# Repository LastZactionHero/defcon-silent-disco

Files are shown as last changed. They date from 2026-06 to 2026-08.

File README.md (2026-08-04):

# DEF CON Silent Disco Badge

A wearable silent disco. Every badge plays DJ mixes from its own memory
card to your headphones, runs a light show that matches the music, and can
**sync to a friend's badge over infrared** — same song, same moment, lights
flashing together.

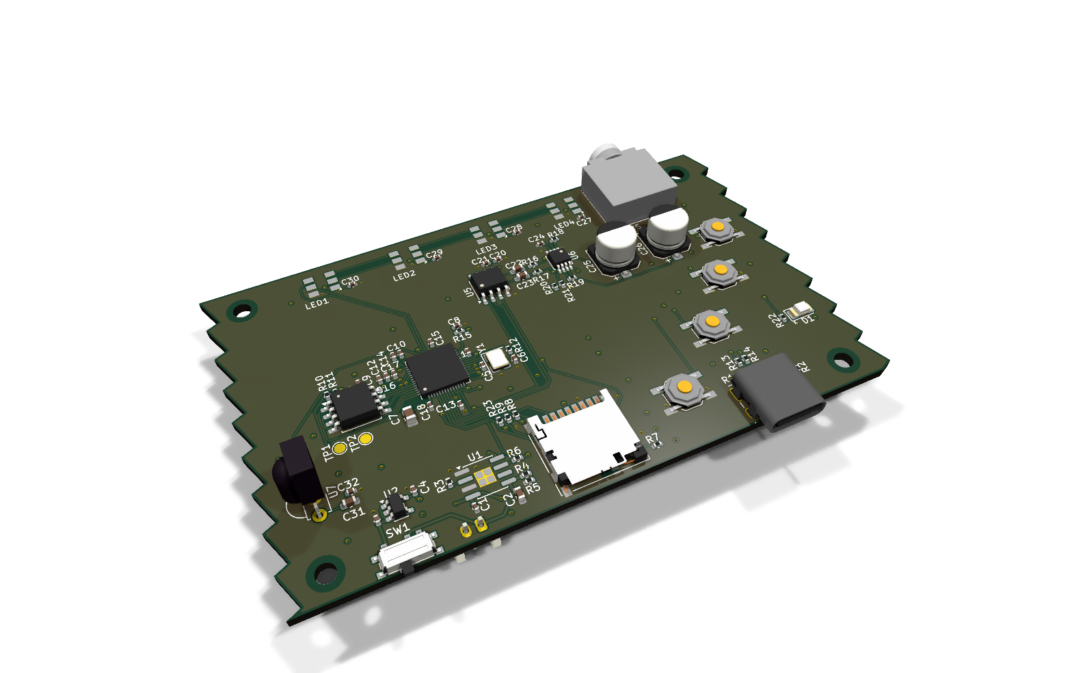
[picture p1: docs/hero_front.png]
Front


## How to use it

1. Flip the **power switch**. Plug **headphones** into the top jack.
2. It starts playing where it last left off.

| Button | Does |
|---|---|
| **CHANNEL** | Next channel. Each channel is one DJ mix that loops forever. |
| **VOL + / −** | Volume, 8 steps. Hold to ramp. Bottom step is mute. |
| **SYNC** | Join a friend — see below. |
| **CHANNEL, held 10 s** | Reset the badge. |

**Syncing:** press SYNC — your music pauses and the badge listens for up to
~25 seconds. Touch your badge's jagged edge into your friend's (they
interlock — that's what the teeth are for) and it will pick up their
broadcast, jump to **their channel at their exact spot**, and both badges
shimmer to confirm. Every badge announces itself over IR every ~10 seconds,
so there's nothing to press on the other badge.

**The light show** is picked by the music: each track gets its own color
theme and animation, and every ~10 seconds the badge plays a short glitter
burst. Synced badges glitter at the same instant.

## If something's wrong

**Red blinking LEDs** are an error code — count which LEDs are lit
(leftmost = 1):

| Code | Meaning | Try |
|---|---|---|
| 1 | No SD card | Reseat the card, power cycle |
| 2 | Card is empty | Put MP3s on it (see below) |
| 3 | Card unreadable | Re-format / re-copy the card |
| 4 | Playback keeps failing | Power cycle; check the battery |

**Sounds distorted, buzzy, or "like a modem"? Swap the battery.** A dying
battery warps the audio and confuses the SD card before anything else —
it looks like a bug, and it never is.

## The SD card

Just MP3 files in the root of the card — nothing else needed:

```
/ElAndEu_Duis.mp3      ← channel 1
/InYourEyes.mp3        ← channel 2
/Sepultura.mp3         ← channel 3   (alphabetical order = channel order)
```

- Encode at **96 kbps CBR, 44.1 kHz stereo** — `firmware/tools/prepare_card.sh`
  does this for you (and matches loudness across mixes).
- The **filename chooses the light show** — rename a file, get new colors.
- A 128 MB card holds about **2 h 54 m** (~29 min × 6 channels).

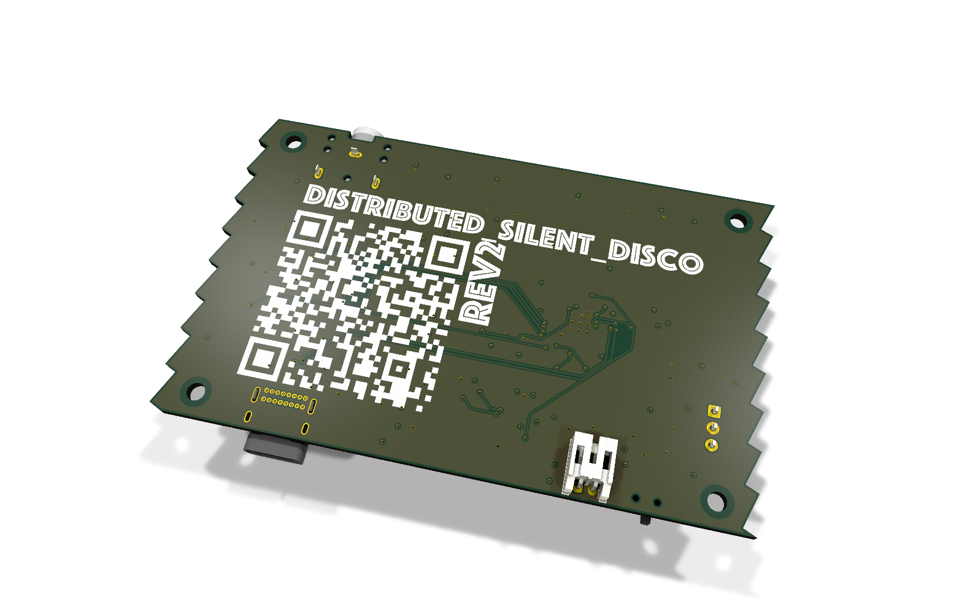
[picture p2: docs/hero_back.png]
Back


## Coming soon

- **Plain MP3-player firmware** — reflash the badge as a normal
  pocket music player (next/prev/pause instead of channels + sync). The
  code exists in this repo; a one-step installer is TODO.
- A **phone app that joins the disco by camera** — the glitter bursts
  encode the channel and timecode, so a phone can watch any badge and
  start playing along. Groundwork is shipped; app is TODO.

## Flashing / updating the firmware

Everything a badge runs is in this repo — [`firmware/`](firmware/) —
including the prebuilt firmware image
[`firmware-mp3-universal.uf2`](firmware/firmware-mp3-universal.uf2)
(one image works on every badge in the run).

**The easy way** (macOS/Linux, needs Python 3 and
[`mpremote`](https://docs.micropython.org/en/latest/reference/mpremote.html)):

```sh
git clone https://github.com/LastZactionHero/defcon-silent-disco.git
cd defcon-silent-disco/firmware
tools/flash_badge.sh        # follow the prompts: plug in, wait for DONE
```

The script does the whole thing — flashes the UF2, installs the badge
software, verifies it, reboots into the disco.

**By hand:** hold **BOOTSEL** while plugging in USB → a drive called
`RPI-RP2` appears → copy the `.uf2` onto it → the badge reboots → then copy
the `.py` files from `firmware/` onto it with `mpremote`. (macOS quirk: use
the script or `dd` — a plain Finder/`cp` copy of a UF2 can silently fail.
The drive *disappearing* is how you know the flash worked.)

Full details, including rebuilding the firmware from source:
[`firmware/README.md`](firmware/README.md).

## Under the hood

RP2040 · MicroPython + native MP3 decoder · 4× addressable RGB LEDs ·
IR sync · sawtooth interlocking edges · USB-C. The full technical story —
firmware architecture, the test suite, build-your-own instructions, and
the bring-up war stories — lives in [`firmware/README.md`](firmware/README.md).
KiCad sources are in [`defcon_badge/`](defcon_badge/), fab files in
[`defcon_badge/fab_rev2.zip`](defcon_badge/fab_rev2.zip).

## Credits

Designed and built by [**Pikkolo Assembly**](https://pikkoloassembly.com/).
Demo mixes are Creative Commons (attribution in `CREDITS.txt` on each
card). MP3 decoding by the Helix decoder via
[picomp3lib](https://github.com/ikjordan/picomp3lib).

MIT licensed — see [LICENSE](LICENSE). Go make a dance floor.

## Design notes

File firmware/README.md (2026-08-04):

# DEFCON Silent-Disco Badge — Firmware

MicroPython + native-C firmware for the RP2040 badge: a **silent disco** —
each badge streams MP3 "channels" from its microSD to headphones, shows a
per-track LED theme + animation, and can **sync channel and playback position
to a neighbouring badge over IR**, so groups dance to the same beat.

> **Read [`BADGE.md`](BADGE.md) for the hardware story** — pin quirks, the
> patched SD driver, and the bring-up findings this code depends on.

## What it does

- Plays **MP3** (96 kbps CBR, the native Helix decoder) from the card root.
  Channel = file, ordered alphabetically. A track **loops**; it never
  auto-advances — changing channel is always a deliberate press.
- **CHANNEL** (GP15): tap = next channel. **Hold 10 s = hard reset** (the
  field escape hatch — no laptop needed).
- **VOL+ / VOL−** (GP14/GP13): 8 steps, 6 dB each, top step −6 dBFS, true
  mute at 0. Auto-repeat when held.
- **SYNC** (GP12): join a neighbour. Playback pauses, the badge listens
  ~25 s for another badge's IR broadcast, then adopts **their channel and
  position** (latency-compensated to ~±70 ms). Times out back to where you
  were. Every badge broadcasts its own (timecode, channel) every 7–13 s.
- **LEDs**: the track *name* hashes to one of 16 themes × 12 animations × 4
  brightness levels (768 looks). Animation phase is locked to the playback
  clock, so **synced badges flash in step and stay in step**.
- **Crash resilience**: channel/position/volume persist to internal flash;
  a brownout resumes mid-set, rewound a few seconds. Faults blink **red
  binary** on the LEDs (LED1 = LSB): 1 = no SD card, 2 = no playable tracks,
  3 = SD mount raised, 4 = playback failing. Every error path stays alive
  and keeps hold-to-reset working.

## Provision a badge (one command)

```sh
tools/flash_badge.sh          # one badge: BOOTSEL → flash → deploy → verify
tools/flash_badge.sh --loop   # the whole pile, badge after badge
```

Flashes `firmware-mp3-universal.uf2` — one image that boots **both** flash
vendors in the manufacturing run (Winbond and Macronix; the custom boot2
discriminates at boot) — then deploys the runtime and verifies imports on
the badge. macOS gotcha handled inside: a plain `cp` of a UF2 **silently
fails**; the script uses `dd` + `sync` and treats *the RPI-RP2 volume
disappearing* as the success signal.

## Prepare a card

```sh
tools/prepare_card.sh "/Volumes/CARD" set1.wav set2.flac set3.mp3
```

Encodes to the shipping format and prints a **preview of each track's LED
look** (the preview imports the real firmware code, so it cannot drift).
Two choices in the recipe are load-bearing — do not "improve" them:

- **CBR**: IR sync seeks by byte offset, which is only linear in time for
  constant bitrate. VBR = everyone syncs to the wrong bar.
- **44.1 kHz**: the DAC has no reconstruction filter; a lower sample rate
  folds ultrasonic images *down toward* the audible band.

Also: EBU R128 loudness normalisation (−16 LUFS) so channel-surfing between
DJs doesn't whiplash, metadata/art stripped, and a 128 MB budget check
(~2 h 54 m total at 96 k). **Track filename = channel order and LED look.**

Got a mix in an app that can play but not export? `tools/record_mix.sh`
captures the Mac's own audio output (loopback via BlackHole) to a lossless
WAV master and encodes the badge MP3 from that.

## Tests

```sh
python3 tools/host_tests.py
```

Runs the **real firmware modules** on the host: the IR ISR + decoder against
synthetic TSOP edges (AGC stretch, mark distortion, measured 60 Hz ambient
noise), CBR seek/wrap math, persistence-slot recovery incl. torn writes,
every LED invariant (no mid-range PWM, ≤1 white/theme, slot determinism,
flash-rate safety), and the volume ladder. Run it before deploying changes.

## Files

| File | Purpose |
|---|---|
| `config.py` | **Pin map + tunables** (single source of truth, with history) |
| `main.py` | Entry point — boots `disco`; alternates commented inside |
| `disco.py` | The silent-disco program (channels, LEDs, sync, persistence) |
| `irsync.py` | IR timecode protocol: NEC-style TX + hard-IRQ RX |
| `wavplayer.py` | Async player engine (MP3+WAV, seek, stall watchdog) |
| `mp3player.py` | Plain player (also: `mount_sd`/`find_tracks` used by disco) |
| `linktest.py` | IR link bring-up tools: `beacon()` / `scope()` / `raw()` |
| `dsp.py` | Viper DSP hot path (volume + LSBJ reframe + peak) |
| `sk9822.py` | Bit-banged SK9822 LED driver (viper/SIO fast path) |
| `buttons.py` | Debounced buttons: auto-repeat + tap/hold semantics |
| `sdcard.py` | **Patched** SD-SPI driver (CMD8-glitch workaround) |
| `audiolab.py` | Audio diagnostics (tone/sweep/ZEROS/CLKOFF/FREQ modes) |
| `jukebox.py`, `lights.py`, `selftest.py` | Earlier player + LED modes + HW test |
| `tools/flash_badge.sh` | One-command badge provisioning (`--loop` for batches) |
| `tools/prepare_card.sh` | Mix → badge-format MP3 + look preview + budget check |
| `tools/record_mix.sh` | Record the Mac's audio output to badge format |
| `tools/host_tests.py` | Host regression suite (real modules, no hardware) |
| `tools/card_preview.py` | LED look preview for a set of filenames |
| `tools/build_firmware.sh` | Rebuild the firmware UF2 (MP3 module + boot2) |
| `boot2/` | Custom second-stage bootloaders (universal + Macronix) |
| `cmodules/mp3/` | Native MP3 decoder C module (Helix / picomp3lib) |

## Recovery / field notes

- **Sounds like a modem / horrible hum, or the card stops reading?  Fresh
  battery first.**  A sagging AAA amplitude-modulates the DAC (its output is
  ratiometric to the rail) and breaks SD init -- both look exactly like
  firmware bugs.  USB power masks it, so a badge that "tests fine on the
  laptop" can still be a dead battery.  Pack spares.
- **Hold CHANNEL at power-on** → skip autostart, drop to the REPL.
- **Hold CHANNEL 10 s while running** → hard reset (works on error screens too).
- Red binary blink = error code (see above). Code 1: reseat the SD card.
- `mpremote` cannot take the REPL while audio is decoding — send **one**
  Ctrl-C over raw serial first, or power-cycle, then deploy. (Spamming
  Ctrl-C mid-playback has wedged boards.)
- Rebuilding the UF2 needs the **xPack** ARM toolchain on PATH first —
  Homebrew's `arm-none-eabi-gcc` has no newlib and fails at boot2 link:
  `export PATH="$HOME/dev/xpack-arm-none-eabi-gcc-14.2.1-1.1/bin:$PATH"`

## Known limitations / respin notes

- **Writes to SD are unproven** — state persists to *internal* flash instead;
  treat the card as read-only in the field.
- **No MISO pull-up** fitted: the schematic's R8/R9/R23 pull-ups terminate on
  a mis-named power net (`+3.3V` vs `+3V3`) with no source. One symbol rename
  fixes it next spin; until then SD SPI stays at the verified 4 MHz.
- **No DAC reconstruction filter** → the supply-buzz floor, and the reason
  encoding stays at 44.1 kHz. Next spin: series R + shunt C on each DAC
  output, and a local bypass at the TDA1308 (it has none).
- **IR range is short by construction**: the emitter is ~13 mA straight off a
  GPIO (12 mA pad drive recovers the design current). A transistor driver at
  100 mA+ next spin would give real range. Badges sync reliably at
  face-to-face distances; the jagged board edges interlock to align
  emitter↔receiver.
- **276 MHz overclock** (RP2040 is rated 133 MHz) is load-bearing for MP3
  decode *and* chosen for audio-noise pitch; verified stable on the bench
  units. `250_000_000` is the tested fallback if a unit is flaky.
- The VM freezes during internal-flash writes (XIP suspend) and the ~68 ms
  IR send — the firmware spaces them apart and the emit watchdog logs any
  >150 ms gap with blame, so a stutter report is diagnosable from the console.

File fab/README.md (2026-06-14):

# Fabrication package — DEF CON silent disco badge

## Spec at a glance
- **Outline:** 86 × 54 mm, 3 mm rounded corners (credit-card form factor)
- **Layers:** 4-layer (F.Cu, In1.Cu = GND, In2.Cu = +3V3, B.Cu)
- **Components:** 80 SMD + THT, all on F.Cu (top side)
- **Hole sizes:** see `gerbers/defcon_badge.drl` (Excellon)
- **Mounting:** 4× M2.5 holes (2.7 mm dia) at corners
- **Connectors:** USB-C (J10), JST-PH 2 mm battery (J11), 3.5 mm audio jack (J20), microSD (J31 — currently off-board, pending iter 11 layer flip), SAO 2×3 (J30), Dev/SWD 1×5 (J33), UART 1×3 (J32)
- **Hero parts:** RP2040 (U3), 4× SK9822 RGB LEDs (LED20-23), TP4056 charger + ME6211 LDO, TM8211 DAC + FDA1308 headphone amp, TSOP4838 IR receiver + 940 nm IR LED

## Files
- `gerbers/` — Gerber RS-274X for all layers + Excellon drill file
- `defcon_badge-pos.csv` — pick-and-place position file (KiCad format, mm)
- `defcon_badge-bom.csv` — grouped BOM with MPN + LCSC where assigned

## Caveats
This package was generated mid-iteration by the autonomous design loop
(see `HARNESS.md`). Known gaps before fab:
- No copper routing yet — all nets are unconnected ratsnest. The board
  is currently a parts-placed PCB. Routing pass (auto or hand) required.
- ERC reports ~71 schematic violations (mostly `label_dangling`,
  `power_pin_not_driven`, off-grid endpoints). Most are cosmetic /
  pre-PWR_FLAG issues, none change topology, but DRC will refuse fab
  until cleared.
- J10 USB-C pads carry no net assignments — they sit in the PCB as a
  raw footprint. Iter 14+ will wire them.
- J31 microSD remains off-board (no front-side space; iter 11 plans
  layer-flip to B.Cu).

## Regenerating
```sh
tools/render_pcb.sh                    # SVG/PNG renders to renders/
kicad-cli pcb export gerbers ...       # see Makefile or this README
```

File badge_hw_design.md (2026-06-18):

# Silent Disco Badge — Hardware Design v0.1

Target: ~$2.50 BOM ex-battery/SD at qty 500. 2-layer, standard spec (8/8 mil floor — stays in APCT standard pricing). Single-sided placement if layout allows; buttons and switch are the only things fighting for the front.

---

## Power tree

```
USB-C 5V ──→ TP4056 ──→ BAT+ (503450 LiPo, protected cell)
                              │
                        SS-12D00 slide switch
                              │
                          ME6211C33 ──→ 3V3 rail (everything)
```

- **TP4056** (ESOP-8, LCSC C16581): RPROG = 2.4 kΩ → 500 mA charge (0.5C on 1000 mAh). CE tied high. CHRG̅ (pin 7) → GP18 via 100k pullup to 3V3 so firmware can show charge state on the LEDs — no dedicated status LEDs.
- **Protected cell** — skip DW01/FS8205, the cell's PCM covers it.
- No load-sharing path. System always runs off the battery node; charging-while-playing slightly confuses TP4056 termination. Acceptable for a badge; note in docs "charges fastest when off."
- **ME6211C33M5G** (SOT-23-5, C82942): 1 µF in/out. 500 mA rated, system peak ~150 mA, fine.
- **VBAT sense:** 100k/100k divider → GP26/ADC0. Always connected; 16 µA standing drain is negligible vs self-discharge.
- **USB-C:** 16-pin mid-mount (e.g. GCT USB4520 or HQB equivalent TYPE-C-31-M-12). 5.1 kΩ on each CC to GND (UFP). VBUS → TP4056 only — do not feed VBUS to the 3V3 rail.

## RP2040 core

- **RP2040** (C2040) + **W25Q16JVUXIQ** 2 MB QSPI flash (C2843335). 2 MB is plenty: firmware + channel table; all audio lives on SD.
- **Crystal:** 12 MHz 3225, stock tolerance (software trim handles drift), 15 pF load caps, 1 kΩ series resistor per the RP2040 hardware design guide.
- VREG_VIN ← 3V3, VREG_VOUT → DVDD pins with 1 µF. 100 nF at every IOVDD pin, 1 µF bulk ×2.
- USB D+/D− through 27 Ω series resistors to the connector. No external pullups (internal).
- RUN: 10 kΩ to 3V3. No reset button.
- **BOOTSEL button:** tactile from flash CS to GND via 1 kΩ, back side of board. Needed for first flash and unbrick; after that, track loading is USB MSC so users never touch it.

### GPIO map

| GPIO | Function | Notes |
|---|---|---|
| GP0/GP1 | UART0 TX/RX | debug header, 3-pin |
| GP2 | SD SCK | SPI0 |
| GP3 | SD MOSI | SPI0 |
| GP4 | SD MISO | SPI0 |
| GP5 | SD CS | |
| GP6 | I2S DIN → DAC | PIO0 |
| GP7 | I2S BCK | PIO0, keep 6/7/8 contiguous for PIO side-set |
| GP8 | I2S WS (LRCK) | PIO0 |
| GP9 | IR_TX | via S8050, 68 Ω, 38 kHz PIO carrier |
| GP10 | LED SCK | SPI1, SK9822 clock |
| GP11 | LED MOSI | SPI1, SK9822 data |
| GP12 | BTN_CH | internal pullup, switch to GND |
| GP13 | BTN_VOL_UP | " |
| GP14 | BTN_VOL_DN | " |
| GP15 | IR_RX | TSOP output, active low |
| GP16 | SAO SDA | 4.7k pullups |
| GP17 | SAO SCL | " |
| GP18 | CHRG̅ sense | from TP4056 |
| GP19 | BTN_SYNC | internal pullup, switch to GND |
| GP26 | ADC0 VBAT | 100k/100k divider |

## Audio chain

```
RP2040 PIO I2S → TM8211 DAC → 10µF coupling → TDA1308 → 220µF coupling → PJ-320A jack
```

- **TM8211** (SOP-8) — the Shenzhen PT8211 clone, rated 2.0–5.5 V so it's happy at 3.3 V. **Do not sub a genuine PT8211 without checking — PT8211 datasheet wants ~5 V.** TM8211 takes LSBJ-format 16-bit I2S (justified, not standard I2S — firmware note: PIO program shifts WS timing by one BCK vs standard I2S).
- 100 nF + 10 µF decoupling at DAC Vcc.
- **TDA1308** (SOP-8) headphone amp, runs at 3.3 V:
  - Inputs: 10 µF coupling caps from DAC outs, 47 kΩ input resistors.
  - Gain: 100 kΩ feedback / 47 kΩ input ≈ 2.1×. Loudness headroom is the flagged risk — leave feedback Rs as discrete 0402s so gain is a resistor swap, not a respin.
  - Virtual ground: 10k/10k divider + 10 µF to the VREF pin.
  - Outputs: **220 µF / 6.3 V** electrolytic or large MLCC per channel to the jack. 220 µF into 32 Ω → −3 dB at 23 Hz; into cheap 16 Ω buds → 45 Hz. Don't cheap to 100 µF; this is a disco.
- **PJ-320A** 3.5 mm TRRS-style SMD jack — wire as TRS stereo, leave sleeve-detect unconnected.
- Layout: keep DAC/amp and their ground pour away from the SK9822 data lines and the IR LED driver (30 mA pulsed bursts); star the audio ground back at the LDO.

## Optical tap-to-sync (replaces RF)

Badges sync by touching face-to-face. No radio — at DEFCON specifically, any unauthenticated RF beacon **will** be spoofed for sport within the hour, and signing packets drags crypto/key management onto a $5 badge. Physical contact is proximity-authenticated for free, and the social mechanic ("we drifted — tap me") is the feature.

- **Link:** 940 nm IR LED + **TSOP4838**-class 38 kHz demodulating receiver (~$0.22 pair + driver). Not a bare photoresistor/phototransistor: LDRs are far too slow (tens of ms), and a bare PT makes you own the analog ambient-rejection problem in a room full of strobes. The TSOP is IR-remote tech — carrier-filtered, AGC'd, bulletproof, trivial firmware (NEC-style bursts).
- IR LED driven by S8050/2N7002 from **GP9**, 68 Ω → ~30 mA pulsed. TSOP out → **GP15** (active low).
- **Placement:** LED and receiver mirror-symmetric about the badge's vertical centerline, front face, so two badges pressed face-to-face cross-align LED↔receiver automatically in both directions. Badges themselves shade the link from ambient at contact.
- **Protocol:** every badge chirps `{version:u16, epoch_ms:u48, table_hash, CRC}` (~12 B, NEC-style framing, TSOP AGC needs burst gaps) every ~2 s. Hearing a higher version → adopt clock + version, pulse the SK9822s in unison with the peer — that shared flash is the sync confirmation and the moment of delight. No button, no mode: touch = sync.
- **Same-version contact → average the two clocks** (slew-limited to ±150 ms per contact so a hacked badge can't yank the network). This is what makes peer taps *maintain* sync between staff passes — pairwise averaging is a consensus algorithm; clusters that tap converge to their mean. Without this, only organizer contact corrects drift.
- **Software drift trim:** on repeat contact with the same peer (or any correction event), estimate own ppm error from accumulated offset and trim the tick rate. Two taps gets a badge from ±30 ppm to single digits — makes the ±10 ppm crystal optional rather than required.
- **Root of trust:** a couple of organizer badges are the only ones that increment `version` (long-press combo). Everyone else propagates. Staff circulating keeps the room coherent.
- **Drift budget (be honest about this):** stock 20–30 ppm crystals → up to ~200 ms relative drift/hr between two badges worst case, but software ppm trim calibrates out static offset after 2–3 taps, leaving only temperature drift (small indoors). Stock crystal is fine — don't pay for tighter tolerance; trim fixes what tolerance specs, and nothing cheap fixes tempco. Flash sync is cluster-coherent — groups that tap each other stay locked, which is the aesthetic anyway. Friends pulse together.

## LEDs

- **4× SK9822 (5050)**, chained, SPI1 clock+data. (Switched from the on-hand EC20 2020 to the larger 5050 for a brighter, more decorative disco look — see PCB footprint badge:LED_SK9822_5050, datasheet-verified pinout 1=DIN 2=CIN 3=GND 4=VDD 5=COUT 6=DOUT.) 5 V part driven at 3.3 V logic and 3.3 V supply — SK9822 runs visibly fine at 3.3 V supply with slightly shifted color balance; data threshold is met since VDD = logic rail. ~10 nF per LED.
- Brightness budget: global brightness register capped at ~25% in firmware. 4 LEDs full white at 3.3 V would eat the battery and blind people at eye level on a lanyard.

## Buttons / switch

- 4× **TS-1187A** 6 mm tactile (CH / VOL+ / VOL- / SYNC; silkscreen labels), to GND, internal pullups. Front face, 2×2 grid (CH·SYNC top, VOL+·VOL- bottom) — a single row of 4 doesn't fit between USB-C and the corner mounting hole.
- 1× **MSK-12C02 / SS-12D00** slide power switch.
- 1× BOOTSEL tactile, back side.

## SAO header

- Standard SAO v1.69: 2×3 female header, 3V3 / GND / SDA / SCL / GPIO×2 → use GP20/GP21 for the two SAO GPIOs (add to GPIO map). Costs a connector, buys DEFCON cred.

## Connectors summary

USB-C 16P · PJ-320A · microSD push socket (e.g. TF-PUSH, ~$0.10) · JST-PH 2-pin for battery · SAO 2×3 · 3-pin debug UART (unpopulated).

---

## BOM (qty 500, est.)

### Active / connectors / electromech

| Ref | Qty | Part | Package | Est. |
|---|---|---|---|---|
| U1 | 1 | RP2040 | QFN-56 | $0.80 |
| U2 | 1 | W25Q16JVUXIQ 2 MB QSPI flash | USON-8 | $0.20 |
| U3 | 1 | TM8211 stereo DAC (PT8211 clone, 2.0–5.5 V) | SOP-8 | $0.15 |
| U4 | 1 | TDA1308 headphone amp | SOP-8 | $0.25 |
| U5 | 1 | TP4056 Li-ion charger | ESOP-8 | $0.08 |
| U6 | 1 | ME6211C33M5G LDO | SOT-23-5 | $0.03 |
| U7 | 1 | IRM-H638T / TSOP4838-class 38 kHz IR RX | side-view | $0.15 |
| Q1 | 1 | S8050 NPN (IR LED driver) | SOT-23 | $0.01 |
| D1 | 1 | 940 nm IR LED | 0805 side-fire | $0.02 |
| LED20–23 | 4 | SK9822 | 5050 | switched from EC20 2020 for brightness |
| Y1 | 1 | 12 MHz crystal, stock tol. | 3225 | $0.08 |
| J1 | 1 | USB-C 16P mid-mount | — | $0.10 |
| J2 | 1 | PJ-320A 3.5 mm jack | SMD | $0.08 |
| J3 | 1 | microSD push socket | — | $0.10 |
| J4 | 1 | JST-PH 2P (battery) | SMD RA | $0.04 |
| J5 | 1 | SAO 2×3 female header | THT | $0.06 |
| J6 | 1 | debug UART 1×3 | THT | DNP |
| SW1–3 | 3 | TS-1187A tactile (CH, V+, V−) | SMD | $0.09 |
| SW4 | 1 | BOOTSEL tactile | SMD | $0.01 |
| SW5 | 1 | MSK-12C02 slide power switch | SMD | $0.03 |

### Passives (0402 unless noted)

| Value | Qty | Where |
|---|---|---|
| 27 Ω | 2 | USB D+/D− series |
| 68 Ω | 1 | IR LED current set |
| 1 kΩ | 3 | crystal series, BOOTSEL, Q1 base |
| 2.4 kΩ | 1 | TP4056 PROG (500 mA) |
| 4.7 kΩ | 2 | SAO I2C pullups |
| 5.1 kΩ | 2 | USB-C CC |
| 10 kΩ | 3 | RUN pullup, amp vground divider ×2 |
| 47 kΩ | 2 | amp input |
| 100 kΩ | 5 | amp feedback ×2, VBAT divider ×2, CHRG̅ pullup |
| 15 pF | 2 | crystal load |
| 10 nF | 4 | SK9822 local |
| 100 nF | 10 | IOVDD ×6, DAC, TSOP, TP4056, misc |
| 1 µF | 5 | VREG, DVDD, LDO in/out, bulk |
| 10 µF | 6 | DAC bulk, DAC→amp coupling ×2, vground, charger in/out |
| 220 µF 6.3 V | 2 | headphone output coupling (electrolytic) |

### Rollup

| Group | Est. |
|---|---|
| ICs | $1.66 |
| Connectors | $0.38 |
| Electromech (buttons/switch) | $0.13 |
| Crystal | $0.08 |
| Passives | ~$0.25 |
| **Board parts subtotal** | **~$2.50** |
| 503450 1000 mAh protected LiPo | $1.80 |
| 512 MB–1 GB bulk microSD | $0.70 |
| **All-in (ex-PCB)** | **~$5.00** |

~58 placements, 15 unique passive values, all 0402-or-larger / SOP / SOT — deliberately easy on the Lumen line. Only THT items are the SAO header and (optional) battery connector and debug UART.

Verified LCSC C-numbers: RP2040 C2040, W25Q16 C2843335, TP4056 C16581, ME6211C33 C82942. Everything else — verify at order time, don't trust from memory.

---

## v1 validation order (before layout freeze)

1. **Audio pipeline on a Pico + TM8211 breakout:** minimp3 decode of 192k CBR + SPI SD streaming + PIO I2S, both cores. This is the only real firmware risk.
2. **TDA1308 loudness** into 16 Ω earbuds at 3.3 V, gain 2×. If quiet, bump gain to 3–4× and check clipping.
3. **IR tap link:** two Picos + TSOP/IR LED pairs face-to-face — confirm clean decode at contact and ~2 cm, confirm rejection with a strobe pointed at it. Then measure real crystal drift between two boards over 2 hrs to size the re-tap interval honestly.
4. SK9822 at 3.3 V supply — confirm acceptable color at 25% brightness.

## Layout notes

- Badge outline is free real estate — front face: 4 buttons (2×2 grid) bottom edge, jack top or bottom edge (cable hangs down → bottom), LEDs spread across front, art everywhere else.
- All silicon on back except LEDs if you want a clean front. Single-side placement target: put LEDs on back firing through FR4 windows? No — reverse-mount adds cost; two-side placement is fine, it's your own line.
- IR LED + TSOP front face, mirror-symmetric about vertical centerline (face-to-face mating cross-aligns them). Audio lower left, USB/charge lower right, SD back center.

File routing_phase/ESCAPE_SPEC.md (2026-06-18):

# ESCAPE_SPEC — QFN escape planner (R3, the central new tool)

`routing_phase/tools/escape_planner.py`. The phase that never existed in pass 1. Escapes every
QFN signal pin to OPEN space outside the pin field BEFORE bulk routing — so via_in_pad==0 by
construction and the bulk router starts from a relieved ring, not a jammed pad field.

## Proven foundation (de-risking result, 2026-06-18)
KRT's `qfn_fanout` (shipped, never used in pass 1) escaped all **43** U3 signal pads with **0 vias**
(escapes on the mounted F.Cu layer, two-segment 45° stubs, side-classified bottom 12/left 8/right 11/
top 12, "No endpoint collisions"). Applied via `krt_bridge` → **via_in_pad==0** confirmed.

**The residual it surfaced — and the reason escape_planner is more than a qfn_fanout wrapper:** at
0.40mm pitch the single-layer 45° fan stubs sit only ~0.283mm apart (pitch/√2) → with 0.15mm tracks
the gap is ~0.133mm < the 0.15mm clearance rule → **54 clearance DRC errors**. One layer cannot hold
43 escapes at this pitch. qfn_fanout's own note: "route.py --grid-step 0.05 --clearance 0.05 ... the
default will fail." So escape_planner must SPREAD ACROSS LAYERS.

## Design: multi-layer alternating escape (the fix)
Halve the per-layer escape density so adjacent same-layer stubs clear the 0.15mm rule.
- Per side, walk pads in index order and ALTERNATE escape layer: even pads escape on **F.Cu**
  (qfn_fanout direct stub, no via), odd pads escape via a **B.Cu dog-bone** (short F.Cu stub off the
  pad → off-pad via in the empty annulus → B.Cu stub outward). This doubles per-layer pitch to
  ~0.566mm → ~0.416mm gap > 0.15mm → DRC-clean.
- The off-pad via stays via_in_pad-free (via is in the open annulus, never on the pad). Placement is
  EASY because escape-first runs on EMPTY copper (the annulus is clear — pass 1's congestion was
  caused by routing INTO a filled field; here there's nothing to collide with).
- Power/GND QFN pads (+3V3/+1V1/GND) are NOT escaped here — they drop straight to their plane in R6
  fanout (excluded via `--nets "*" "!GND" "!+3V3" "!+1V1"`). The EP and its 9 GND vias are untouched.
- MONOTONE ordering per side (no two same-layer escapes cross; preserve pad order at the ring) — this
  is what makes it read hand-designed.

## Algorithm
1. Run KRT `qfn_fanout.py --component U3 --layer F.Cu --width 0.15 --clearance 0.15 --nets <F.Cu set>`
   for the EVEN pads → KRT-format board; `krt_bridge.extract_routing` → F.Cu escape tracks.
2. For the ODD pads, build B.Cu dog-bones directly on `geom_route`: F.Cu stub pad→via_pos (short,
   along the outward radial), `add_via` at via_pos (validated clear by the `_pt_clear`/`_seg_dist`
   geometry check — reused from the deleted fix_signal_vias as a reference helper), B.Cu stub
   via_pos→ring-exit. Sweep radius in the empty annulus until clear (nearly always first try).
3. Apply ALL escapes via `krt_bridge.apply_routing`/`geom_route` (pcbnew writer), one save.
4. Emit `escape_plan.json`: per pin {refdes_pin, net, native_side, escape_layer, mode: vialess|dogbone,
   via:[x,y]|null, escape_point:[x,y,layer]}. This is the HAND-OFF CONTRACT to R4/R5 — the bulk router
   uses `escape_point` as the net's effective source terminal and never touches the pad field again.
5. Reserve a KEEPOUT ring (a `(keepout (vias not_allowed))` rule area around U3 out to ~r_outer) so R6
   plane fanout can't re-fence the escapes.

## Inputs / guardrails
- Read via `geom_route.safe_board`; design rules from the netclass (don't hardcode); single-writer.
- Does NOT route to destinations (only to the ring). Does NOT touch the EP/planes' fill. Never places
  a via that HitTests a pad (the invariant). One LoadBoard+SaveBoard (pcb_runner).
- Also escape the microSD J31 and any other dense connector the same way if it blocks (start with U3).

## Exit gate (R3): every QFN signal pin escaped to open space; via_in_pad==0; escapes DRC-clean
(multi-layer); no signal on an inner plane; determinism passes; render shows a clean radial pattern.

## Tuning fallbacks (the R3 escalation ladder)
qfn_fanout-multilayer → manual escape-corridor seeding (hand-place a few hard stubs) → push to R2
GPIO remap (move the pin so it doesn't need a cross-side escape) → hand-off. Also: if 0.4mm pitch is
truly too tight even multi-layer, route the QFN-local nets with `route.py --grid-step 0.05
--clearance 0.05 --track-width 0.15` (qfn_fanout's own suggestion) scoped to just U3's nets.

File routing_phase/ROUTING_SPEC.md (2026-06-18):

# ROUTING_SPEC — Pass-2 architecture (escape-first, KRT-full-toolbox)

How the pass-2 system works. The big change vs pass 1: PLAN before ROUTE, and invoke KRT's
existing escape/bus/aesthetic capabilities instead of rebuilding them.

## Architecture
```
  geom_route (pcbnew authoritative copper) ──► measure_route (DRC-backed metrics) ──► gates
       │              ▲
       ▼              │
  route_db (incremental, stable pad-set signature)
       │
  PLAN (Workflow, run once) ───────────────────────────────► EXECUTE (loop)
    R2 gpio_reassigner  (crossing-min, schematic, approval)     R5 bulk singleton route + beautify
    R3 escape_planner   (qfn_fanout + B.Cu dogbones)            R6 plane fanout LAST + pour + verify
    R4 bus_topology_planner (chip_boundary/bus_detection)
       └─ emit escape_plan.json / bus_plan.json / gpio_remap.json (frozen artifacts)
                                          │
                                          ▼ (KRT = solver only; pcbnew = sole writer)
                          krt_bridge: KRT solves → extract (KRT kicad_parser) → re-apply via pcbnew
```

## KRT full-toolbox integration map (the pass-1 "missing tools" that already exist)
Run KRT via the venv; reach output ONLY through `krt_bridge` (KRT writes net NAMES, KiCad 10 needs
CODES). All KRT runs single-thread/deterministic.
- **Escape (R3):** `qfn_fanout.py --component U3 --layer F.Cu --width 0.15 --clearance 0.15 --nets
  "*" "!GND" "!+3V3" "!+1V1"` → 0-via on-layer escapes (PROVEN). escape_planner adds the B.Cu dogbone
  for the alternate pads (ESCAPE_SPEC).
- **Bus/topology (R4):** `bus_detection.py` (group nets into buses), `chip_boundary.py` (perimeter
  unroll → crossing-minimal order: two nets cross iff source/target orderings invert), and
  `route.py --bus --guide-corridor --guide-corridor-layer/-spacing` → constant-pitch bundles.
- **Aesthetics (R5):** the Rust `grid_router` knobs — `--turn-cost` (straighter), `--via-cost`/
  `--via-proximity-cost` (fewer/structured vias), `--track-proximity-*` (consistent spacing),
  cross-layer track attraction (stack traces on adjacent layers). Pass 1 ran defaults.
- **GPIO remap (R2):** `chip_boundary.py` to score crossings; Hungarian assignment (as in KRT
  `target_swap.py`); write back via KRT `schematic_updater.py` + `--swappable-nets`/`--schematic-dir`.
- **Bulk (R5):** `route.py` with the aesthetic knobs + `--rip-existing-nets PATTERN` (SMALL sets only;
  global rip-up is pathologically slow on this board). At 0.4mm-pitch QFN-local nets use
  `--grid-step 0.05 --clearance 0.05`.
- Do NOT use `route_planes.py`/`route.py` to place vias on pads (the pass-1 via-in-pad source) — and
  do NOT use KRT's writer.

## Pipeline (route_pipeline.py = a phase DAG, not the old flat chain)
R0 setup → R1 stackup → R2 gpio (opt) → **R3 escape** → **R4 bus** → R5 bulk singletons → R6 plane
fanout LAST + pour. Each stage: pcb_runner-isolated, records into route_db, independently re-runnable.
The old order (plane-fanout-then-bulk, no escape, bus lumped in bulk) is the structural flaw being
fixed — plane fanout MOVED TO LAST is the single most important change.

## Metric engine (measure_route.py — KEPT; fill the existing None placeholders)
Already emits: completion_pct (vs frozen baseline.json), unconnected + divergence guard, shorts,
drc_errors + drc_by_type, track/via counts + per-layer length, **via_in_pad** (HitTest), usb skew/
paired, acute_angles, off_axis_segments, zones_filled_ok. NEW tools fill the placeholders:
bus_pitch_var (R4), determinism_ok (route-twice). Per-phase PRIMARY metric declared in STATE.md
(R3: via_in_pad + escaped-pin count; R4: bus_pitch_var; R5: completion_pct).

## Incremental model (route_db.py — KEPT)
Nets keyed by stable pad-set signature (sorted REFDES-PADNUM, not the churning net name). A GPIO
remap (R2) changes the signature only for moved nets → only those re-escape/re-route. Determinism
gate = route-twice → identical fingerprint.

## Determinism + aesthetics are first-class
Route-twice gate wherever copper exists. Because escape (R3) and buses (R4) are PLANNED before bulk,
the structured-via + constant-pitch look is baked in — there is no "aesthetic pass at the end" to skip.

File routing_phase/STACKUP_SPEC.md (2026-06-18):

# STACKUP_SPEC — D1 4-layer rework (committed BEFORE implementation)

The board is 4-copper but everything physical is a **2-layer RP2040 dev-board porting artifact**:
thickness 1.0mm, NO real stackup/dielectric block, In1=full GND + In2=full +3V3 copied from the
dev board, a loose F.Cu GND zone with no B.Cu counterpart, all 3 zones unfilled. The user
directed reworking this. Do it as a tool: `routing_phase/tools/rework_stackup.py` (pcbnew,
single-writer). Numbers below are from the engine-architecture research (JLCPCB published
JLC04161H-3313 data + Hammerstad/IPC-2141 microstrip; verify USB width in JLC's calculator at order).

## Target stackup — JLC 4-layer 1.6mm (JLC04161H-3313)
| Layer | Assignment | Copper | Dielectric to next |
|---|---|---|---|
| F.Cu  | signal + GND fill (USB pair, most signals) | ~1oz fin. | 3313 prepreg **0.0994mm**, Dk 4.1 |
| In1.Cu | **solid GND plane, unbroken** (return reference for both signal layers + USB) | 0.5oz | FR-4 core **1.265mm**, Dk 4.6 |
| In2.Cu | **+3V3-dominant pour** + a little slow signal where F/B congests | 0.5oz | 3313 prepreg **0.0994mm**, Dk 4.1 |
| B.Cu  | signal + GND fill (near-empty today → secondary signal layer) | ~1oz fin. | — (board ≈1.6mm) |

Rationale: In1 solid GND is the reference that matters (return current + USB). In2 as a full +3V3
plane is wasteful (only 47 +3V3 pads, ~150mA, ME6211 rated 500mA, local decoupling at each IC) —
demote it to a +3V3-dominant *mixed* pour that doubles as routing relief, but keep +3V3 continuous
under U3 (RP2040), U2 (flash), U11 (LDO). F.Cu/B.Cu GND pours stitched to In1 give shielding/return.

## Zone plan (after deleting the 3 artifact zones)
- **In1.Cu**: GND, full solid plane, outline inset ~0.3mm (min copper-edge clearance), priority 0.
- **In2.Cu**: +3V3 dominant pour over the digital/power region, priority 0; + optional secondary
  GND pour priority 1 in +3V3-free areas (return stitching).
- **F.Cu**: GND pour in routing gaps, priority 0, stitched to In1.
- **B.Cu**: GND pour in routing gaps, priority 0, stitched to In1.

## Impedance / widths
- **USB D+/D-** (the ONLY controlled-impedance net): edge-coupled microstrip on F.Cu over In1 GND
  through the 0.0994mm 3313 prepreg → **width 0.17mm, gap 0.13mm** ≈ 89Ω diff (0.15mm gap ≈ 91.5Ω).
  Replace the stored 0.8mm (a 2-layer value). Keep tightly coupled, length-matched, over solid In1
  GND with NO plane split under the pair; the two 27Ω series Rs (R3/R4) stay in-line.
- **Default signal 0.15mm** over In1 GND ≈ 55Ω single-ended — fine for QSPI/I2S/SK9822/SD/etc.
  (no controlled impedance required). No change except USB.
- Power widths: see `routing_rules.md` (VBUS/BAT/BAT_SW 0.5mm, IR drive 0.3mm, +1V1 0.3mm, audio
  output 0.3mm; +3V3/GND ride planes via taps).

## Rework steps (rework_stackup.py — pcbnew, writer-lock-guarded)
1. Set board thickness 1.0→1.6mm (`SetBoardThickness(pcbnew.FromMM(1.6))` or setup thickness).
2. Write a real physical stackup block for JLC04161H-3313 with the dielectric heights/Dk above.
   (Hand-writing the stackup via the Python API can trip the wx PROPERTY_ENUM asserts — prefer the
   board-setup preset if interactive; otherwise write the `(stackup ...)` block carefully and verify
   the board still loads via `kicad-cli pcb drc`.)
3. In `(layers ...)`, set In2.Cu type to `mixed` (was power "+3V3"); keep In1.Cu as power "GND".
4. Delete the 3 artifact zones (`for z in list(b.Zones()): b.Remove(z)` — lossless, all unfilled).
5. Recreate zones per the zone plan (polygons = board outline inset ~0.3mm).
6. Fix the USB_DIFF_90 netclass in `defcon_badge.kicad_pro`: change the patterns from the
   non-existent `/USB_D+` `/USB_D-` to the REAL nets `/MCU_Core/USB_DP`, `/MCU_Core/USB_DM` (and
   add the connector-side `Net-(U3-USB_DP)`, `Net-(U3-USB_DM)`); set `diff_pair_width` 0.8→0.17,
   `diff_pair_gap` 0.13 (0.15 ok).
7. `pcbnew.ZONE_FILLER(b).Fill(b.Zones())`, save, then `kicad-cli pcb drc` with the sibling
   `.kicad_pro` PRESENT (per the measure-needs-kicad_pro lesson) to confirm clearance/edge clean
   on the unrouted board before routing adds tracks.

## D1 exit gate (from HARNESS): stackup correct, zones fill clean, USB netclass fixed, unrouted
board DRC clean of NEW stackup/zone errors, baseline measure row, `unconnected_divergence==0`.

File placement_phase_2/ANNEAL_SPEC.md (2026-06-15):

# Global optimizer spec — simulated annealing (committed BEFORE implementation)

Tool: `placement_phase_2/tools/anneal.py`. Status: spec frozen at C(7).
Why: the constructive placer + greedy decouple+spread plateaus — it can hit 6/8 gates but
can't jointly satisfy decoupling_max<=2.0 AND overlaps==0 AND push ratsnest <1339, because
those objectives are coupled (cramming caps to pins creates overlaps; resolving overlaps
pushes caps away). A global optimizer that scores all objectives in one cost function and
explores moves stochastically is the textbook fix (TimberWolf-style SA; see placement_research.md).

## State
Each movable part has (x, y, rot, side). Fixed parts (J20,J10,SW1,U30,D20,J31,J11,SW23,H*)
are frozen — never proposed for moves. Start state = current constructive placement (warm
start) optionally pre-decoupled by decouple.py.

## Cost function (minimize)
  cost = w_rat * ratsnest_mm
       + w_ovl * sum(courtyard_overlap_area)        # ->0
       + w_off * num_offboard                        # centroid outside Edge.Cuts
       + w_edge* sum(edge_intrusion for non-edge parts)   # courtyard past outline
       + w_dec * sum(max(0, deco_dist_i - 2.0))      # decoupling proximity penalty
weights staged so hard constraints dominate (e.g. w_ovl,w_off,w_edge >> w_rat; w_dec mid).
ratsnest via the MST metric (GND excluded), incrementally where possible.

## Moves (proposal distribution)
- translate a part by a gaussian step (annealed magnitude);
- swap two same-zone parts;
- rotate a part by 90°;
- (rare) jump a part to a random spot in its floorplan zone.
Accept by Metropolis: ΔE<0 always; else exp(-ΔE/T). Geometric cooling T*=alpha each epoch.
Constrain translations to keep a part within its floorplan zone (soft) / board (hard).

## Schedule / scale
Warm start from constructive placement (already ~1580mm), so few thousand iterations suffice.
numpy for vectorised distance/overlap. Target wall-clock < a couple minutes per run. If SA
underperforms, the challenger is force-directed/analytical (also in research) — keep champion.

## Validation
After SA: run measure.py. Accept the result ONLY if every previously-passing gate still holds
and the objective improved; else revert (git). Render + LOOK. Compare ratsnest vs constructive
champion; keep the better. Re-run with different seeds/weights; keep best with all gates held.

## Gates this must achieve (with constructive's already met)
overlaps==0, offboard==0, decoupling_max_mm<=2.0, dfm copper/edge clearance==0, ratsnest
minimized (target <1339) and plateaued. Silk-only dfm handled separately by a silk pass.

## Reuse / reproducibility
Deterministic given a --seed. Reads/writes the .kicad_pcb via the same anchor/flip helpers as
place.py. decouple.py may seed cap positions first. Document in the badge-placement skill.

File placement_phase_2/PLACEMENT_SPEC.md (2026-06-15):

# Placement-engine spec (committed BEFORE implementation — plan-before-build)

Tools: `placement_phase_2/tools/place.py` (constructive) + later a global optimizer.
Consumes: champion `placement_phase_2/floorplan.json`. Mutates: the target .kicad_pcb.
Status: spec frozen at C(5).

## Purpose
Move every movable part from the off-board staging grid onto the board into its assigned
zone, honoring zone topology and the locked fixed/edge constraints, then optimize component
positions to minimize ratsnest while satisfying every LOCKED Phase-C gate.

## Objective
Minimize `ratsnest_mm` (MST wirelength over signal nets, GND excluded) subject to HARD gates:
overlaps==0, offboard==0, unplaced==0, fp_unresolved==0, fixed_ok, decoupling_max_mm<=2.0,
dfm_spacing_violations==0, erc<=14. Target ratsnest <=2358 (>=20% vs baseline 2947) and
beat-and-lock the ~1339mm phase-1 reference.

## Pipeline (champion/challenger; keep the best by measured ratsnest with gates held)
1. **Constructive (place.py)** — deterministic first placement:
   - Pin fixed parts at floorplan.json `fixed` pos/rot (layer already correct; don't flip).
   - For each zone, lay its parts by `topology`:
     - `ring`   — anchor IC at zone center; decoupling caps to its power pins
       (pcb-placement `auto_decouple` / `arrange_around_ic`); support parts packed nearby.
     - `chain`  — parts in signal-flow order along the zone's `flow` direction.
     - `row`/`column` — evenly spaced line.
     - `cluster`— compact shelf-pack.
   - Courtyard-aware shelf-packing keeps within-zone overlaps at zero; stay inside the bbox.
2. **Legalize** — remove residual overlaps with pcb-placement `spread.py`, then
   `validate_placement.py` to pull any part back inside Edge.Cuts.
3. **Refine** — decoupling proximity (`auto_decouple`), then a GLOBAL optimizer
   (simulated annealing or force-directed per placement_research.md) minimizing ratsnest with
   a courtyard-overlap + off-board + fixed-displacement penalty. SA is the baseline; compare a
   second method; keep champion.

## Validation / measurement
`measure.py` every iteration → append metrics row. Render with pcb-views every few iters and
LOOK (wrong-facing connectors, off-edge, collisions). A change that raises ratsnest or breaks
a gate is reverted (git). Plateau (<2% over 5 iters) with all gates held => Phase C done.

## Constraints / notes
- Edge.Cuts FINAL. Mounting holes H1-4 locked. J11/J31 stay on B.Cu.
- Fixed pos/rot are starting points the optimizer may nudge slightly, but the EDGE/SIDE and
  layer are hard (J20 top-right plug-up; J10 bottom; SW1 bottom-left; U30 left y110 / D20
  right y110 mirror; J31 microSD B.Cu edge).
- Tools do the placing — no hand-editing the .kicad_pcb to fix a symptom.

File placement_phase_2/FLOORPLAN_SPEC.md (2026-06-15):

# Floor-planner spec (committed BEFORE implementation — plan-before-build)

Tool: `placement_phase_2/tools/floorplan.py`
Artifact it emits: `placement_phase_2/floorplan.json`
Status: spec frozen at B(2). Implementation follows in B(3+).

## Purpose
Turn the netlist + design intent into a **floor plan**: a set of rectangular functional
zones tiled inside Edge.Cuts, every movable component assigned to exactly one zone, and the
fixed/edge-locked parts pinned at their required positions. The floor plan is the global
plan the Phase-C placement engine fills in. It exists so placement is *global and
signal-flow-aware* from the start, instead of greedy local nudging (the prior run's failure).

## Objective it optimizes
Primary: **minimize total estimated inter-zone ratsnest** (sum of MST wirelength using each
component's assigned zone centroid as its position proxy), subject to hard constraints:
- every component in exactly one zone; zones disjoint-enough and fully inside Edge.Cuts;
- fixed/edge parts at their locked positions;
- each subsystem's parts contiguous (one zone);
- signal-flow ordering respected (input→processing→output adjacency).
Secondary (tie-breakers): zone area utilization within capacity, shorter cross-board nets
(LED chain, I2S, QSPI, USB), audio/IR kept away from LED/switching noise.

## Inputs
- `defcon_badge/defcon_badge.kicad_pcb` (footprints, pads, nets, courtyard sizes via fp_meta).
- `badge_hw_design.md` (subsystem intent, signal flow, placement notes).
- Locked fixed constraints (below). Edge.Cuts AABB: x[100,188] y[80,134] (88×54mm).

## Output artifact (`floorplan.json`)
```json
{
  "board": {"x0":100,"y0":80,"x1":188,"y1":134},
  "zones": {
    "<name>": {"bbox":[x0,y0,x1,y1], "topology":"ring|chain|row|column|cluster|edge",
               "anchor":"<refdes|null>", "flow":"<dir>", "note":"..."}
  },
  "fixed": {"<refdes>": {"pos":[x,y], "rot":<deg>, "layer":"F.Cu|B.Cu", "why":"..."}},
  "assign": {"<refdes>":"<zone>"},          // every movable comp -> exactly one zone
  "score": {"approach":"...", "est_ratsnest_mm":<f>, "violations":[...]}
}
```

## Zone model
A zone is a rectangle + a topology rule the placement engine uses to lay its members out:
- `ring` — IC at center, decoupling/support caps ringed around its power pins (MCU, DAC).
- `chain` — parts in signal-flow order along a direction (power chain, audio chain, LED row).
- `row` / `column` — evenly spaced line (buttons, connector banks).
- `cluster` — loose group, packed compactly (misc passives of one subsystem).
- `edge` — pinned to a board edge at a given side/offset (connectors, IR pair).

## Subsystems → zones for THIS board (constructive starting point, derived from netlist)
- **mcu** (ring, anchor U3): U3 RP2040, U2 flash, Y1 xtal, C2/C3 (15p load), R5 (xtal 1k),
  R1/R2 (BOOTSEL/QSPI_SS), decoupling C5,C6,C7,C8,C9,C10,C11,C12,C14,C16,C23 (100n/1u on
  +3V3/+1V1), bulk C1,C4,C41,C71 (10u), R3/R4 (27Ω USB series). Center of board.
- **power** (chain, flow USB→LDO): U10 TP4056, U11 LDO, C20(1u VBUS), C21(10u BAT),
  C22(1u BAT_SW), R12(2.4k PROG), R13(100k CHRG), R14/R15(100k VBAT divider),
  R10/R11(5.1k CC). Bottom band near J10/J11.
- **audio** (chain, flow DAC→amp→jack, toward J20 top-right): U20 TM8211, U21 TDA1308,
  C42/C43(10u couple), C44(10u VGND), C40(100n), R20/R21(47k in), R22/R23(100k fb),
  R24/R25(10k vground), C45/C46(220u out). Upper-right, feeding J20.
- **leds** (row across top): LED20,LED21,LED22,LED23 + C60,C61,C62,C63(10n) + C70(100n)+C71(10u).
- **sao** (edge cluster): J30 + R40/R41(4.7k I2C pullups). A free edge (lower-left).
- **buttons** (row, bottom edge front): SW20,SW21,SW22,SW23 tactiles.
- IR + connectors handled as fixed/edge parts (below).

## Fixed / edge-locked constraints (LOCKED — from HARNESS Phase C gate; these win over the
design doc where they conflict, e.g. jack placement)
- **J20** audio jack — top-right, plug exits UP off the top edge.
- **J10** USB-C — bottom edge, plug down.
- **SW1** slide power switch — bottom-left corner.
- **U30** IR-RX — left edge, y=110.  **D20** IR-LED — right edge, y=110. Mirror-symmetric.
- **J31** microSD — on B.Cu, slot accessible from a board edge (back-center bottom).
- **J11** LiPo JST-PH — on B.Cu, near power zone, wire exit to an edge.
- **H1–H4** M2.5 mounting holes — already at the four corners; keep.

## Two approaches (the mission requires ≥2, scored, champion recorded)
- **A — constructive intent-driven** (B3): place fixed parts first; lay zones by the design
  intent + signal flow above (LEDs top, IR pair sides@110, audio upper-right→J20, power
  bottom→J10/J11, MCU center, buttons bottom, SAO free edge); pack each zone to fit its
  members' courtyard area + margin; emit artifact.
- **B — connectivity-driven partition** (B4): build the component graph weighted by shared
  nets (exclude GND/+3V3 power rails), run a balanced min-cut / spectral partition into the
  same number of zones, then assign each partition to a board region by matching its fixed
  anchors (the partition containing J10 → bottom, containing J20 → top-right, etc.).
  This lets connectivity, not just intuition, decide grouping.

## Scoring metric (how the champion is chosen)
For each emitted plan compute: (1) `est_ratsnest_mm` = MST over component zone-centroids
(GND excluded), lower is better; (2) hard-constraint violations (must be 0 to be eligible);
(3) zone capacity overflow (Σ member courtyard area vs zone area), lower better;
(4) signal-flow adjacency score (are chained subsystems in adjacent zones). Champion =
0 violations, then lowest est_ratsnest, then best capacity/adjacency. Record `CHAMPION:` in
LEDGER and write the winning plan to `floorplan.json`.

## Validation (Phase B exit gate — must all hold on the emitted plan)
- every movable component appears in exactly one zone (no missing, no double);
- all zone bboxes lie fully inside Edge.Cuts; zones don't overlap beyond a small slack;
- fixed/edge parts present at required positions/edges/layer;
- functional grouping matches the design-intent subsystems above;
- signal-flow ordering respected (power chain monotonic toward J10; audio toward J20).
- tool documented as a skill; ≥2 approaches scored; champion recorded.

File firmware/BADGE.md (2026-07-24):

# DEFCON Silent-Disco Badge — Hardware Notes & Quirks

Everything here was verified during hardware bring-up (MicroPython v1.28 on the
RP2040) against the KiCad schematic in `../defcon_badge/`. These are the facts
the firmware depends on. **Read this before changing pin assignments.**

## Pin map (all GPIO numbers)

| Subsystem | Signal | GPIO | Notes |
|---|---|---|---|
| **LEDs** (SK9822 ×4) | CLOCK | **GP24** (rev 2) | rev 1 boards: GP25 — swapped vs schematic (see below) |
| | DATA | **GP25** (rev 2) | rev 1 boards: GP24 |
| **Audio** (TM8211 I2S) | BCK / SCK | GP7 | |
| | WS / LRCK | GP8 | must be `SCK+1` on RP2040 |
| | DIN / SD | GP6 | |
| **Buttons** | SYNC | GP12 | active-low, needs pull-up |
| | VOL− | GP13 | |
| | VOL+ | GP14 | |
| | CH (→play/pause) | GP15 | |
| **microSD** (SPI0) | SCK | GP2 | |
| | MOSI | GP3 | |
| | MISO | GP4 | ⚠️ no board pull-up |
| | CS | GP5 | |
| **IR** | TX (LED) | GP9 | active-low, 38 kHz carrier |
| | RX (TSOP4838) | GP27 | active-low, idles high |

## Verified quirks (the important part)

### 1. LED clock/data are SWAPPED (rev 1 only — FIXED on rev 2)
On **rev 1**, the SK9822 footprint/silkscreen had DIN/CIN reversed, so the
assembled board needs **CLOCK on GP25 and DATA on GP24** — the opposite of the
schematic net names (`LED_SCK`, `LED_DAT`). With the schematic mapping the LEDs
stay dark; with the swap they work. **Rev 2 fixed the footprint** (verified
2026-07-24: schematic mapping works, swapped mapping is dark) — `config.py`
now ships with the schematic mapping; flip `LED_CLK`/`LED_DAT` for a rev 1 board. All four LEDs must also share the **same physical
orientation** or the daisy-chain breaks partway.
- GP24/GP25 are **not** on a hardware SPI block → the driver bit-bangs.
  ⚠️ Bit-banging this through `Pin.value()` cost **3848 µs per frame — 12.8% of
  the CPU** at a 30 ms refresh, enough to starve the MP3 refill and cause audible
  stutter. `sk9822.py` now shifts bits by writing the SIO `GPIO_OUT_SET`/`CLR`
  registers (`0xd0000014`/`0xd0000018`) from a viper function, which brings a
  full render down to 942 µs (3.1%). `SK9822.delay` pads the clock phases if a
  longer chain ever needs slowing down; 0 is right for four LEDs.
- Byte order after the brightness byte is **B, G, R** (standard SK9822).
- These run at 3.3 V. That's below the SK9822 datasheet min (3.7 V) but they
  work fine in practice.

### 2. Audio DAC = TM8211 (PT8211 clone), plain I2S
- No MCLK required, no mute/enable pin. Chain: DAC → TDA1308 headphone amp →
  3.5 mm jack (SJ1-3523N).
- 🚨 **The PT8211/TM8211 requires LSB-justified (LSBJ) framing, and this is not
  optional.** An earlier version of this document claimed "standard I2S produces
  clean audio in testing" — **that was wrong** and cost a long debugging session.
  See quirk 6 below.
- **No hardware volume** anywhere in the chain → volume is done in software by
  scaling PCM samples. The PT8211 has no gain register and the TDA1308's gain is
  fixed by its feedback resistors, so scaling samples in `dsp.pcm16_to_lsbj32()`
  is the only volume control that exists.
- Analog gain is **≈2.1×** (100 kΩ feedback / 47 kΩ input, per the schematic) and
  is perfectly healthy. If output seems wildly too loud, suspect the framing
  (quirk 6), not the amp.
- WS pin must equal SCK+1 on RP2040: GP8 = GP7+1. ✔
- ⚠️ **Rev 1 builds had the TDA1308 unpopulated** (wrong package was ordered).
  Listening directly off the DAC into headphones (32 Ω) overloads the PT8211's
  line-level output → heavy "clipped" distortion at any real amplitude. The
  digital chain was exhaustively verified clean (decode bit-perfect vs ffmpeg,
  DSP exact, I2S transport clean) — the distortion is purely the missing
  buffer. On an amp-less board: feed a **line-level input** (powered
  speakers/AUX), keep digital level ≤ ~5–10 %, and set `VOL_DEFAULT_STEP = 1`.
  **Rev 2 has the TDA1308 populated** — headphone output is usable and the
  default volume step in `config.py` is raised accordingly.

### 3. microSD reads work; it's a read-mostly device here
- The card's **CMD8 response glitches its R1 byte on bus turnaround** on this
  board. The stock `sdcard.py` rejects the card ("couldn't determine SD card
  version"); the patched `sdcard.py` in this dir detects a v2/SDHC card from
  the CMD8 voltage echo (`0x01AA`) instead. It also drains the bus on a read
  timeout (so a marginal read doesn't wedge the card) and retries block reads.
- There is **no MISO pull-up** on the board. Keep SPI at ≤1 MHz. Measured read
  throughput at 1 MHz: **~45–51 KB/s**, byte-perfect and repeatable on a
  settled board (10/10 verified reads of an 8 KB file; a 269 KB file read clean
  at 51 KB/s).
- **Writes are unproven** and occasionally wedged the card during testing (partly
  confounded by live-soldering). Treat the card as read-only in the field; load
  content offline with a card reader.
- **Respin TODO:** add a MISO→3V3 pull-up (10–47 kΩ), ideally on MOSI/CS too,
  plus series resistors on SCK — then higher SPI clocks and reliable writes
  become possible.

### 4. Buttons
Active-low, no external pull resistors → enable the RP2040 internal pull-ups.
`value()==0` means pressed. All four verified idle-high and responsive.

### 5. IR (send + receive both work)
- TX: IR LED driven **active-low** through a resistor from GP9. Modulate a
  **38 kHz** carrier (the TSOP4838 only demodulates ~38 kHz). GP9 low = LED on.
- RX: TSOP4838 output on GP27, **active-low**, idles high, pulls low when it
  sees the carrier (with ~160 µs turn-on latency).
- Self-loopback works on the bench with no reflector (enough on-board optical
  coupling). Intended use is device-to-device timing sync — not wired up in the
  player yet (the SYNC button is a local no-op that just changes the lights).

### 6. I2S framing: the DAC needs LSBJ, MicroPython only speaks standard I2S
This was the root cause of the rev-2 "everything is painfully loud and music is
pure static" bug. Diagnosed and fixed 2026-07-24.

The schematic says it outright: *"DAC needs LSBJ-format I2S (WS shifted by one
BCK vs standard I2S)."* LSB-justified framing means the sample's last bit lands
on the WS edge. Standard (Philips) I2S delays data by one BCK instead. With
**16-bit frames** that one-bit slip is catastrophic, because the DAC latches the
16 bits ending at the WS edge:

| DAC bit | gets | should be |
|---|---|---|
| 15 (**sign**) | the **previous** sample's LSB | sample bit 15 |
| 14..0 | sample bits 15..1 | sample bits 14..0 |

So the **sign bit is driven by a bit with no relationship to the signal**. Any
sample whose LSB is set slams the next output to roughly −32768. Consequences,
all of which we observed:
- Output sits near full scale no matter how small the samples are, so it is
  deafening even at 1 LSB (−90 dBFS), and **software volume cannot work at all**.
- *Music* becomes broadband static, because its LSBs toggle pseudo-randomly.
- *Pure tones* still sound crisp and pitched — the LSB of a low-amplitude sine
  toggles periodically, so the garbage is a periodic (square-ish) wave at the
  right frequency. This is why every tone test wrongly looked fine, and why the
  bug survived rev-1 bring-up.

**Fix (no PIO needed):** send **32-bit frames** with the 16-bit sample in bits
**16..1** — `dsp.pcm16_to_lsbj32()`, enabled by `I2S_BITS = 32` in `config.py`.
The one-BCK delay then aligns those bits exactly with the final 16 bits of the
frame. Costs one extra pass over the samples (fused with the volume multiply)
and doubles the wire rate and `I2S_IBUF`.

Debugging tip that isolated it in one test: play a square wave toggling `0/1`
against one toggling `0/2`. They differ by a single bit, but under this fault
the `0/1` one is dramatically **louder** — amplitude and loudness inverted.
Nothing but a sign-bit misalignment does that.

### 7. The LEDs are audible in the headphones
Reported and localised 2026-07-24: with playback **digitally muted** (volume
step 0) there is still a high-pitched whine, plus a periodic tick. It tracks the
LED animation — during the amber "paused" breathing you can literally hear the
brightness rise and fall. So it is not in the audio data; the LED chain is
coupling into the audio, most likely through the shared 3V3 rail as SK9822
current draw changes with PWM duty, with the periodic bit-bang burst adding the
tick.

**The mechanism is PWM duty cycle, not brightness or data traffic.** Narrowed
down by ear on 2026-07-24:
- Not data: the frame is re-clocked every 30 ms whether or not anything changed,
  so bit-bang traffic is constant and cannot explain noise that comes and goes.
- Not position: with only LED1 lit — the one furthest from the jack and amp —
  it was just as audible, ruling out radiated/capacitive coupling.
- **It is duty.** The SK9822 dims each channel by chopping it at ~4.7 kHz, right
  in the audible band. Switching energy peaks near 50% duty and vanishes at both
  0% and 255. Decisive test: two phases at *equal average current*
  (value 255 @ brightness 8 vs value 128 @ brightness 16) but 100% vs 50% duty —
  the noise cleanly alternated with duty. This also explains why a rainbow is
  loudest *mid-transition* (mixed, mid-range channels) and quiet at its
  brightest points (saturated hues).

Firmware fixes, both in place:
1. **A quiet palette.** `lights.py` now uses only saturated channel values
   (0 or 255) and expresses all intensity through the SK9822's **per-LED**
   global-brightness field, which is an analog constant-current setting rather
   than a duty cycle. ⚠️ Do not reintroduce `wheel()`/`scale()` or any
   mid-range colour value into the light modes — that is precisely the fault.
2. **An OFF mode** (cycle to it with SYNC). A real quiet state, not black
   pixels — after one dark frame it stops touching the chain entirely, since
   clocking out black would leave the switching noise in place.

`LED_ACTIVE_MASK` in `config.py` restricts which LEDs illuminate while still
clocking all of them, which is how the position test above was run.

**Respin fixes to consider:** separate/filtered supply for the LEDs, bulk plus
HF decoupling at the LED chain, keeping LED traces away from the DAC and its
coupling caps, and a star ground so LED return current does not share a path
with the audio ground.

## Audio formats

**WAV — works on stock MicroPython.** 16-bit PCM streamed SD → I2S. Convert songs
with `tools/prepare_card.sh` (ffmpeg). Keep files **mono, 16000 Hz** (32 KB/s,
safe) — 22050 Hz mono (44 KB/s) is borderline against the SD read ceiling. The
badge up-mixes mono to stereo via `I2S.MONO`.

**MP3 — needs the custom firmware.** MicroPython has no built-in MP3 decoder and
pure-Python decode is too slow, but the RP2040 decodes MP3 in fixed-point **C**.
⚠️ Measured on hardware (2026-07-24): decode of 44.1 kHz stereo costs **~94% of a
core at stock 125 MHz** (an earlier ~34% estimate was wrong) — with DSP + SD on
top the player underruns constantly. The firmware therefore **overclocks to
250 MHz** at boot (`CPU_FREQ` in `config.py`), verified stable and >1× realtime
with the full task load. The
`cmodules/mp3` native module (Helix / [picomp3lib](https://github.com/ikjordan/picomp3lib))
exposes a `mp3.Decoder` callable from Python; build with `tools/build_firmware.sh`.
MP3 also **reduces** SD load (128 kbps ≈ 16 KB/s vs 32 KB/s for the WAV above) and
shrinks files ~10×. The player uses MP3 automatically when the module is present
and `.mp3` files are on the card; it falls back to WAV-only on stock firmware.

Key M0+ detail: the RP2040 (ARMv6-M) has no 64-bit multiply (`SMULL`); picomp3lib's
`assembly.h` gates the `SMULL` path on `__ARM_ARCH >= 7`, so it uses a C multiply
fallback — don't swap in an unpatched decoder.

*(CircuitPython also has a native `audiomp3` decoder, but its built-in SD driver
would re-trip the CMD8 glitch our MicroPython driver works around, and it needs a
full app rewrite — so the C-module route is preferred.)*

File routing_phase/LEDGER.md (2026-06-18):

# LEDGER — routing loop decision log (append-only; NEVER rotate/truncate)

Format: `[ISO-date] D?(N) — action | rationale | result | Δmetric`.
Prefixes: `BLOCKER:` (stuck, exhausted approaches) · `REVIEW:` (a locked rule may be wrong — log +
keep complying) · `CHAMPION:` (new best approach) · `MANUAL(user...)` (user-directed out-of-band edit).

---

[2026-06-17] D0(0) — SETUP/AUTHORING (by the mission-author session, not a loop iteration).
  ACTION: stood up the routing phase. (1) Two deep research workflows: routing-phase bearings
  (harness reuse, headless DSN path, router survey, net plan, metric/gate spec) + routing-engine
  architecture (aesthetic routing, determinism/ECO, Freerouting fork-vs-build, KRT assessment,
  4-layer stackup rework). (2) ENGINE DECISION: REJECT Freerouting (110kloc legacy Java, structural
  ugliness, Java 25, non-deterministic, no incremental — forking buys the property we don't want);
  BUILD ON KiCadRoutingTools (MIT, KiCad-10-native, deterministic, diff-pairs/planes/rip-up; default
  aesthetics are griddy → OUR layer owns aesthetics). (3) Vetted KRT firsthand: cloned, viewed demo
  renders (confirmed default output is autorouted-looking on DENSE boards; our badge is sparse),
  confirmed MIT + KiCad 9/10 + the CLI seams (--guide-corridor, --bus, --turn/via/track-proximity
  cost, --nets/--rip-existing-nets for incrementality). (4) Installed the engine env: KRT pinned at
  ce5cb2d (v0.15.13) under ~/.local/share/defcon-badge-krt/, isolated venv with cp314
  numpy/scipy/shapely wheels, prebuilt rust grid_router kernel — smoke-tested OK. (5) Authored
  mission-control: MISSION/HARNESS/PROMPT/STATE/ROUTING_SPEC/STACKUP_SPEC/routing_rules + setup.sh.
  RATIONALE: user chose to build (not click Freerouting); the spec is aesthetic + deterministic +
  re-runnable + ours. Mirror the placement_phase_2 harness (authoritative geometry + DRC-backed
  instrument + locked gates + append-only memory + anti-thrash convergence rule).
  RESULT: env ready; board still unrouted (0 tracks/vias); 4-layer stackup is a porting artifact to
  be reworked in D1. No metrics row yet (D0's first loop iteration builds measure_route.py + baseline).
  USER DECISIONS recorded: 4-layer (rework the ported zones), fully-autonomous loop (run free,
  minimal interruption, all tooling on the table), engine = my call (chose build-on-KRT), re-runnable
  is a real goal. Δmetric: n/a (baseline pending).
  NOTE: a one-time host prerequisite remains optional — none blocking (KRT env already installed in
  the venv; no sudo/JRE needed). The loop owns the board file; placement is frozen.

[2026-06-17] D0(1) — BUILD INSTRUMENT | the loop can't fly without its metric engine + a
  copper-aware geometry layer | built routing_phase/tools/geom_route.py (authoritative track/via
  read + add_track/add_via/delete_routing/refill_zones, single-writer via writer_lock — the copper
  analog of geom.py) and measure_route.py (full routing schema per ROUTING_SPEC, reusing measure.py
  DRC plumbing). KRT smoke-tested on the real board (list_nets: 84 nets/83 comps, GND 89 / +3V3 47 /
  USB_DP 3 pads). | Δmetric: baseline row written — completion 0%, unconnected 218 (divergence 0),
  0 tracks/vias, usb_diff_paired FALSE, zones_filled_ok FALSE, drc 0, erc 0.
  FIX (frozen-file safety): a first measure mutated the approved .kicad_pro — pcbnew's settings
  manager flushes BOM field-defs (MPN/LCSC/Description, from earlier BOM work) into the real project
  on process exit after reading project state. Reverted; measure_route now runs ALL pcbnew loads +
  kicad-cli on a /tmp project copy (byte-identical reads, real frozen files never opened — verified
  git-clean after). The HARNESS already warns about this for the D2+ write path.

[2026-06-17] D0(2) — BUILD INCREMENTAL ENGINE | re-runnability must be structural (built before
  any router exists) | built routing_phase/tools/route_db.py (net_sig = sha1 of sorted pin-set
  "REFDES-PADNUM" — NOT the churning net name; live_nets/diff(NEW/CHANGED/DELETED/UNCHANGED)/
  stable_order/record_routes/replay/fingerprint) + geom_route.safe_board (/tmp-copy read context
  so any read-only tool is immune to the .kicad_pro BOM-flush). | Self-test: 64 routable nets (62
  signal + 2 planes), all NEW vs empty db, stable order front-loads the 4 USB diff nets (rank0) then
  XIN/QSPI (rank1), signatures reproducible across two reads, fingerprint empty on unrouted board,
  frozen files clean. Δmetric: board unchanged (completion 0%, unconnected 218). **D0 EXIT GATE MET**
  → advance to D1 (stackup rework per STACKUP_SPEC).

[2026-06-17] D1(1) — STACKUP/ZONE REWORK | the ported zones were crude 4-pt rectangles missing the
  right ~3.6mm of the board (D20/J20 had no ground reference) and didn't follow the sawtooth outline |
  built routing_phase/tools/rework_stackup.py: thickness 1.0→1.6mm; deleted the 3 artifact zones;
  recreated 4 zones from the real board outline inset 0.3mm (In1 solid GND plane, In2 +3V3-dominant
  pour, F.Cu + B.Cu GND pours) via SHAPE_POLY_SET + ZONE_FILLER; In2.Cu→mixed. Applied to the real
  board, verified by a fresh measure_route subprocess. | Δmetric: zones_filled_ok FALSE→TRUE,
  unconnected 218→147 (planes now carry GND/+3V3; remaining 147 = signal nets + pads still needing
  fanout vias, the D2 job), drc 0, erc 0. baseline.json frozen at 147 (completion_pct now measures
  real progress from here). Frozen-file discipline HELD: only .kicad_pcb changed (.kicad_pro/.kicad_sch
  git-clean). Render routing_phase/renders/d1_top.png reviewed: placement intact, pours present.
  GOTCHA: pcbnew swig wrapper registry corrupts after LoadBoard→mutate→Fill→Save→re-read in one
  process (raw pointers) → rework_stackup does one LoadBoard+SaveBoard, no post-save introspection;
  verification is a separate measure_route subprocess. DEFERRED to fab-prep: explicit dielectric
  (stackup ...) block (thickness set to 1.6mm; the block is fab metadata, not routing-blocking).

[2026-06-17] D1(2) — FIX USB DIFF-PAIR NETCLASS | the USB_DIFF_90 class targeted non-existent nets
  (/USB_D+ /USB_D-) so the pair silently fell back to Default, and its 0.8mm width was a 2-layer value
  | targeted minimal edits to defcon_badge.kicad_pro: patterns → the REAL nets /MCU_Core/USB_DP,
  /MCU_Core/USB_DM + the connector-side Net-(U3-USB_DP), Net-(U3-USB_DM) (whole pair through the 27R
  series Rs now controlled); diff_pair_width 0.8→0.17, diff_pair_gap 0.15→0.13 (≈90Ω over the In1 GND
  plane on the 1.6mm 4-layer stack). | Δmetric: usb_diff_paired FALSE→TRUE (gate flips). Diff is ONLY
  the netclass change (12+/4−); .kicad_sch + .kicad_pcb untouched; valid JSON; drc 0, erc 0,
  unconnected 147, zones_filled_ok TRUE. **D1 EXIT GATE MET** (zones reworked+filled, USB netclass
  fixed, unrouted DRC clean, baseline frozen) → advance to D2 (plane fanout + critical pre-route).

[2026-06-17] D2(1) — KRT INTEGRATION via a BRIDGE (escalation: KRT writer is unusable) | evaluated
  KRT route_planes for plane fanout; it computes a good fanout (GND 89/89, +3V3 47/47) BUT its board
  WRITER emits `(net "GND")` (net NAME) inside (segment)/(via) where KiCad 10 requires `(net <int>)`,
  so KRT's output board does NOT load in pcbnew OR kicad-cli ("Failed to load board"; pcbnew segfaults
  on zone-fill of it). => KRT can be a SOLVER but NOT our board writer. | ESCALATED (per HARNESS, don't
  repeat a failing move) to a BRIDGE: routing_phase/tools/krt_bridge.py — extract_routing() parses KRT's
  output tracks/vias (net names are right there) + apply_routing() re-emits them via pcbnew/geom_route
  (the authoritative single writer, HARNESS Resolution 1). This is the integration seam for ALL KRT use
  (D2 planes + D3 signals): KRT never touches the real board; pcbnew is the only writer.
  | VALIDATED on /tmp: KRT route_planes → bridge → pcbnew board LOADS in kicad-cli ✓; footprints
  byte-frozen (fp_pos_hash identical) ✓; unconnected 147→98; ZERO new routing-type DRC errors (clearance/
  dangling/width all clean). Δmetric: real board UNCHANGED this iter (147) — bridge built+validated only;
  fanout applied to the REAL board in D2(2). FINDINGS (pre-existing placement DRC, NOT routing-caused,
  present on the unrouted D1 board): 28 solder_mask_bridge (different-net fine-pitch pads — RP2040/USB-C/
  microSD; scoped out of ROUTING_TYPES like placement scoped intra-fp dfm) + 7 starved_thermal (may be
  from the D1 zone thermal relief — investigate in D2(2)). FLAG for the user: the approved placement has
  28 pre-existing solder-mask-bridge DFM warnings worth a placement revisit (out of routing scope).

[2026-06-17] D2(2) — PLANE FANOUT APPLIED (first copper on the real board) | connect GND/+3V3 pads to
  their planes so only signal nets remain to route | (a) FIX starved_thermal: D1 zones gave 7 GND pads a
  1-spoke thermal relief (min 2) on the F.Cu pour → set GND/+3V3 zones to SOLID connection
  (ZONE_CONNECTION_FULL, the textbook choice for planes) → starved_thermal 7→0. (b) FIX
  rework_stackup segfault-at-exit (pcbnew swig teardown) with os._exit(0) after a successful save.
  (c) FIX geom_route.load_vias — KiCad 10 PCB_VIA.GetWidth() needs a layer arg. (d) KRT route_planes
  (solver) → krt_bridge (extract → re-apply via pcbnew) onto the REAL board: 219 tracks + 114 vias
  (GND 75 + +3V3 39 + 14 GND-return). | Δmetric: completion 0→33.3%, unconnected 147→98 (divergence 0),
  drc_errors 0 (routing types), shorts 0, zones_filled_ok TRUE, usb_diff_paired TRUE. Footprints
  byte-frozen (fp hash unchanged); .kicad_pro/.kicad_sch git-clean. route_db recorded (64 nets; GND/+3V3
  carry the fanout). Renders d2_top.png/d2_copper.svg: placement intact. WATCH: off_axis_segments 17 +
  acute_angles 39 from KRT via-to-pad stubs → D4 cleanup (not a D2 gate). Determinism formal gate
  deferred to D5 (route_db replay is deterministic by construction; the inline replay-verify hit a
  multi-LoadBoard-per-process swig None bug in the TEST harness, fixed approach = subprocess per load).

[2026-06-17] D2(3) — CRITICAL FINDING: fanout blocks signal escape (re-order needed) + bridge fix |
  attempted USB pre-route via KRT | (1) TOOL: krt_bridge.apply_routing now supports replace=True
  (rip-then-lay) — KRT emits prior+new routing, so extracting its full output + applying with replace
  keeps the board == latest full solution with NO fanout duplication. (2) The USB pair is MULTI-POINT
  (U3 ↔ 27R R3/R4 ↔ J10) with a FORCED CROSSOVER (U3.46/DM above U3.47/DP at source, R4/DM below R3/DP
  at target → not planar on one layer). KRT route_diff couples the long J10→R leg, defers short MCU legs
  to single-ended (textbook). KRT route.py single-ended routes 3/4 USB nets but Net-(U3-USB_DP)
  (U3.47→R3.2) FAILS "no rippable blockers": the plane FANOUT VIAS around the U3 QFN form a via fence
  blocking signal escape. SYSTEMIC — power-fanout-before-signal-escape will block more nets near dense
  ICs in D3. | Δmetric: real board UNCHANGED (33.3%) — the 3/4 partial (probe: 36.7%/unconn93/DRC0) was
  NOT applied; it's incomplete and masks the real issue. ESCALATION (HARNESS: don't repeat a blocked
  move) → D2(4): adopt the route_db-as-source-of-truth model and RE-ORDER to SIGNALS-FIRST (route
  critical signals on empty copper, USB with a B.Cu/layer-swap escape for the crossover, THEN fanout in
  the remaining space). This is why we built route_db + the base/replay model — now it earns its keep.

[2026-06-17] USER DIRECTIVE — NO via-in-pad (handled out-of-band; loop idle). User: "no via-in-pad
  please". Added it as a HARD GATE via_in_pad==0: measure_route._via_in_pad counts vias whose body
  hit-tests inside a pad's copper on a layer the via touches. FINDING: the current D2(2) fanout has
  94 via-in-pad — KRT route_planes places stitching vias AT pad centers by default
  (--same-net-pad-clearance −1). FIX (verified on /tmp, clean base + bridge): pass route_planes
  --same-net-pad-clearance 0.2 → offset vias + stub traces, via_in_pad 95→0, GND 89/89 + +3V3 47/47
  still connected, drc 0, shorts 0. Trade-off: offset stubs spike track_count (~219→1724) → a D4
  cleanup/aesthetic target. Locked in HARNESS (metric + D3/D4 gate + a dedicated note), routing_rules
  (via strategy), STATE D2(4) plan, and memory [[no-via-in-pad]]. Board UNCHANGED — the 94 via-in-pad
  get eliminated when D2(4) re-runs the fanout with the offset flag. erc/drc unaffected this commit.

[2026-06-18] D2(4) — SIGNALS-FIRST RE-ORDER → 73% (the re-order works) | the fanout via-fence blocked
  signal escape (D2(3)); fix = route signals on empty copper first | validated USB routes 4/4 on the
  clean base (was 3/4 fenced). Full chain: clean base (delete_routing+refill) → KRT route.py all 62
  signals (criticality order) → KRT route_planes fanout --same-net-pad-clearance 0.2 (no via-in-pad) →
  krt_bridge extract → apply_routing(replace) to REAL → route_db recorded (v2). | Δmetric: completion
  33→73.5%, unconnected 98→39, via_in_pad 94→8, USB 4/4 (usb_diff_paired TRUE), drc 0, shorts 0,
  footprints byte-frozen, pro/sch clean. REMAINING (D3/D4): 13 signal nets FAILED (congestion →
  rip-up/reroute + guide corridors + B.Cu); +3V3 fanout 37/47 (signals took space); via_in_pad 8 from
  KRT route.py SIGNAL vias (route.py lacks --same-net-pad-clearance → must offset/nudge them, hard gate
  needs 0); off_axis 147 / acute 635 / track 2214 → board looks AUTOROUTED, aesthetic goal UNMET (D4:
  bus planner via --guide-corridor + beautification). Honest state: connected-but-spaghetti; the
  hand-designed look is the D4 payoff still ahead.

[2026-06-18] D3(1) — DIAGNOSIS: B.Cu blocked by the outer GND pours (no board change) | tried to
  push completion past 73% | the 39 unconnected = 21 plane edges (GND 11 + +3V3 10, fanout blocked by
  signals) + 18 signal edges (whole SD bus SD_SCK/MOSI/MISO/CS/CD, I2S trio, QSPI_SCLK, IR_TX, LED_SCK,
  BTN_VOL_UP/SYNC, SAO_SDA/GPIO1/GPIO2, VBAT_SENSE, 1 USB MCU-side). KEY FINDING: B.Cu is severely
  underused — F.Cu 796mm vs B.Cu 22mm (layer_balance 0.028); the cross-board buses fail for lack of
  room while the bottom layer sits empty. KRT reports "blocked by pads/stubs/ZONES" → the FILLED outer
  F.Cu/B.Cu GND pours are a solid obstacle to KRT's router → it can't route signals on B.Cu. FIX
  (D3(2)): route with the OUTER pours UNFILLED (keep inner planes), refill ALL zones at the very end so
  the pours recede around the traces. Also: KRT mps + rip-up (--rip-existing-nets all) is pathologically
  slow on this board (300k iters → minutes/timeout, several runs killed); use --ordering original (fast,
  ~instant). | Δmetric: real board UNCHANGED (73.5%, 39 unconnected, via_in_pad 8) — all experiments
  were on /tmp; real board verified clean + intact (83 fps, 2214 tracks, 169 vias). The B.Cu insight is
  the unlock for the failed cross-board buses.

[2026-06-18] D3(2) — route_pipeline tool + CORRECTED diagnosis (real board unchanged, 73%) | implement
  the D3(1) B.Cu fix | built routing_phase/tools/route_pipeline.py — the reproducible signals-first
  pipeline (base → KRT route → fanout → bridge apply), each pcbnew step subprocess-isolated; clean arg
  lists (no shell quoting — fixed the bogus "0/18"). FIXED build_base segfault: delete_routing + zone
  fill in ONE process crashes BEFORE SaveBoard (board unchanged, no output) → split into delete+save
  then unfill/fill+save (each save lands before the teardown crash). FINDINGS: (a) the D3(1) "outer GND
  pours block B.Cu" hypothesis is DISPROVEN — with them unfilled B.Cu stayed 22mm; KRT reproduced 49/62
  exactly (deterministic). (b) the real lever is --layer-costs: `--layers F.Cu B.Cu --layer-costs 3.0 1.0`
  (penalize F.Cu) forces B.Cu 22→588mm — KRT is F.Cu-dominant + won't use B.Cu unprompted; added 2.0/1.0
  to route_pipeline. (c) BUT layer-balancing does NOT fix the ~13 failing nets (still fail with B.Cu free)
  → they fail on INTRINSIC escape/crossing congestion near the U3 QFN, not layer capacity. | Δmetric:
  real board UNCHANGED (73.5%, 39 unconnected, via_in_pad 8) — pipeline reproduces it deterministically;
  not re-applied (layer-balanced apply + the 13 stragglers + via_in_pad→0 is D3(3), with DRC verify).

[2026-06-18] D3(3) — MAJOR FIX: signals were routed ON THE REFERENCE PLANES | applying the
  layer-balanced route surfaced it | the committed board (D2(4)+) had ~60 signal-track segments on the
  In1 GND / In2 +3V3 planes (IR_RX, USB, VBUS, +1V1, RUN, audio JACK_R, buttons, QSPI_SS, LED_DAT...) —
  KRT defaulted to routing on ALL 4 copper layers because earlier routes lacked --layers. This carves up
  the reference planes (serious SI flaw). route_pipeline now restricts to --layers F.Cu B.Cu (added D3(2));
  re-applied it to the real board. | Δmetric: signal-tracks-on-inner-planes ~60→0 (planes intact); both
  outer layers now used (F.Cu 736 / B.Cu 372, layer_balance 0.028→0.505); completion 73.5→75.5%; footprints
  byte-frozen; pro/sch clean; route_db v3. COST (the next cleanup, D3(4)): drc_errors 0→2 (via-to-via
  clearance — USB DP/DM vias 0.128mm apart; BTN_VOL_UP/BTN_CH vias 0.128mm) + via_in_pad 8→11 — BOTH are
  KRT route.py SIGNAL-via placement defects (unlike route_planes, route.py has no via-offset/spacing flag).
  Judgment: planes-clean + both-layer is the CORRECT design foundation (signals off the planes is
  fundamental), worth accepting 2 transient via-clearance + via_in_pad to fix with a dedicated via-fixer
  next — better than keeping a metrically-cleaner board that's structurally wrong (signals on planes).
  REVERTED an intermediate apply earlier this iter before realizing the planes issue made the balanced
  board the correct one. NOTE: route.py also routes on planes unless --layers F.Cu B.Cu — keep it in the pipeline.

[2026-06-18] D3(4) — via-fixer built; post-hoc via-moving DOESN'T WORK on this congested board (real
  board unchanged, 75.5%/via_in_pad 11) | drive via_in_pad→0 (user hard gate) | built
  routing_phase/tools/fix_signal_vias.py: move each via off its pad along the escape dir, relink the
  connected track endpoints, add a pad→via stub. Debugged a state-staleness bug (cached track/via lists
  go stale as vias move + stubs add → corrupts other nets) by re-querying the board per via — now
  DETERMINISTIC. But the result is via_in_pad 11→1 with 124 DRC + 8 SHORTS: the via-in-pad vias are in
  genuinely congested spots (beside other pads/tracks), so the moved vias + blind stubs collide with
  other nets. ESCALATION/CONCLUSION (don't repeat the broken move): via-in-pad CANNOT be cleanly
  post-fixed here; it must be solved at ROUTING time — route each offending net with a CONTROLLED
  ESCAPE (short trace on the pad's own layer to open space, then via there), via the bus planner /
  --guide-corridor, NOT a blind post-hoc nudge. KRT route.py has no via-in-pad-avoidance flag, so this
  is our layer to build. | Δmetric: real board UNCHANGED (75.5%, via_in_pad 11, drc 2) — fixer ran only
  on /tmp; NOT applied (it makes things worse: shorts). fix_signal_vias.py kept as reference (tiny-move
  + relink mechanics reusable; missing piece = DRC-routing the stub). via_in_pad→0 folds into D3(5)
  guided-escape re-route of the via-in-pad + straggler nets together.

[2026-06-18] D3(5) — CONFIRMED DEAD END: post-hoc via-moving cannot solve via_in_pad on this congested
  board (real board unchanged, 75.5%/via_in_pad 11). Confirmed KRT route.py has NO via-in-pad-avoidance
  flag (--no-stub-layer-swap, --via-proximity-cost: via_in_pad stays 11). Improved fix_signal_vias.py to
  a FULL clearance check (moved via on both outer layers + the pad→via stub path sampled vs all
  other-net pads/vias/tracks); still via_in_pad 11→3 with 96 DRC (clearance 61, hole_clearance 35,
  0 shorts). ROOT CAUSE (definitive, tried 4 ways): moving a via also drags its ROUTE track's endpoint
  to the new spot — that new segment can't be validated without RE-ROUTING it — and via holes violate
  hole-to-hole spacing in the QFN congestion. Post-hoc nudging = mini-routing; not viable. via_in_pad
  must be solved by RE-ROUTING the offending nets with controlled escapes (bus planner) — a major build
  whose payoff on this congestion is uncertain. PAUSING the loop to get a user decision on how much
  further to invest (bus-planner grind vs hand-finish vs relax the gate vs different strategy) rather
  than burn more iterations on the confirmed dead end. fix_signal_vias.py kept as reference.

[2026-06-18] R0(0) — PASS-2 START: env+tooling verified, board FULL-RIPPED to a clean base, baseline
  frozen | begin the pass-2 run on the plan-first/escape-first system | (1) ENV: KRT venv
  (numpy 2.4.6/scipy 1.17.1/shapely 2.1.2) + host pcbnew 10.0.2 OK; qfn_fanout ran U3 end-to-end on
  /tmp (86 tracks = 43 stubs×2, "No endpoint collisions", reproduced the 0.4mm-pitch residual warning);
  route.py --guide-corridor ran end-to-end on /tmp (8 waypoints, layer-costs F.Cu=1.0/B.Cu=3.0). KRT
  arg gotcha logged: route.py OUTPUT+net-patterns are POSITIONAL (not --output/--nets), default
  clearance 0.25mm; net names hierarchical (/Audio/I2S_BCK). (2) CLEAN BASE: working tree already held
  a ripped board (pass-1 copper deleted, zones unfilled, 2 stray keepout rule-areas); ran
  route_pipeline rip+refill (pcb_runner-isolated) -> 0 tracks/arcs/vias, 5 zones refilled. Footprint
  hash dcb44305490d UNCHANGED, frozen .kicad_sch/.kicad_pro git-clean. (3) R1 carried over from D1
  through the rip (1.6mm 4-layer, In1 GND/In2 +3V3, F/B GND pours, USB_DIFF_90 fixed) — re-verified,
  no new work. (4) R2 EVAL (read-only): U3 19/33 cross-side — 15 firmware-movable, 4 fixed-but-benign
  (QSPI_SS/RUN/USB_DM/DP). gpio_reassigner's pinmux-legal solver is still TODO. | Δmetric: baseline
  R0(0) — completion 2.72%, unconnected 143 (baseline 147, divergence 0), via_in_pad 0, drc 0, shorts 0,
  usb_diff_paired TRUE, zones_filled_ok TRUE. **R0 EXIT GATE MET; R1 carried-verified.** PAUSED at the
  R2 remap fork for a USER decision (schematic+firmware edit is approval-gated) before any escape copper.

[2026-06-18] R2(1) — GPIO REMAP APPLIED (schematic + PCB, user-authorized, verified) | dissolve the
  worst QFN escape crossings at the source | USER chose "full remap, autonomous, no approval pauses".
  Built the toolchain: gpio_remap_solver.py (Hungarian over pad->dest distance + opposite-side penalty
  + churn, RP2040 pinmux constraints: ADC-only VBAT, I2S 3-contiguous side-set, fixed USB/QSPI/SWD/RUN/
  UART excluded), sch_pin_resolver.py (s-expr parse + union-find connectivity; cross-checked 40/43
  signal pins == PCB pad nets, the 3 gaps = SD_CD global_label + USB auto-named), gpio_remap_apply.py
  (permutes U3-pin LOCAL LABELS — the only semantically-correct remap on a function-named symbol; pure
  permutation of the same 11 label strings = no net created/destroyed). DECISION: dropped SD_CD from
  the remap (it's a global_label; mixing types adds risk for the lowest-value move) -> a clean 6-net
  remap of 11 local labels. MOVES (all firmware-legal): LED_SCK GP10->GP24, LED_DAT GP11->GP25 (PIO,
  was SPI1 - SK9822 is PIO-friendly), IR_RX GP15->GP27, SAO_SDA GP16->GP28 + SAO_SCL GP17->GP29 (GP28/29
  = hardware I2C0, still a valid instance), ~CHRG GP18->GP10. I2S left on GP6/7/8 (side-set contiguity
  honored). APPLIED to real MCU_Core.kicad_sch (11 labels) + real PCB (11 pad nets, isolated load-save).
  VERIFIED: KiCad netlister (kicad-cli) confirms all 6 nets on intended pins; ERC 73->73 (ZERO new
  violations, the 73 are pre-existing no-connect/annotation warnings); footprint hash dcb44305490d
  UNCHANGED; measure_route clean (via_in_pad 0, drc 0, shorts 0, zones filled, divergence 0). | Δmetric:
  opposite-side ("route around the chip") crossings 6->1 (only the dropped SD_CD remains); crude
  side-mismatch metric 19->17 (undersells it - it can't see opposite->adjacent for the 3 right->left
  SAO/IR_RX nets that became short top-left exits). **R2 DONE.** Next: R3 escape on the remapped board.

[2026-06-18] PASS-2 BUILD — baked the retrospective + next-pass-plan into prompt/harness/tooling
  (board untouched; full ripup happens at the start of the pass-2 run). DOCS rewritten:
  MISSION/HARNESS/PROMPT/ROUTING_SPEC/STATE to the plan-first, escape-first, KRT-full-toolbox structure
  + new ESCAPE_SPEC; phase order R0-R6 with PLANE FANOUT LAST and ESCAPE as its own phase; anti-thrash
  machinery (dead_end_detector bans a stalled approach FAMILY); Workflow-plans/Loop-executes split;
  explicit hand-off gate; pcbnew-binding checklist. TOOLS: built+tested pcb_runner.py (isolated
  load-mutate-save), dead_end_detector.py, escape_planner.py (R3 linchpin — multi-layer, PROVEN
  via_in_pad==0 on U3, DRC 78→39 residual = R3 tuning), route_pipeline.py (phase DAG, fanout LAST);
  built gpio_reassigner.py (crossing analysis: 19/33 U3 nets cross-side — quantifies the upstream lever)
  + bus_topology_planner.py (grouping: QSPI6/SD5/I2S3/SAO2/LED2); scaffolded beautifier.py; kept
  krt_bridge.py as-is; DROPPED fix_signal_vias.py. KEY VALIDATIONS: qfn_fanout exists+works (the tool
  pass 1 "never built" was shipped unused); via_in_pad solvable at route-time by construction; the GPIO
  lever is real (19 crossings). Pass-2 metrics/approaches.json start fresh (R-phase tags).

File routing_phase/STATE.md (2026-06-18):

# STATE (pointer only — durable history in LEDGER.md + metrics.jsonl + approaches.json)

Pass: **2** (plan-first, escape-first). Pass-1 history preserved in RETROSPECTIVE.md / NEXT_PASS_PLAN.md
and git. R0 (2026-06-18): board FULL-RIPPED back to placed+planes (0 tracks/arcs/vias; 5 zones refilled;
2 `(vias not_allowed)` keepout areas are rule-areas, not copper). HEAD still holds the pass-1 75.5%
routed board as the archival reference — pass-2 clean base lives uncommitted in the working tree until
this R0 commit.

Phase: **R3 — QFN escape** (next). R0 DONE, R1 carried-verified, **R2 remap DONE+APPLIED** (user
authorized full autonomy, no approval pauses). The schematic is now intentionally changed from the
design-doc GPIO map (the one allowed schematic edit); firmware must follow the remapped pin map.

R0 RESULTS (2026-06-18, clean base):
  - Env verified: KRT venv (numpy 2.4.6/scipy 1.17.1/shapely 2.1.2), host pcbnew 10.0.2, qfn_fanout
    end-to-end on /tmp (86 tracks, 43 stubs×2, "No endpoint collisions", reproduced the 0.4mm-pitch
    residual warning), route.py --guide-corridor end-to-end on /tmp (8 waypoints, layer-costs applied).
  - Clean base: rip+refill via route_pipeline (pcb_runner-isolated); footprint hash dcb44305490d
    UNCHANGED, frozen .kicad_sch/.kicad_pro git-clean.
  - Baseline measure row (R0(0)): completion 2.72%, unconnected 143 (baseline 147, divergence 0),
    via_in_pad 0, drc 0, shorts 0, usb_diff_paired TRUE, zones_filled_ok TRUE, n_footprints 83.
  - R1 (stackup/netclass) carried over from D1 through the rip — 1.6mm 4-layer, In1 GND/In2 +3V3,
    F/B GND pours filled, USB_DIFF_90 fixed. Re-verified clean; no new R1 work needed.
  - KRT invocation note: route.py takes OUTPUT + net-patterns as POSITIONALS (not --output/--nets);
    qfn_fanout DOES take --output. route.py default clearance 0.25mm. Net names are hierarchical
    (e.g. /Audio/I2S_BCK) — R4 corridor calls must use the real net names, not bare bus labels.

R2 EVAL RESULT (2026-06-18, read-only, frozen pin map): U3 = 33 signal nets, **19 cross-side**.
  - 15 firmware-MOVABLE (PIO/any-GPIO or instance-flexible): I2S_BCK/DIN/LRCK (move as a 3-contiguous
    block — PIO side-set), BTN_SYNC, SAO_GPIO1/2, SAO_SCL/SDA, IR_RX, IR_TX, LED_DAT, LED_SCK, ~CHRG,
    SD_CD, VBAT_SENSE (within ADC bank GP26-29).
  - 4 FIXED-but-benign (dedicated silicon pins): QSPI_SS (adjacent to flash), RUN (pullup stub),
    USB_DM/DP (dedicated USB pins; pass 1 routed USB 4/4 fine).
  - Remap could take 19 -> ~4, residual all non-problematic. AWAITING USER DECISION on the remap fork
    (schematic+firmware edit, approval-gated). gpio_reassigner's pinmux-legal SOLVER is still TODO —
    a trustworthy concrete proposal needs it built (RP2040 QFN pad->GPIO map + function table +
    I2S-contiguity/ADC-bank constraints).

Tooling status (this build — what's BUILT+TESTED vs SCAFFOLDED):
  KEEP (verified good): geom_route.py, route_db.py, measure_route.py, writer_lock.py.
  BUILT + TESTED: pcb_runner.py (isolated load-mutate-save; footprint-hash + frozen guard verified),
    dead_end_detector.py (anti-thrash, escalate-as-code), escape_planner.py (R3 LINCHPIN — multi-layer,
    PROVEN via_in_pad==0 by construction on U3; residual DRC = R3 tuning target, see below),
    route_pipeline.py (restructured to the phase DAG: rip→escape→bus→bulk→fanout-LAST).
  BUILT, analysis-tested (routing parts run in R2/R4 of the loop): gpio_reassigner.py (crossing
    analysis WORKS — quantified 19/33 cross-side mismatches), bus_topology_planner.py (grouping WORKS:
    QSPI6/SD5/I2S3/SAO2/LED2 + 44 singletons; corridor-route is the R4 loop step).
  SCAFFOLDED (run on routed copper, not testable until copper exists): beautifier.py.
  KEEP-AS-IS (works; kicad_parser-extractor rebuild is an R0 refinement, not blocking): krt_bridge.py.
  DROPPED: fix_signal_vias.py (confirmed dead end — git-removed).

DE-RISKING RESULTS:
  - ESCAPE (the linchpin): KRT qfn_fanout escapes U3's 43 signal pads via-in-pad-free (0 vias, F.Cu)
    BUT 0.4mm pitch → single-layer stubs 0.283mm apart → 54 clearance errs. escape_planner's multi-layer
    (alternate F.Cu-direct / B.Cu-dogbone, collision-validated) achieves **via_in_pad==0** + cut DRC
    78→39 (residual = escape-stub clearances at 0.4mm pitch). R3 ladder finishes it: finer grid /
    more-B.Cu / GPIO remap. The KEY guarantee (no via-in-pad, by construction) is proven.
  - GPIO LEVER (R2): 19 of 33 U3 signal nets are cross-side mismatches (I2S/SAO/LED/USB/SD_CD) — the
    quantified congestion cost. Strong support for the (approval-gated) GPIO remap; could close most
    of the unrouted set at the source.

Per-phase PRIMARY metric + escalation ladder (anti-thrash):
  R3 escape  — PRIMARY: via_in_pad (==0) + escaped-pin count. Ladder: qfn_fanout-multilayer →
    manual-escape-corridor-seed → R2-gpio-remap → hand-off.
  R4 bus     — PRIMARY: bus_pitch_var (≈0). Ladder: guide-corridor-bundle → krt-bus-mode →
    manual-corridor → singleton-route-the-bus.
  R5 bulk    — PRIMARY: completion_pct. Ladder: krt-route-aesthetic-knobs → small-set-ripup →
    per-net-guide-corridor → hand-off.

Next intended action:
  1. ~~**R0:** substrate + baseline~~ DONE (see R0 RESULTS).
  2. ~~**R1:** stackup/netclass~~ carried-over-verified from D1.
  3. **R2 (approval-gated) — AWAITING USER DECISION:** crossing eval done (19 cross-side, 15 movable).
     Fork presented to user: (a) build pinmux-legal solver -> concrete remap proposal -> apply (schematic
     edit, needs final sign-off); (b) route the frozen map as-is, lean on the R3 multi-layer escape
     ladder. The remap APPLY is the only schematic change allowed and is the one hard pause in the run.
  4. **R3:** escape_planner on U3 (+ J31 if needed) → escape_plan.json, via_in_pad==0, DRC-clean.
     Run on whichever pin map R2 settles on.
  5. **R4→R6** per HARNESS.

LOCKED gates: see HARNESS. via_in_pad==0 (route-time/by-construction); plane fanout LAST + keepout
ring; determinism + aesthetic render gate per phase exit; placement+schematic frozen (R2 remap = only
schematic change, with sign-off); anti-thrash families machine-enforced; hand-off gate defined.

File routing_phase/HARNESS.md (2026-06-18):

# HARNESS — Badge Routing Pass 2 (operational core)

You are the iteration engine. cwd is the repo root. Mission-control lives in `routing_phase/`;
the board is `defcon_badge/defcon_badge.kicad_pcb`. Read `MISSION.md` for the why.

## Structure: a Workflow plans, a Loop executes
- **PLANNING (R2 GPIO eval, R3 escape, R4 bus/topology) is a deterministic WORKFLOW**, run once,
  order-dependent, producing a frozen plan artifact (`escape_plan.json`, `bus_plan.json`,
  `gpio_remap.json`). It MUST complete before execution. These never belonged in a wake-up loop —
  that is why pass 1 never did escape/bus planning (always "next iteration").
- **EXECUTION (R5 bulk singleton route + beautify, R6 fanout/pour/verify) is the self-scheduling
  LOOP** with the anti-thrash brakes below. R0/R1 setup may be either.

## LOCKED resolutions (do not route around)
1. **Authoritative geometry + single writer.** All board reads/writes via `geom_route.py` (pcbnew),
   guarded by `writer_lock`. Every mutating tool calls the shared `pcb_runner.py` isolated
   load-mutate-save (see pcbnew checklist). KRT solves; pcbnew writes (the `krt_bridge` seam — KRT
   writes net NAMES, KiCad 10 wants CODES). Never text-edit s-exprs for geometry.
2. **via_in_pad == 0 is solved at ROUTE TIME, by construction.** Escape every pad on its own layer;
   place any via in OPEN space, never on a pad. Post-hoc via-moving is a CONFIRMED DEAD END (pass 1,
   4 variants — moving a via drags its route → needs re-routing → clearance/shorts). `fix_signal_vias.py`
   is DELETED; do not resurrect the approach.
3. **Plane fanout is LAST (R6), with a keepout ring** around escaped QFN pins. Signals escape +
   route first. This encodes pass 1's signals-first lesson as structure.
4. **Completion truth = DRC + a divergence guard** (`measure_route`: pcbnew unconnected vs
   kicad-cli `unconnected_items`; if they disagree, trust DRC).
5. **Determinism is un-loosenable** (route-twice → identical, gated where copper exists).
6. **Aesthetic render-gate every phase exit** — metrics (bus_pitch_var≈0, off_axis==0, acute low,
   via_count budget) AND render F.Cu/B.Cu/3D and LOOK. A phase cannot exit reading machine-generated.
7. **Locked gates/definitions — tighten only.** A definition change or capability deletion to pass
   is a `REVIEW:` + human sign-off.

## Per-iteration procedure (execution loop)
0. **Preflight:** `pcb_runner` writer-lock check; if KiCad holds the board open, read-only iteration.
1. **Read:** MISSION, this file, `routing_rules.md`, `badge_hw_design.md`, the relevant SPEC.
2. **Load memory:** tail of `LEDGER.md` + ALL of `metrics.jsonl` + `approaches.json` (the
   tried-approaches ledger) + `STATE.md` (phase pointer, this phase's PRIMARY metric + escalation ladder).
3. **Dead-end preflight (ANTI-THRASH, HARD):** run `dead_end_detector.py`. It reads `metrics.jsonl`
   + `approaches.json`. If the action you intend uses an approach FAMILY that is `status:banned`, the
   iteration is REFUSED — take the next rung of the phase's pre-declared escalation ladder instead.
   (See "Anti-thrash" — this is code, not advice.)
4. **Measure:** `measure_route.py … --append metrics.jsonl`; check `unconnected_divergence==0`.
5. **Convergence check** over the last K=3 rows tagged with the SAME approach family, judged ONLY
   against the phase's declared PRIMARY metric: <2% gain for 3 rows of one family → that family is
   auto-BANNED in `approaches.json`; you MUST switch to the next ladder rung. A "finding-only" or
   "refactor" iteration is allowed but does NOT reset the dead-end counter and does NOT count as
   progress.
6. **One highest-leverage action**, declaring its approach `family` tag up front.
7. **Execute via tools** (pcb_runner-isolated writes; update `route_db`).
7b. **Phase-exit gate:** aesthetic metrics + determinism (where copper exists) + render-and-look.
8. **Commit + log:** `R?(N): summary`; one `LEDGER.md` line; update `approaches.json`; confirm the
   `metrics.jsonl` row.
9. **Schedule next** (`ScheduleWakeup` with `PROMPT.md`), OR if the HAND-OFF gate fired, STOP +
   produce the hand-off package.

## Anti-thrash (machine-enforced — this is the #1 process fix)
- **`approaches.json`** — one record per (phase, family): {first_iter, last_iter, best_primary,
  status: active|banned|champion, reason}. Keyed on a COARSE family tag the agent declares (e.g.
  `posthoc-via-move`, `krt-default-route`, `escape-multilayer`), so cosmetic re-skins of a dead
  approach are caught (the 4 via-fixer variants were ONE family).
- **Ban rule:** 3 same-family iterations with <2% primary-metric gain → banned; preflight refuses it.
- **Budget:** ≤3 iterations per family before it must show >2% gain or auto-ban.
- **Escalation ladder, pre-declared per phase in STATE.md** — when a family is banned, take the NEXT
  rung automatically (don't invent a new variant of the banned rung). E.g. R3 ladder: KRT qfn_fanout
  multi-layer → manual escape-corridor seeding → GPIO remap (R2) → hand-off.
- **Root-cause gate:** retrying a family already in the ledger requires writing a one-line
  falsifiable hypothesis ("differs by X, predicted to move M by N"); two misses → ban.

## pcbnew binding checklist (BAKE IN from R0 — pass 1 rediscovered these the hard way)
- ONE LoadBoard + ONE SaveBoard per process; a 2nd in-process load corrupts the swig registry. Every
  mutation goes through `pcb_runner.py` (run-snippet-isolated).
- `os._exit(0)` immediately after SaveBoard (heavy mutate-then-save segfaults during teardown AFTER
  the file is written). Do NOT gate success on the exit code — check the file/metrics.
- `safe_board` (read from a /tmp project copy) for ALL read-only analysis — pcbnew flushes BOM field
  defs into the frozen .kicad_pro on exit otherwise.
- Frozen-file git guard after every iteration: assert `.kicad_sch`/`.kicad_pro` git-clean + footprint
  hash unchanged; auto-revert stray rewrites. Run ERC/DRC only on /tmp project copies (with the .kicad_pro).
- Suppress swig assert noise (grep -vE 'PROPERTY_ENUM|memory leak') so real output isn't buried.
- Refill zones in the SAME isolated save process as the copper edit.
- KRT rip-up is pathologically slow on this board — prefer escape+bus planning; if rip-up is needed,
  scope it to a SMALL net set (`--rip-existing-nets PATTERN`), never all-nets.

## Phase exit gates
- **R0 Setup:** `measure_route` emits full schema + baseline row; `pcb_runner` used by geom/bridge;
  KRT `qfn_fanout.py` + a `--guide-corridor` invocation verified runnable on /tmp; divergence==0.
- **R1 Stackup/netclass:** real 4-layer (In1 GND/In2 +3V3, F/B GND pours), USB_DIFF_90 pattern+width
  fixed; zones fill; unrouted DRC clean of NEW stackup errors; baseline frozen.
- **R2 GPIO eval:** `gpio_reassigner` reports current-vs-best QFN-escape crossing count + a ranked
  remap proposal with the reduction quantified; USER adjudication recorded (apply+re-sync OR proceed)
  BEFORE any escape copper. If applied: schematic re-synced, footprints byte-frozen.
- **R3 QFN escape:** every QFN signal pin escaped to open space; **via_in_pad==0** on the escaped set
  (vias in open space, not on pads); escapes DRC-clean (multi-layer so 0.4mm-pitch stubs clear the
  0.15mm rule); no signal on an inner plane; determinism passes; render = clean radial pattern.
- **R4 Bus planning:** named buses (SD/I2S/QSPI/SAO) routed as constant-pitch bundles in corridors;
  `bus_pitch_var`≈0; acute/off-axis low on bused copper; determinism; render = hand-drawn bundles.
- **R5 Bulk + beautify:** completion==100 OR a documented BLOCKER + hand-off package; via_in_pad==0;
  shorts==0; routing drc_errors==0; off_axis==0; acute→0; via_count in budget; determinism_ok.
- **R6 Fanout/pour/verify:** plane fanout placed (keepout ring honored, NO via-in-pad, no fenced
  escape); zones filled + GND-stitched; ALL hard gates pass after fill; incremental 1-net re-route
  demonstrated; human render confirms hand-designed — OR the hand-off package is delivered.

## Hand-off gate (define the stop — pass 1 had none short of 100%)
Trigger: completion <2% gain over the last 6 iterations AND every R5-ladder family is `banned` AND
the unrouted nets are flagged intrinsic-QFN-congestion (not capacity/ordering). On trigger: STOP
scheduling; produce the HAND-OFF PACKAGE — (a) the board at its best clean state (escapes+buses done,
planes intact, DRC-clean on the routed subset, determinism verified); (b) ranked unrouted nets with
escape endpoints + destination zones; (c) per-net corridor hints; (d) the note that KiCad interactive
push-and-shove is the right tool for the last few. The loop does the decomposable 75–90%; the
congested handful is a human's.

## Tools (keep / rebuild / drop)
- KEEP: `geom_route.py`, `route_db.py`, `measure_route.py`, `writer_lock.py`.
- REBUILD: `route_pipeline.py` (phase DAG), `krt_bridge.py` (extractor via KRT `kicad_parser`),
  `rework_stackup.py` (parameterized, once at R1).
- DROP: `fix_signal_vias.py` (dead end — deleted).
- ADD: `pcb_runner.py`, `dead_end_detector.py`, `escape_planner.py` (the linchpin), `bus_topology_planner.py`,
  `gpio_reassigner.py`, `beautifier.py`.

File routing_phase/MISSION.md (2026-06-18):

# MISSION — Badge Routing, Pass 2 (plan-first, escape-first)

A clean-slate re-run of the DEF CON badge routing, rebuilt around the lessons in
`RETROSPECTIVE.md` + `NEXT_PASS_PLAN.md`. Pass 1 reached a structurally-correct **75%** then
ground on the RP2040 QFN-56 escape congestion. This pass fixes that **by construction**.

## What you are building
A routing run that produces a **100%-routed (or cleanly-handed-off), DRC-clean, via-in-pad-free,
hand-designed-looking** board from the FROZEN, user-approved placement — by **planning before
routing**, not correcting reactively. The tools are the deliverable; the board is the test case.

## The four goals (unchanged, all gated)
1. **Aesthetic** — looks hand-designed (constant-pitch buses, clean radial QFN escapes, minimal
   structured vias). Gated by metrics AND a render-and-look at every phase exit.
2. **Deterministic** — same inputs → byte-identical copper (route-twice gate).
3. **Re-runnable / incremental** — a part/pin swap re-routes only changed nets (`route_db`).
4. **Ours, but not reinvented** — built on KRT's *full* toolbox (not a custom router).
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

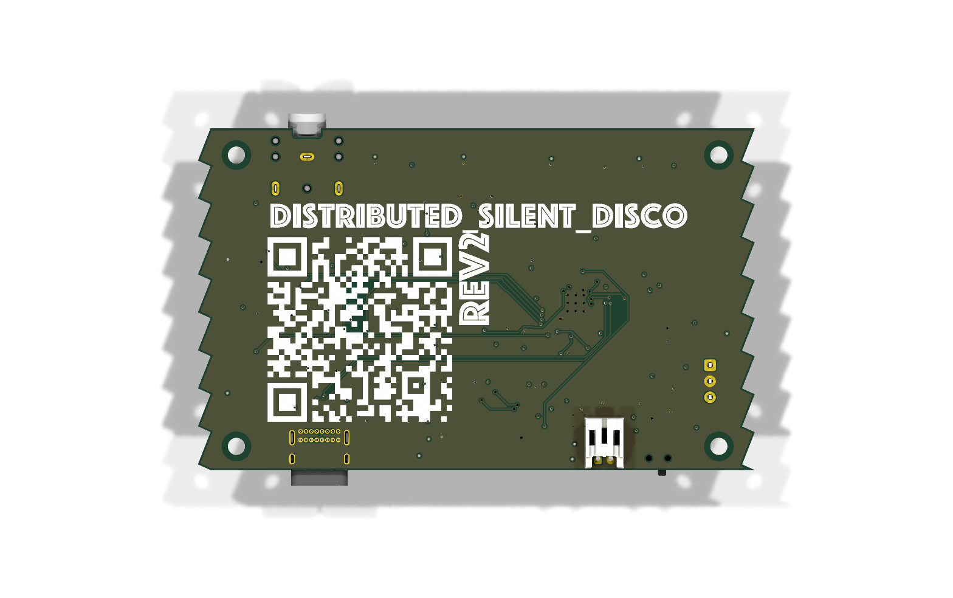
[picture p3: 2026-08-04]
docs/back_3d.png

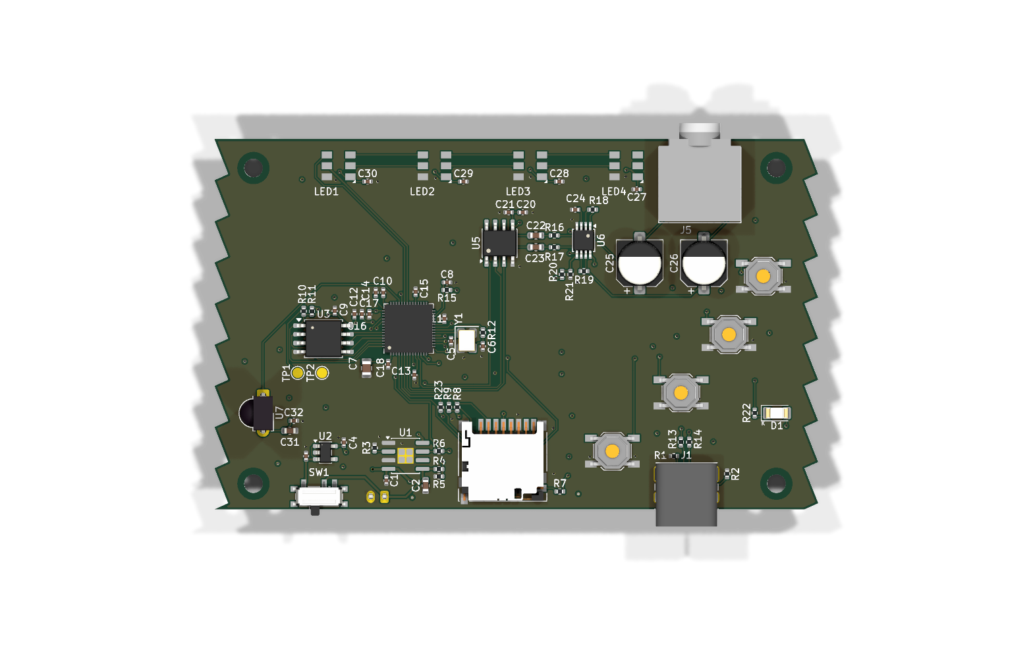
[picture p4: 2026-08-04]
docs/front_3d.png

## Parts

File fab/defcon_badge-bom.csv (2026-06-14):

Reference | Value | Footprint | MPN | LCSC
C1,C4,C17 | 10u | Capacitor_SMD:C_0805_2012Metric
C2,C3 | 15p | Capacitor_SMD:C_0402_1005Metric
C5-C7,C9,C11,C12,C14,C16,C40,C70 | 100n | Capacitor_SMD:C_0402_1005Metric | CL05B104KO5NNNC | C1525
C8,C10,C20,C22,C23 | 1u | Capacitor_SMD:C_0402_1005Metric | CL05A105KP5NNNC | C52923
C21,C42,C43,C71 | 10u | Capacitor_SMD:C_0603_1608Metric | CL10A106KP8NNNC | C19702
C41,C44 | 10u | Capacitor_SMD:C_0402_1005Metric
C45,C46 | 220u | Capacitor_SMD:CP_Elec_6.3x5.4
C60-C63 | 10n | Capacitor_SMD:C_0402_1005Metric | CL05B103KB5NNNC | C57112
D20 | IR LED 940 nm | LED_SMD:LED_0805_2012Metric | IR15-21C/TR8 | C72037
H1-H4 | MountingHole | MountingHole:MountingHole_2.7mm_M2.5
J10 | USB_C_Receptacle_USB2.0_16P | Connector_USB:USB_C_Receptacle_GCT_USB4085 | USB4085 | C404969
J11 | JST-PH 2P | Connector_JST:JST_PH_S2B-PH-K_1x02_P2.00mm_Horizontal | S2B-PH-K-S | C131350
J20 | PJ-320A | Connector_Audio:Jack_3.5mm_QingPu_WQP-PJ398SM_Vertical_CircularHoles | PJ-320A | C720466
J30 | SAO 2x3 | Connector_PinHeader_2.54mm:PinHeader_2x03_P2.54mm_Vertical | PRPC003DAAN-RC | C124378
J31 | microSD | Connector_Card:microSD_HC_Hirose_DM3D-SF | TF-PUSH-A | C146885
J32 | UART debug | Connector_PinHeader_2.54mm:PinHeader_1x03_P2.54mm_Vertical
J33 | Dev/SWD header | Connector_PinHeader_2.54mm:PinHeader_1x05_P2.54mm_Vertical
LED20-LED23 | SK9822-EC20 | LED_SMD:LED_SK6812_PLCC4_5.0x5.0mm_P3.2mm | SK9822-EC20 | C2890389
R1,R5 | 1k | Resistor_SMD:R_0402_1005Metric
R2 | DNF | Resistor_SMD:R_0402_1005Metric
R3,R4 | 27 | Resistor_SMD:R_0402_1005Metric
R10,R11 | 5.1k | Resistor_SMD:R_0402_1005Metric | RC0402FR-075K1L | C23186
R12 | 2.4k | Resistor_SMD:R_0402_1005Metric | RC0402FR-072K4L | C25789
R13-R15,R22,R23 | 100k | Resistor_SMD:R_0402_1005Metric | RC0402FR-07100KL | C25741
R20,R21 | 47k | Resistor_SMD:R_0402_1005Metric | RC0402FR-0747KL | C25819
R24,R25 | 10k | Resistor_SMD:R_0402_1005Metric | RC0402FR-0710KL | C25744
R30 | 150 | Resistor_SMD:R_0402_1005Metric
R40,R41 | 4.7k | Resistor_SMD:R_0402_1005Metric | RC0402FR-074K7L | C25900
SW1 | SS-12D00 | Button_Switch_SMD:SW_SPDT_PCM12 | MSK-12C02 | C431540
SW20-SW22 | TS-1187A | Button_Switch_SMD:SW_SPST_TL3342 | TS-1187A-B-A-B | C455257
U2 | W25Q16JVUXIQ | Package_SON:Winbond_USON-8-1EP_3x2mm_P0.5mm_EP0.2x1.6mm
U3 | RP2040 | RP2040_minimal:RP2040-QFN-56
U10 | TP4056 | Package_SO:SOIC-8_3.9x4.9mm_P1.27mm | TP4056 | C16581
U11 | ME6211C33M5G | Package_TO_SOT_SMD:SOT-23-5 | ME6211C33M5G | C82942
U20 | TM8211 | Package_SO:SOIC-8_3.9x4.9mm_P1.27mm | TM8211 | C82978
U21 | TDA1308 | Package_SO:SOIC-8_3.9x4.9mm_P1.27mm | TDA1308AT | C8434
U30 | TSOP4838 | OptoDevice:Vishay_MINICAST-3Pin | TSOP4838 | C90701
Y1 | ABM8-272-T3 | Crystal:Crystal_SMD_3225-4Pin_3.2x2.5mm

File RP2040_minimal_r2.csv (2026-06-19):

Reference | Qty | Value | DNP | Exclude from BOM | Exclude from Board | Footprint | Datasheet
C1,C4,C17 | 3 | 10u |  |  |  | Capacitor_SMD:C_0805_2012Metric
C2,C3 | 2 | 15p |  |  |  | Capacitor_SMD:C_0402_1005Metric
C5,C6,C7,C9,C11,C12,C13,C14,C15,C16 | 10 | 100n |  |  |  | Capacitor_SMD:C_0402_1005Metric
C8,C10 | 2 | 1u |  |  |  | Capacitor_SMD:C_0402_1005Metric
H1,H2,H3,H4 | 4 | MountingHole |  |  |  | MountingHole:MountingHole_2.7mm_M2.5
J1 | 1 | USB_B_Micro |  |  |  | RP2040_minimal:USB_Micro-B_Amphenol_10103594-0001LF_Horizontal_modified
J2 | 1 | Conn_01x02 |  |  |  | Connector_PinHeader_2.54mm:PinHeader_1x02_P2.54mm_Vertical
J3,J4 | 2 | Conn_02x18_Odd_Even |  |  |  | Connector_PinHeader_2.54mm:PinHeader_2x18_P2.54mm_Vertical
R1,R5 | 2 | 1k |  |  |  | Resistor_SMD:R_0402_1005Metric
R2 | 1 | DNF |  |  |  | Resistor_SMD:R_0402_1005Metric
R3,R4 | 2 | 27 |  |  |  | Resistor_SMD:R_0402_1005Metric
U1 | 1 | NCP1117-3.3_SOT223 |  |  |  | Package_TO_SOT_SMD:SOT-223-3_TabPin2 | http://www.onsemi.com/pub_link/Collateral/NCP1117-D.PDF
U2 | 1 | W25Q128JVS |  |  |  | Package_SO:SOIC-8_5.23x5.23mm_P1.27mm | http://www.winbond.com/resource-files/w25q128jv_dtr%20revc%2003272018%20plus.pdf
U3 | 1 | RP2040 |  |  |  | RP2040_minimal:RP2040-QFN-56
Y1 | 1 | ABM8-272-T3 |  |  |  | Crystal:Crystal_SMD_3225-4Pin_3.2x2.5mm

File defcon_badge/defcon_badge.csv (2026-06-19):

Reference | Qty | Value | DNP | Exclude from BOM | Exclude from Board | Footprint | Datasheet
C1,C17 | 2 | 1u |  |  |  | Capacitor_SMD:C_0805_2012Metric
C2,C3 | 2 | 15p |  |  |  | Capacitor_SMD:C_0402_1005Metric
C4 | 1 | 10u |  |  |  | Capacitor_SMD:C_0805_2012Metric
C5,C6,C7,C9,C11,C12,C14,C16,C40,C70 | 10 | 100n |  |  |  | Capacitor_SMD:C_0402_1005Metric
C8,C10,C20,C22,C23 | 5 | 1u |  |  |  | Capacitor_SMD:C_0402_1005Metric
C21,C42,C43,C71 | 4 | 10u |  |  |  | Capacitor_SMD:C_0603_1608Metric
C41,C44 | 2 | 10u |  |  |  | Capacitor_SMD:C_0402_1005Metric
C45,C46 | 2 | 220u |  |  |  | Capacitor_SMD:CP_Elec_6.3x5.4
C60,C61,C62,C63 | 4 | 10n |  |  |  | Capacitor_SMD:C_0402_1005Metric
D20 | 1 | IR LED 940 nm |  |  |  | badge:LED_IR_1206_3216Metric
H1,H2,H3,H4 | 4 | MountingHole |  |  |  | MountingHole:MountingHole_2.7mm_M2.5
J10 | 1 | USB_C_Receptacle_USB2.0_16P |  |  |  | Connector_USB:USB_C_Receptacle_GCT_USB4085
J11 | 1 | JST-PH 2P |  |  |  | Connector_JST:JST_PH_S2B-PH-K_1x02_P2.00mm_Horizontal
J20 | 1 | SJ1-3523N |  |  |  | Connector_Audio:Jack_3.5mm_CUI_SJ1-3523N_Horizontal
J30 | 1 | SAO 2x3 |  |  |  | Connector_PinHeader_2.54mm:PinHeader_2x03_P2.54mm_Vertical
J31 | 1 | microSD |  |  |  | Connector_Card:microSD_HC_Hirose_DM3D-SF
LED20,LED21,LED22,LED23 | 4 | SK9822 |  |  |  | badge:LED_SK9822_5050
R1,R5 | 2 | 1k |  |  |  | Resistor_SMD:R_0402_1005Metric
R2 | 1 | DNF |  |  |  | Resistor_SMD:R_0402_1005Metric
R3,R4 | 2 | 27 |  |  |  | Resistor_SMD:R_0402_1005Metric
R6,R24,R25,R42 | 4 | 10k |  |  |  | Resistor_SMD:R_0402_1005Metric
R10,R11 | 2 | 5.1k |  |  |  | Resistor_SMD:R_0402_1005Metric
R12 | 1 | 2.4k |  |  |  | Resistor_SMD:R_0402_1005Metric
R13,R14,R15,R22,R23 | 5 | 100k |  |  |  | Resistor_SMD:R_0402_1005Metric
R20,R21 | 2 | 47k |  |  |  | Resistor_SMD:R_0402_1005Metric
R30 | 1 | 150 |  |  |  | Resistor_SMD:R_0402_1005Metric
R40,R41 | 2 | 4.7k |  |  |  | Resistor_SMD:R_0402_1005Metric
SW1 | 1 | SS-12D00 |  |  |  | Button_Switch_SMD:SW_SPDT_PCM12
SW20,SW21,SW22,SW23 | 4 | TS-1187A |  |  |  | Button_Switch_SMD:SW_SPST_TL3342
TP1 | 1 | BOOTSEL |  |  |  | TestPoint_Pad_D1.5mm
TP2 | 1 | GND |  |  |  | TestPoint_Pad_D1.5mm
U2 | 1 | W25Q16JVUXIQ |  |  |  | Package_SON:Winbond_USON-8-1EP_3x2mm_P0.5mm_EP0.2x1.6mm | http://www.winbond.com/resource-files/w25q128jv_dtr%20revc%2003272018%20plus.pdf
U3 | 1 | RP2040 |  |  |  | RP2040_minimal:RP2040-QFN-56
U10 | 1 | TP4056 |  |  |  | Package_SO:HSOP-8-1EP_3.9x4.9mm_P1.27mm_EP2.3x2.3mm_ThermalVias
U11 | 1 | ME6211C33M5G |  |  |  | Package_TO_SOT_SMD:SOT-23-5
U20 | 1 | TM8211 |  |  |  | Package_SO:SOIC-8_3.9x4.9mm_P1.27mm
U21 | 1 | TDA1308 |  |  |  | Package_SO:SOIC-8_3.9x4.9mm_P1.27mm
U30 | 1 | TSOP4838 |  |  |  | OptoDevice:Vishay_MINICAST-3Pin
Y1 | 1 | ABM8-272-T3 |  |  |  | Crystal:Crystal_SMD_3225-4Pin_3.2x2.5mm

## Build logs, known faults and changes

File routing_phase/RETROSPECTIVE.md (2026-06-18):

# Routing Phase (Phase D) — Retrospective

A triage of the autonomous routing run: what we ended with, what went right, what went wrong,
and where the tooling fell short. No recommendations here — just hits, misses, and diagnosis.
Scope: the routing session (13 loop iterations, D0→D3). It built on an already-good schematic +
frozen, user-approved placement from prior sessions.

---

## Final state (the facts)

- **~75.5% routed.** 36 of ~147 connections remain (started 218 before the planes carried GND/+3V3).
- **Routed & correct:** USB D+/D− diff pair (4/4, in its netclass), the RP2040 core decoupling, the
  power chain, most of the audio chain, the LED chain, and the plane fanout (GND + +3V3 to their
  inner planes). Placement never moved a hair; the schematic stayed byte-identical the whole run.
- **Not routed (the QFN-escape casualties):** the **microSD bus** (SD_SCK/MOSI/MISO/CS + SD_CD —
  all 5), the **I2S audio bus** (DIN/BCK/LRCK), the **SAO header** (SDA + 2 GPIO), QSPI_SCLK/QSPI_SS,
  IR_TX, LED_SCK, VBAT_SENSE, AMP_OUTL, +1V1, BTN_SYNC. ~14 of the 36 are minor plane-stitch gaps.
- **Open DRC:** 2 via-to-via clearance + 11 "via-in-pad" (signal layer-change vias landing on
  passive pads). 0 shorts.
- **Stack:** reworked to a real 4-layer (In1 GND / In2 +3V3 planes intact, signals on F.Cu/B.Cu).
- **Via count ~169** — heavy, and mostly the plane fanout (a via per GND/+3V3 pad). Your instinct
  ("a lot of vias") is right: a human would lean on the F.Cu ground pour's pad connections and
  share/stitch fewer vias. The fanout was correct but generous.

The common thread on every unrouted net: they originate at the **RP2040 QFN-56** in the board
center and have to escape a congested pin field to reach the edges. That one geometric reality
is the whole story of the back half.

---

## What went well (the hits)

1. **The engine call held up.** Choosing KiCadRoutingTools over Freerouting, and building our own
   harness *on* it, was sound — KRT is deterministic, native-KiCad, and routed the bulk in seconds.
   The board you're looking at is largely its work, shaped by our layer. (You were right to trust it.)
2. **The placement & schematic were never harmed.** Every board write was verified footprint-frozen
   (a hash check) and the schematic/project diff stayed clean. The "frozen, authoritative-geometry,
   single-writer" discipline carried over from placement and did its job — zero corruption across 13
   iterations of heavy mutation.
3. **Measure-everything caught real defects before they shipped.** Three genuinely-bad things were
   found *by the metrics*, not by luck:
   - signals routed straight across the GND/+3V3 reference planes (a real signal-integrity flaw),
   - the USB diff-pair netclass pointing at net names that didn't exist (so the pair was silently
     un-classed),
   - via-in-pad being introduced by the fanout.
   A "looks done" autorouter run would have hidden all three.
4. **The KRT-as-solver bridge.** When KRT's *writer* turned out to be incompatible with KiCad 10
   (it writes net *names* where KiCad wants net *codes*), instead of abandoning it we made it a
   solver only — extract its geometry, re-emit through our own pcbnew writer. That single seam is
   what let us keep KRT's intelligence behind a board KiCad can actually open. Clean save.
5. **The "signals-first" reordering.** The biggest single jump (33%→73%) came from realizing the
   plane fanout was fencing the QFN's signal pins in, and re-ordering to route signals first. Good
   diagnosis, real payoff.
6. **Re-runnability was built in early.** The `route_db` (nets keyed by a stable pad-set signature,
   not the churning net name) means a future part swap re-routes only what changed. It's there and
   tested even though we never needed it yet.
7. **The instrument itself.** `measure_route.py` gives an honest, DRC-backed scorecard every
   iteration — completion %, via-in-pad, layer balance, diff-pair skew, etc. The whole run was
   legible because of it.

---

## What didn't go well (the misses)

1. **The 75% plateau — five iterations, ~no completion gain.** After the 33%→73% jump, iterations
   D3(1)–D3(5) moved completion 73→75.5% while burning a lot of effort. The back half was a grind,
   and several iterations produced *findings* (or dead-ends) rather than routed nets.
2. **A wrong hypothesis cost two iterations.** D3(1) diagnosed the B.Cu-underuse as "the outer
   ground pours block the bottom layer" — confidently, and **wrong**. D3(2) disproved it (the real
   lever was a layer-cost penalty) and corrected course. The metrics caught the error, but only
   after a full iteration spent acting on it.
3. **The signals-on-planes flaw lived for several iterations.** It was introduced back at D2(4)
   (the router defaulted to using all 4 copper layers) and wasn't noticed until D3(3). For a few
   commits the "73% clean" board was quietly carving up its own reference planes.
4. **The via-in-pad post-fixer was a ~2-iteration dead end.** I built a tool to nudge vias off pads,
   then chased it through four variants (tiny moves, track-aware, full-clearance, DRC-gated) — each
   either left vias on pads or created clearance/short violations. The honest conclusion ("you
   can't patch this after the fact; it's a routing-time problem") was reachable earlier than I
   reached it. I over-invested in a losing approach before calling it.
5. **The QFN escape was never solved.** The microSD/I2S/SAO/QSPI failures are all the same problem,
   and we never built the thing that would address it (a route-time escape/bus planner). It stayed
   on the "next iteration" list the entire run and never got built.
6. **The via budget is high and was never optimized.** 169 vias, fanout-dominated, with no pass to
   reduce them. We measured it but never acted on it.
7. **The aesthetic goal — the whole "not-Freerouting" premise — was never reached.** The board is
   *connected* where it's routed, but it still reads as autorouted (high acute-angle count, no clean
   bundles). The bus planner that was supposed to deliver "hand-designed" was deferred to the end
   and never started.

---

## Tooling gaps (what I needed and didn't have)

- **An escape-aware / bus router (ours).** The single biggest missing piece. KRT has no via-in-pad
  avoidance and no way to say "escape this pad on its own layer, then via in open space." That one
  capability is what the unrouted nets and the via-in-pad both needed, and it never existed.
- **A DRC-aware geometry editor.** The via-fixer kept failing because moving a via in a congested
  area is really mini-routing — you can't legally place copper without pathfinding around obstacles.
  I had a blind placer; I needed a tiny router. (KiCad's interactive push-and-shove *is* exactly
  this tool, and it's a human-driven one.)
- **A faster/controllable KRT.** Its rip-up/reroute mode is pathologically slow on this board
  (minutes, frequent timeouts), so we couldn't lean on the one feature that resolves congestion.
  Several iterations lost time to runs that had to be killed.
- **A clean pcbnew scripting substrate.** A surprising amount of friction came from the KiCad Python
  binding: it segfaults on heavy mutate-then-save in one process, corrupts its object registry on a
  second board-load, flushes BOM fields into the project file on exit, and floods logs with
  harmless asserts. Each was diagnosed and worked around, but collectively they were a tax on every
  board-writing tool.

---

## Timeline read: where the effort actually went

- **D0–D1 (5 commits): foundation — efficient and clean.** Instrument, incremental engine, stackup
  rework, USB netclass fix. Steady, no wasted motion. Completion still 0% (correctly — no routing yet).
- **D2 (4 commits + the via-in-pad gate): the productive middle.** The KRT bridge, the plane fanout
  (→33%), and the signals-first reorder (→73%). This is where most of the actual routing happened
  and where the run looked healthy.
- **D3 (5 commits): the grind.** 73→75.5%. Diagnosis, one wrong turn, the signals-on-planes fix
  (real and important, but a *correction*, not forward progress), and the via-fixer dead end. This
  is where the autonomous loop hit the wall and kept circling it.

The shape of it: **front-loaded value, back-loaded thrash.** The loop excelled at the parts that
decompose into clear measurable steps (build instrument, fix a netclass, apply a fanout) and
struggled exactly where PCB routing is hard for *everyone* — congested escape — which doesn't yield
to "measure → one move → repeat."

---

## The one-line diagnosis

We built a strong, honest, reusable routing *system* and got the board to a clean, structurally-correct
75% — then spent the back third grinding on the QFN-escape congestion, which is precisely the kind of
problem an autorouter (and an autonomous loop) is worst at and a human with an interactive router is
best at. The biggest *miss* and the biggest *gap* are the same thing: the route-time escape planner that
would have unblocked the last 25%, and the aesthetic pass, were always "next" and never got built.

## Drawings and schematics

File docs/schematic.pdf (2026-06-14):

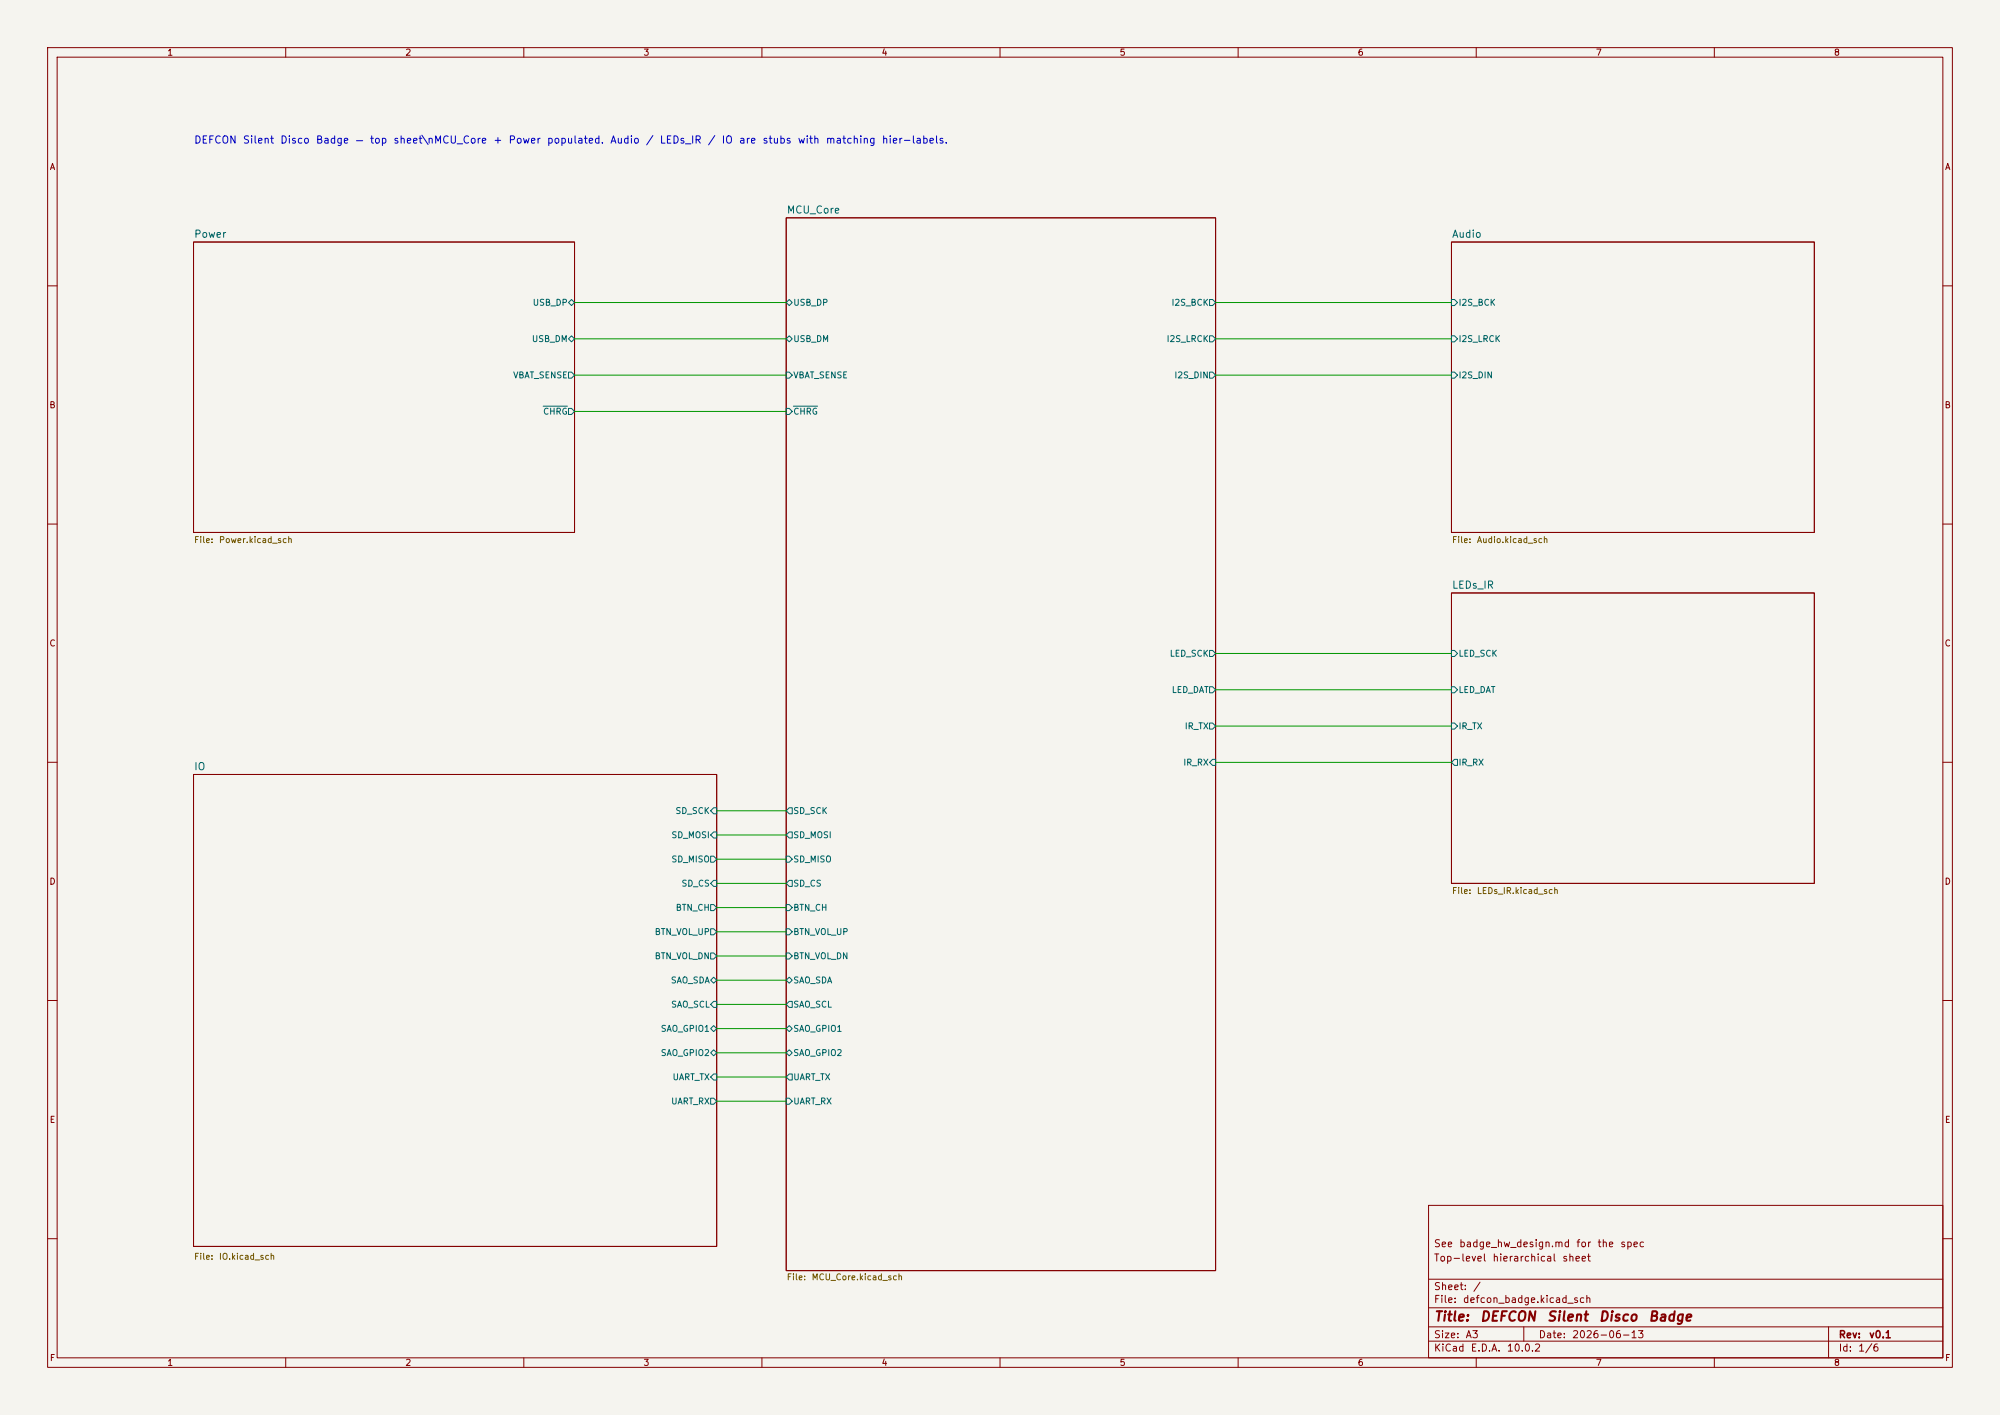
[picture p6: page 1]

VBAT_SENSE CHRG Power File: Power.kicad_sch DEFCON Silent Disco Badge — top sheet\nMCU_Core + Power populated. Audio / LEDs_IR / IO are stubs with matching hier-labels.

See badge_hw_design.md for the spec
Top-level hierarchical sheet

Sheet: /
File: defcon_badge.kicad_sch
Title: DEFCON Silent Disco Badge

Size: A3 | Rev: v0.1 | F Date: 2026-06-13
KiCad E.D.A. 10.0.2 | Id: 1/6

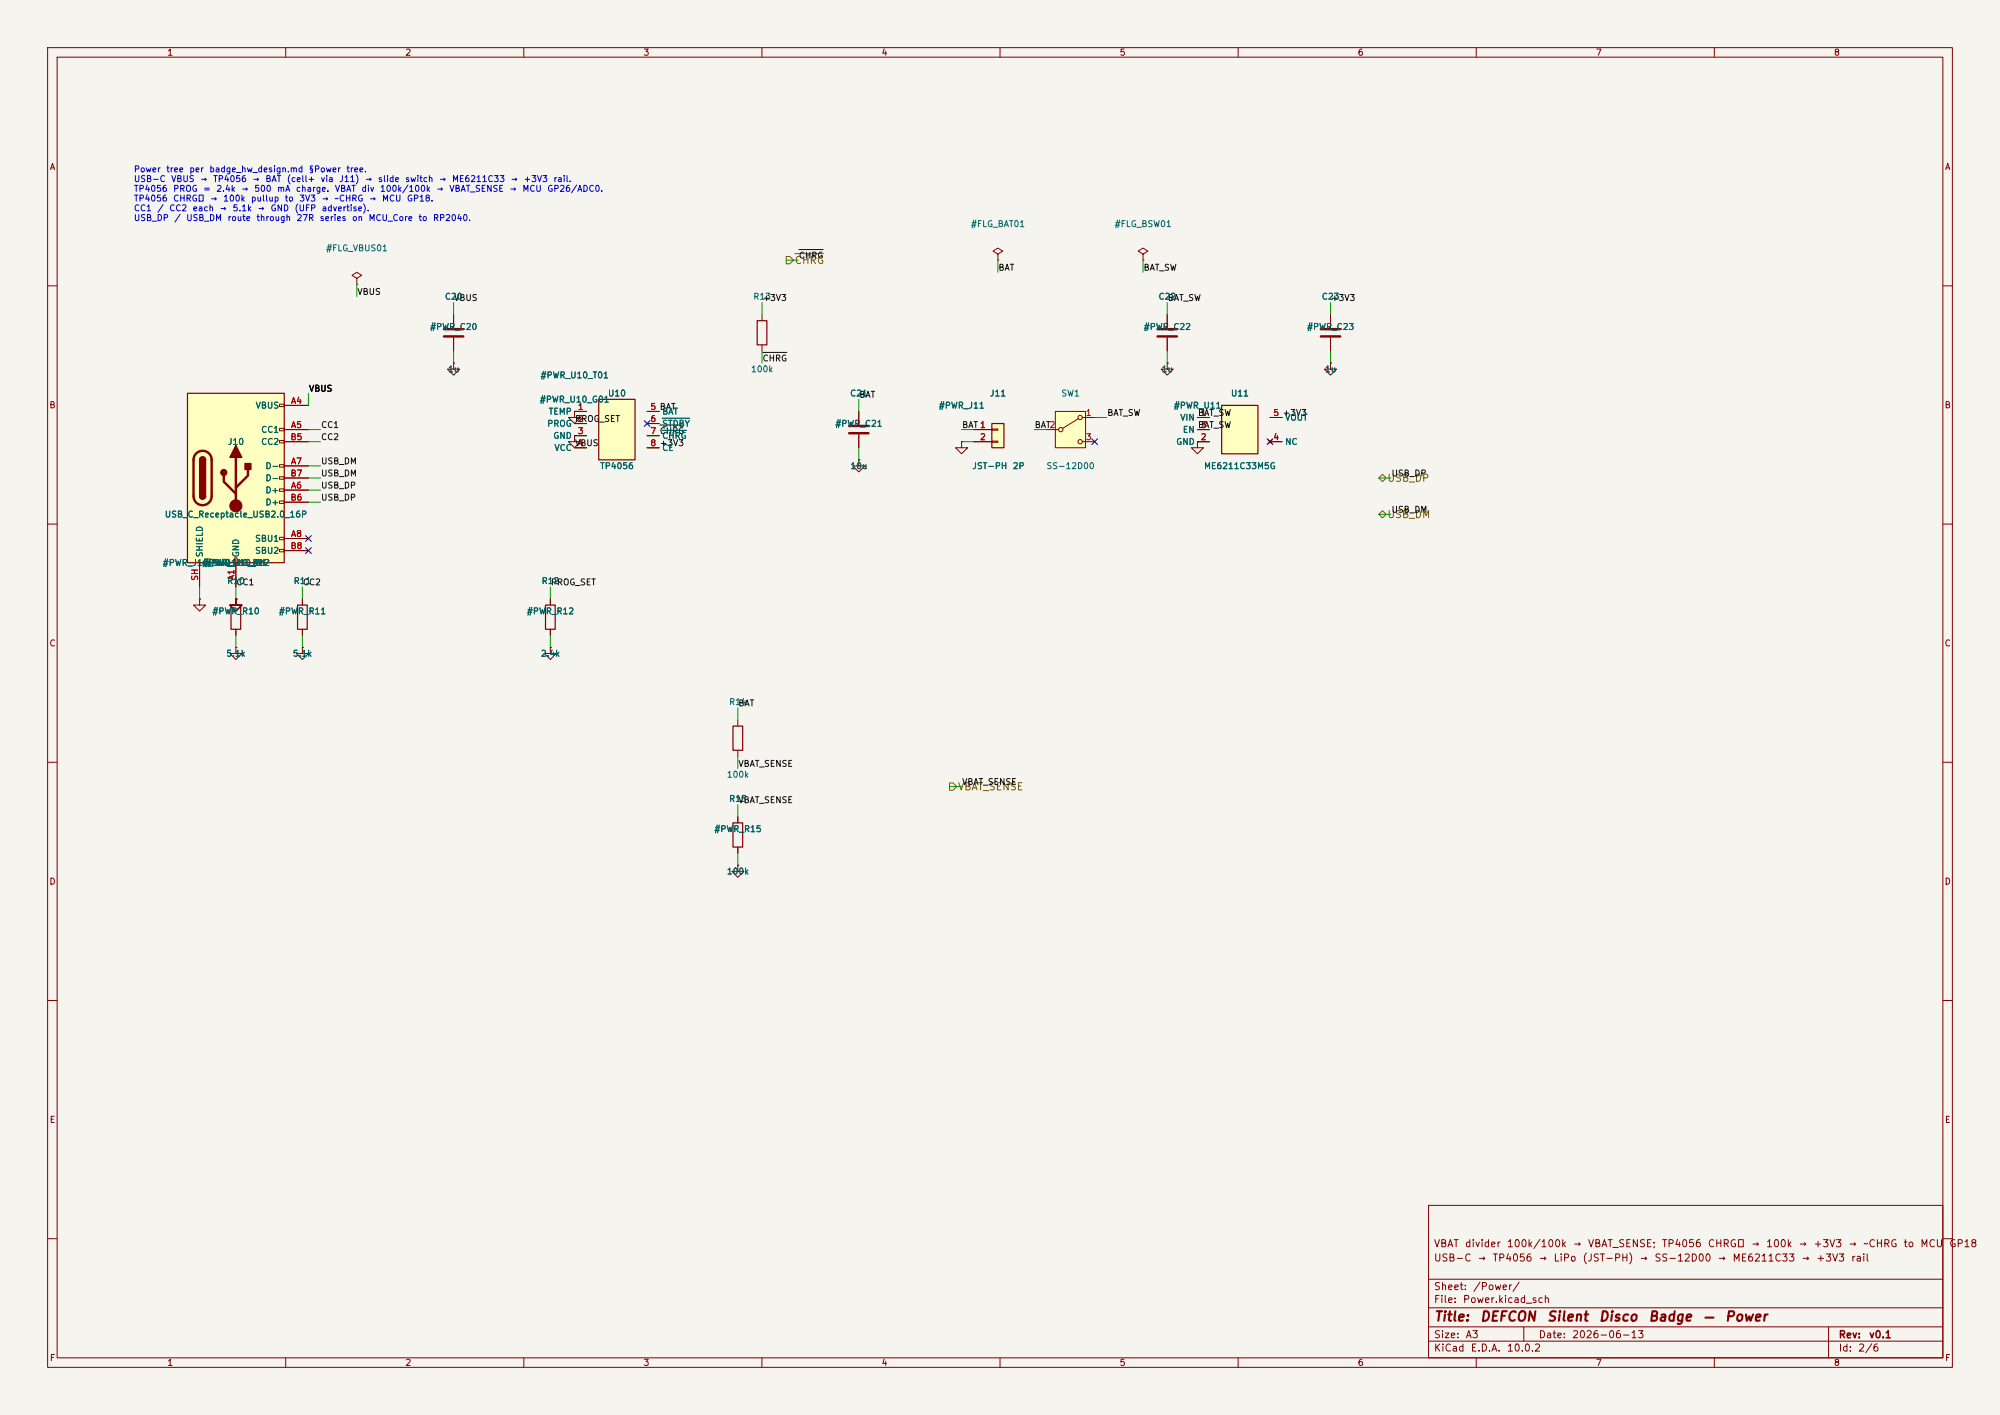
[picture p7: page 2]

USB-C → TP4056 → LiPo (JST-PH) → SS-12D00 → ME6211C33 → +3V3 rail

Sheet: /Power/
File: Power.kicad_sch
Title: DEFCON Silent Disco Badge — Power

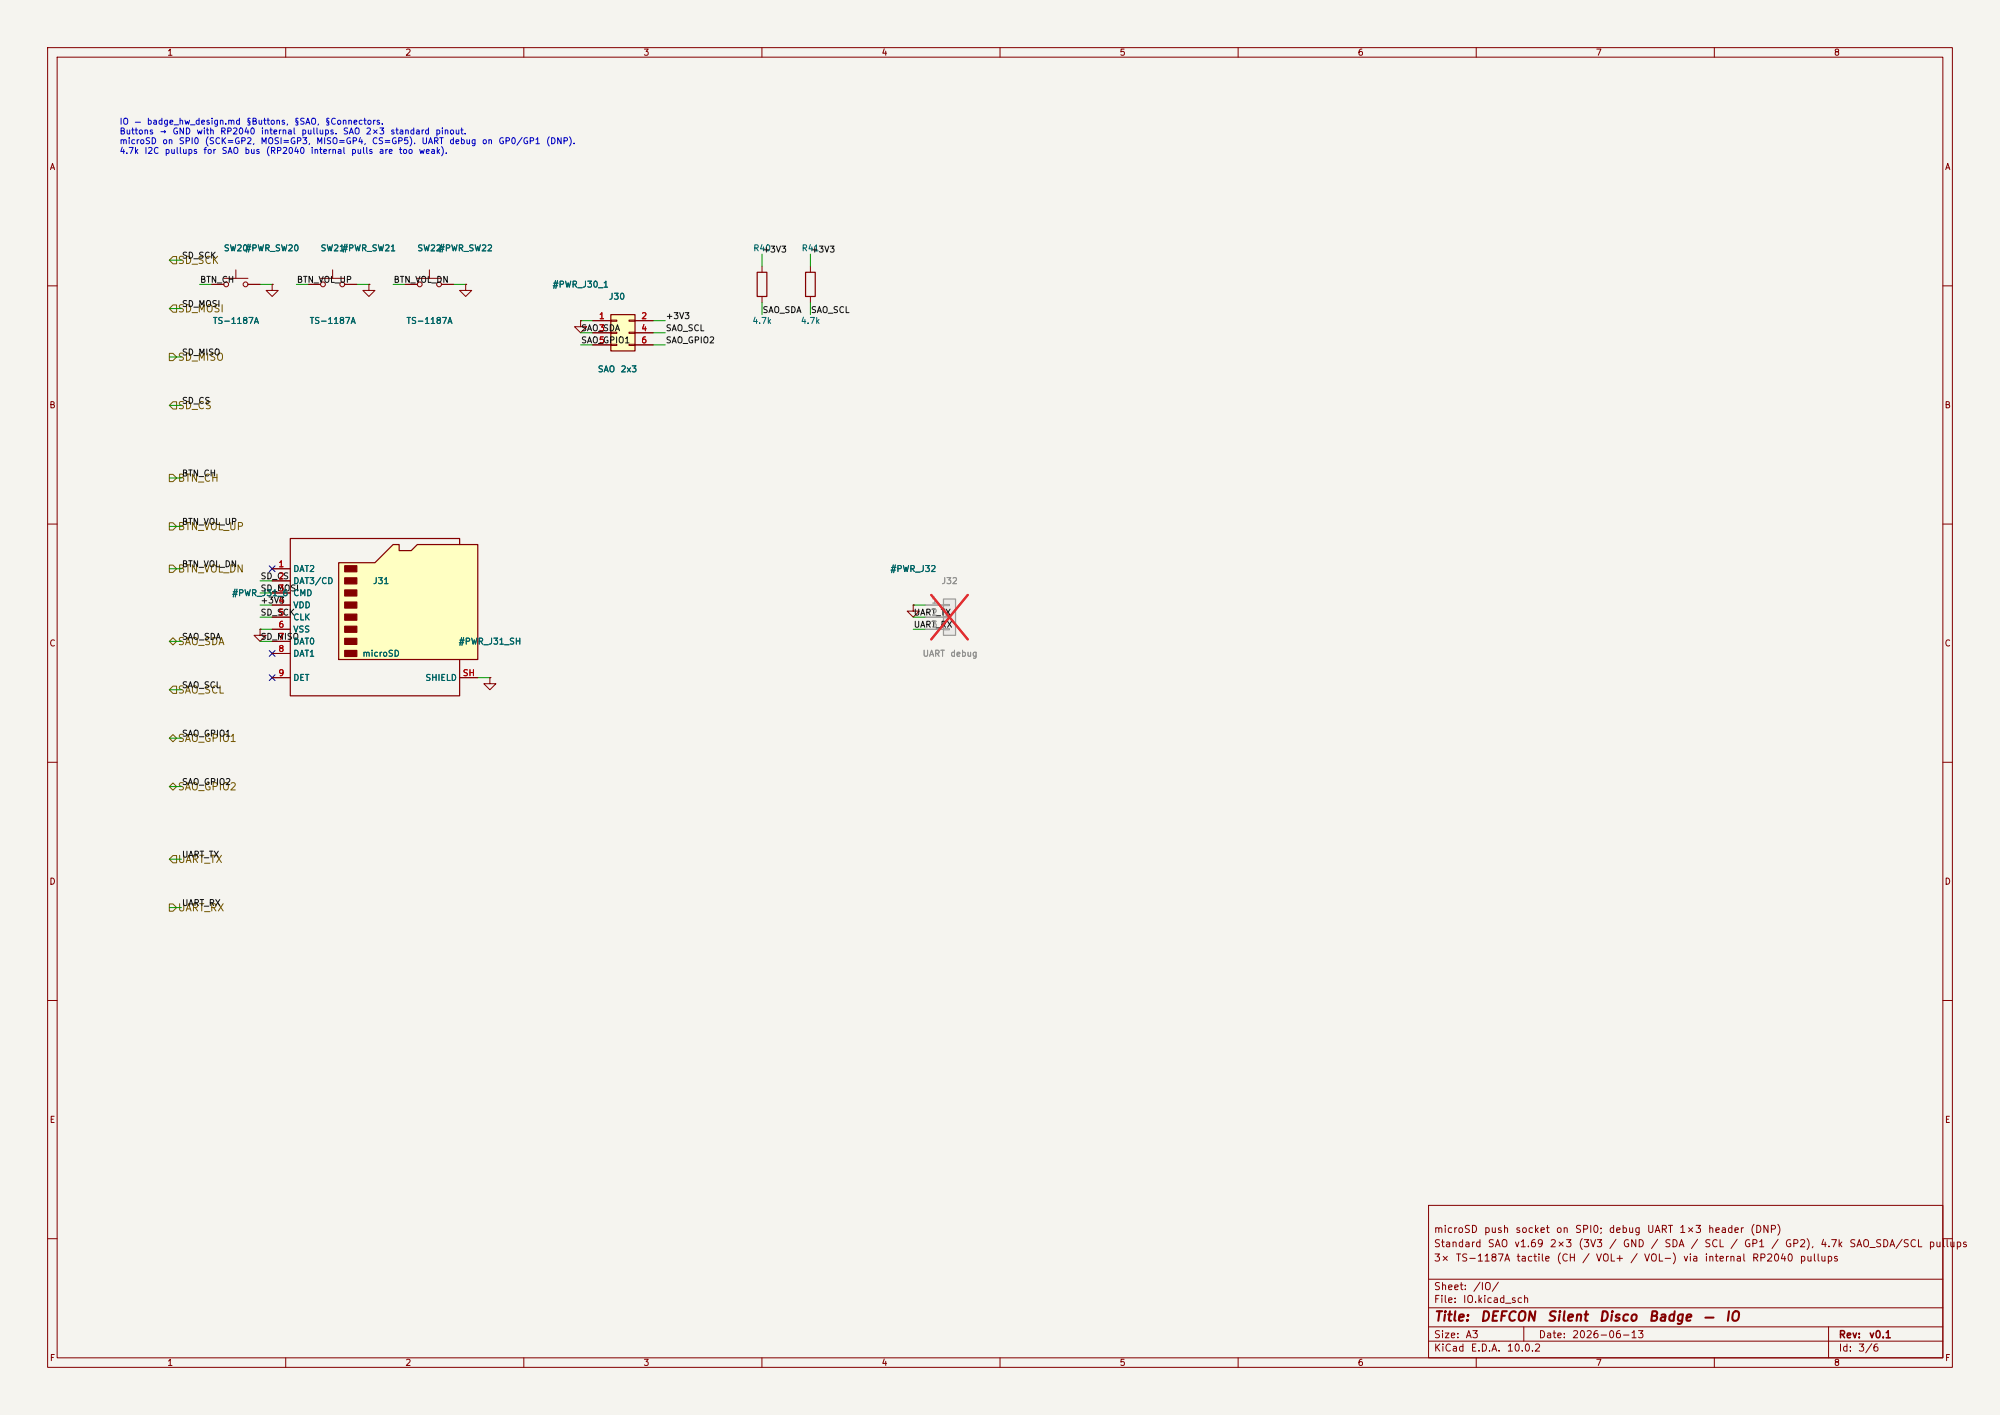
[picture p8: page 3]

IO — badge_hw_design.md §Buttons, §SAO, §Connectors. Buttons → GND with RP2040 internal pullups. SAO 2×3 standard pinout. microSD on SPI0 (SCK=GP2, MOSI=GP3, MISO=GP4, CS=GP5). UART debug on GP0/GP1 (DNP). 4.7k I2C pullups for SAO bus (RP2040 internal pulls are too weak).
SD_MOSI BTN_CH
TS-1187A #PWR_J31_6

microSD push socket on SPI0; debug UART 1×3 header (DNP)
Standard SAO v1.69 2×3 (3V3 / GND / SDA / SCL / GP1 / GP2), 4.7k SAO_SDA/SCL pullups
3× TS-1187A tactile (CH / VOL+ / VOL−) via internal RP2040 pullups

Sheet: /IO/
File: IO.kicad_sch
Title: DEFCON Silent Disco Badge — IO

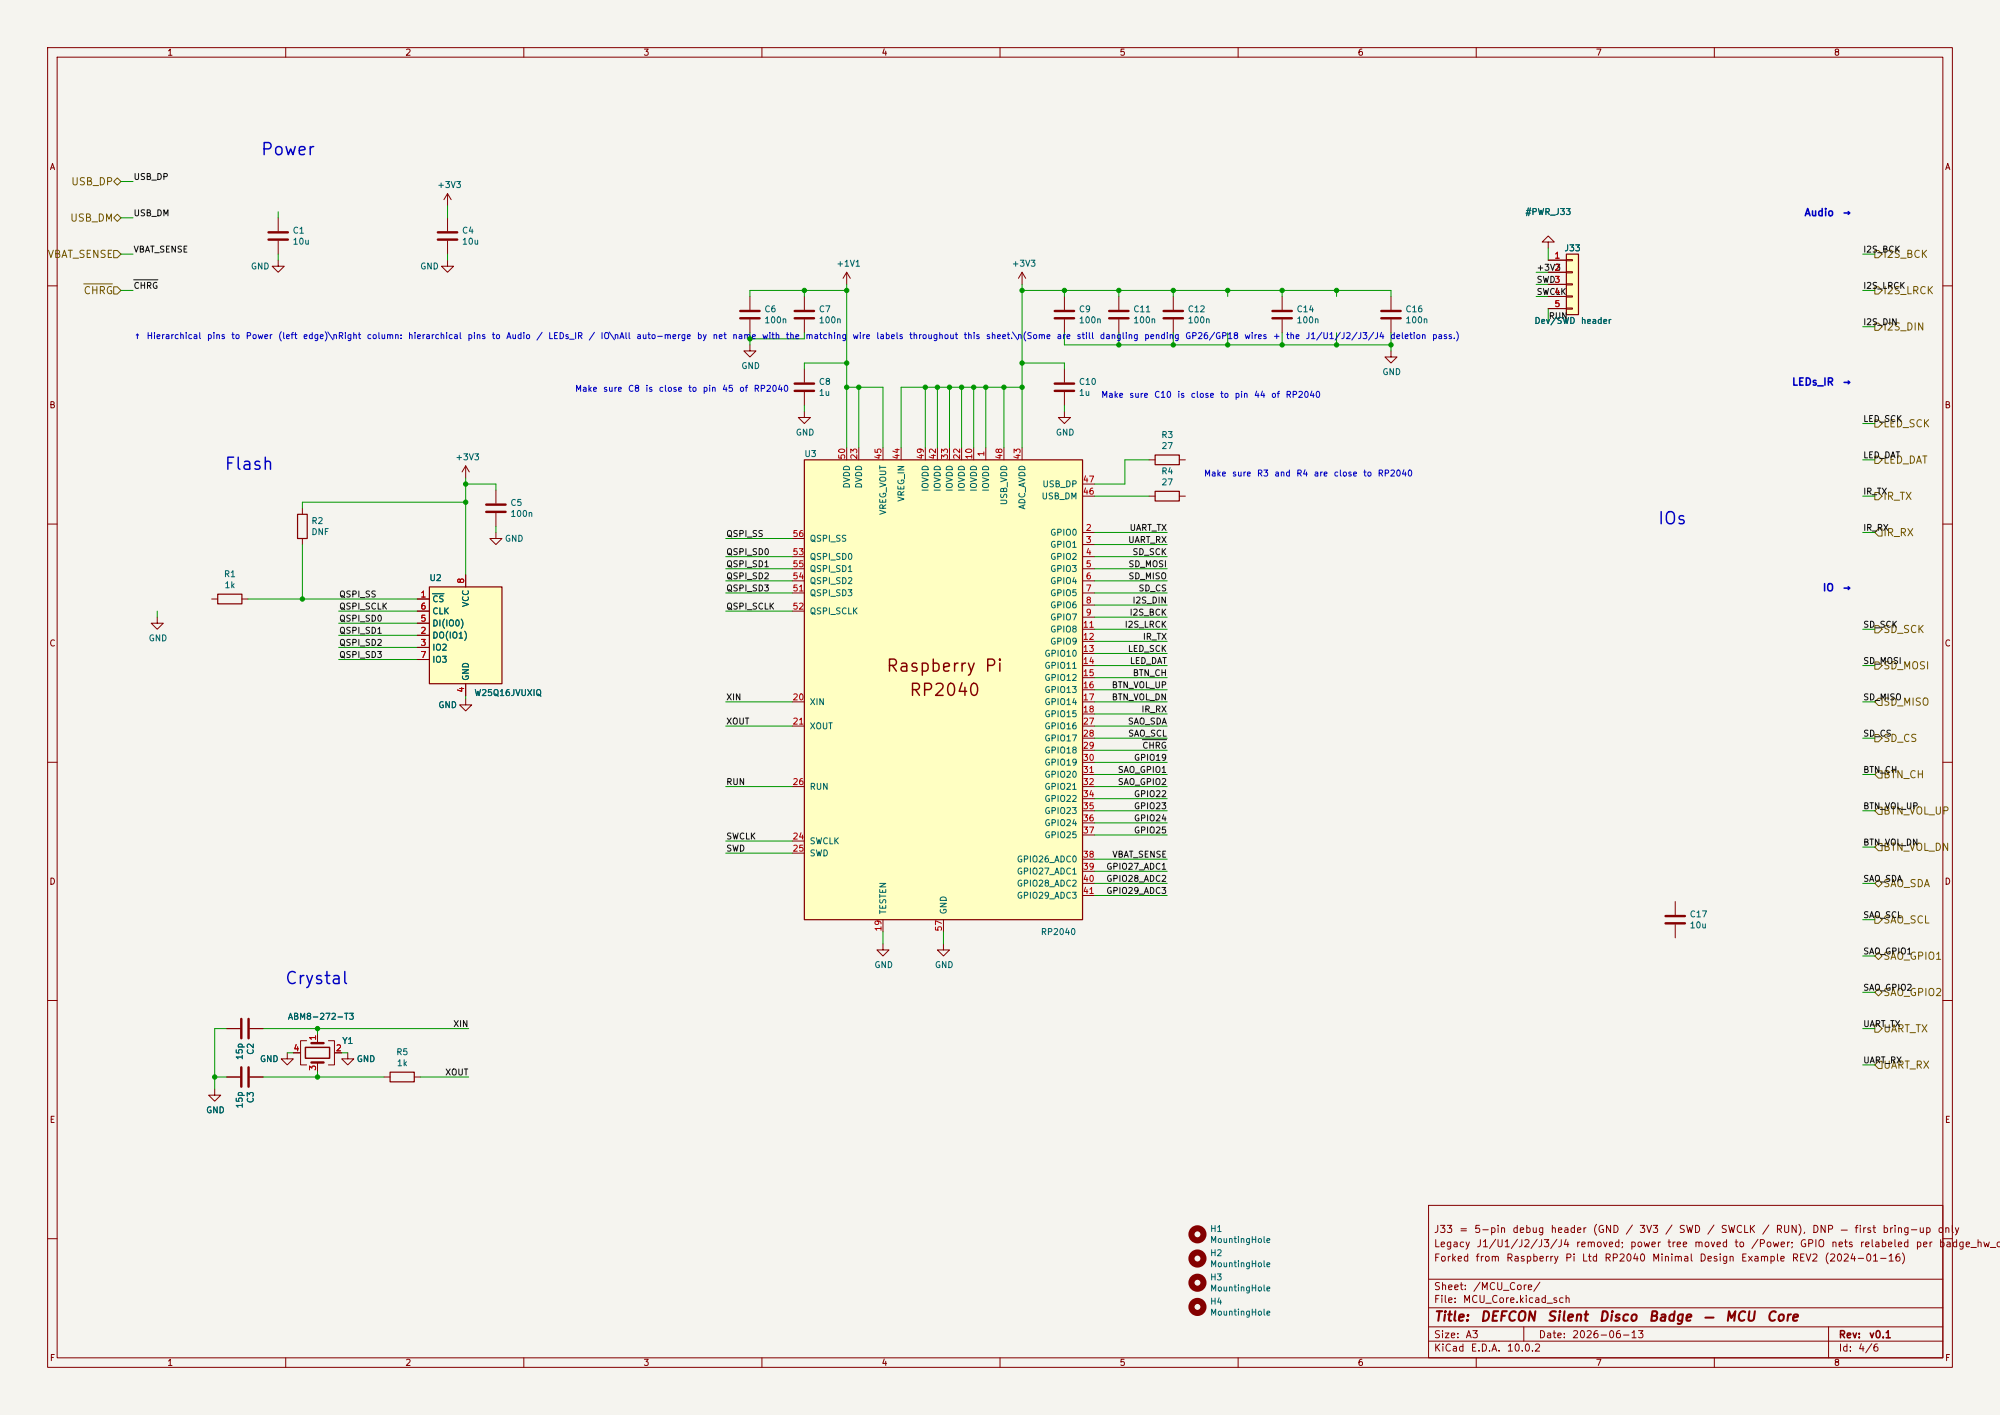
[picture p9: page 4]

Make sure R3 and R4 are close to RP2040 Make sure C8 is close to pin 45 of RP2040

J33 = 5-pin debug header (GND / 3V3 / SWD / SWCLK / RUN), DNP — first bring-up only
Legacy J1/U1/J2/J3/J4 removed; power tree moved to /Power; GPIO nets relabeled per badge_hw_design.md GPIO map
Forked from Raspberry Pi Ltd RP2040 Minimal Design Example REV2 (2024-01-16)

Sheet: /MCU_Core/
File: MCU_Core.kicad_sch
Title: DEFCON Silent Disco Badge — MCU Core

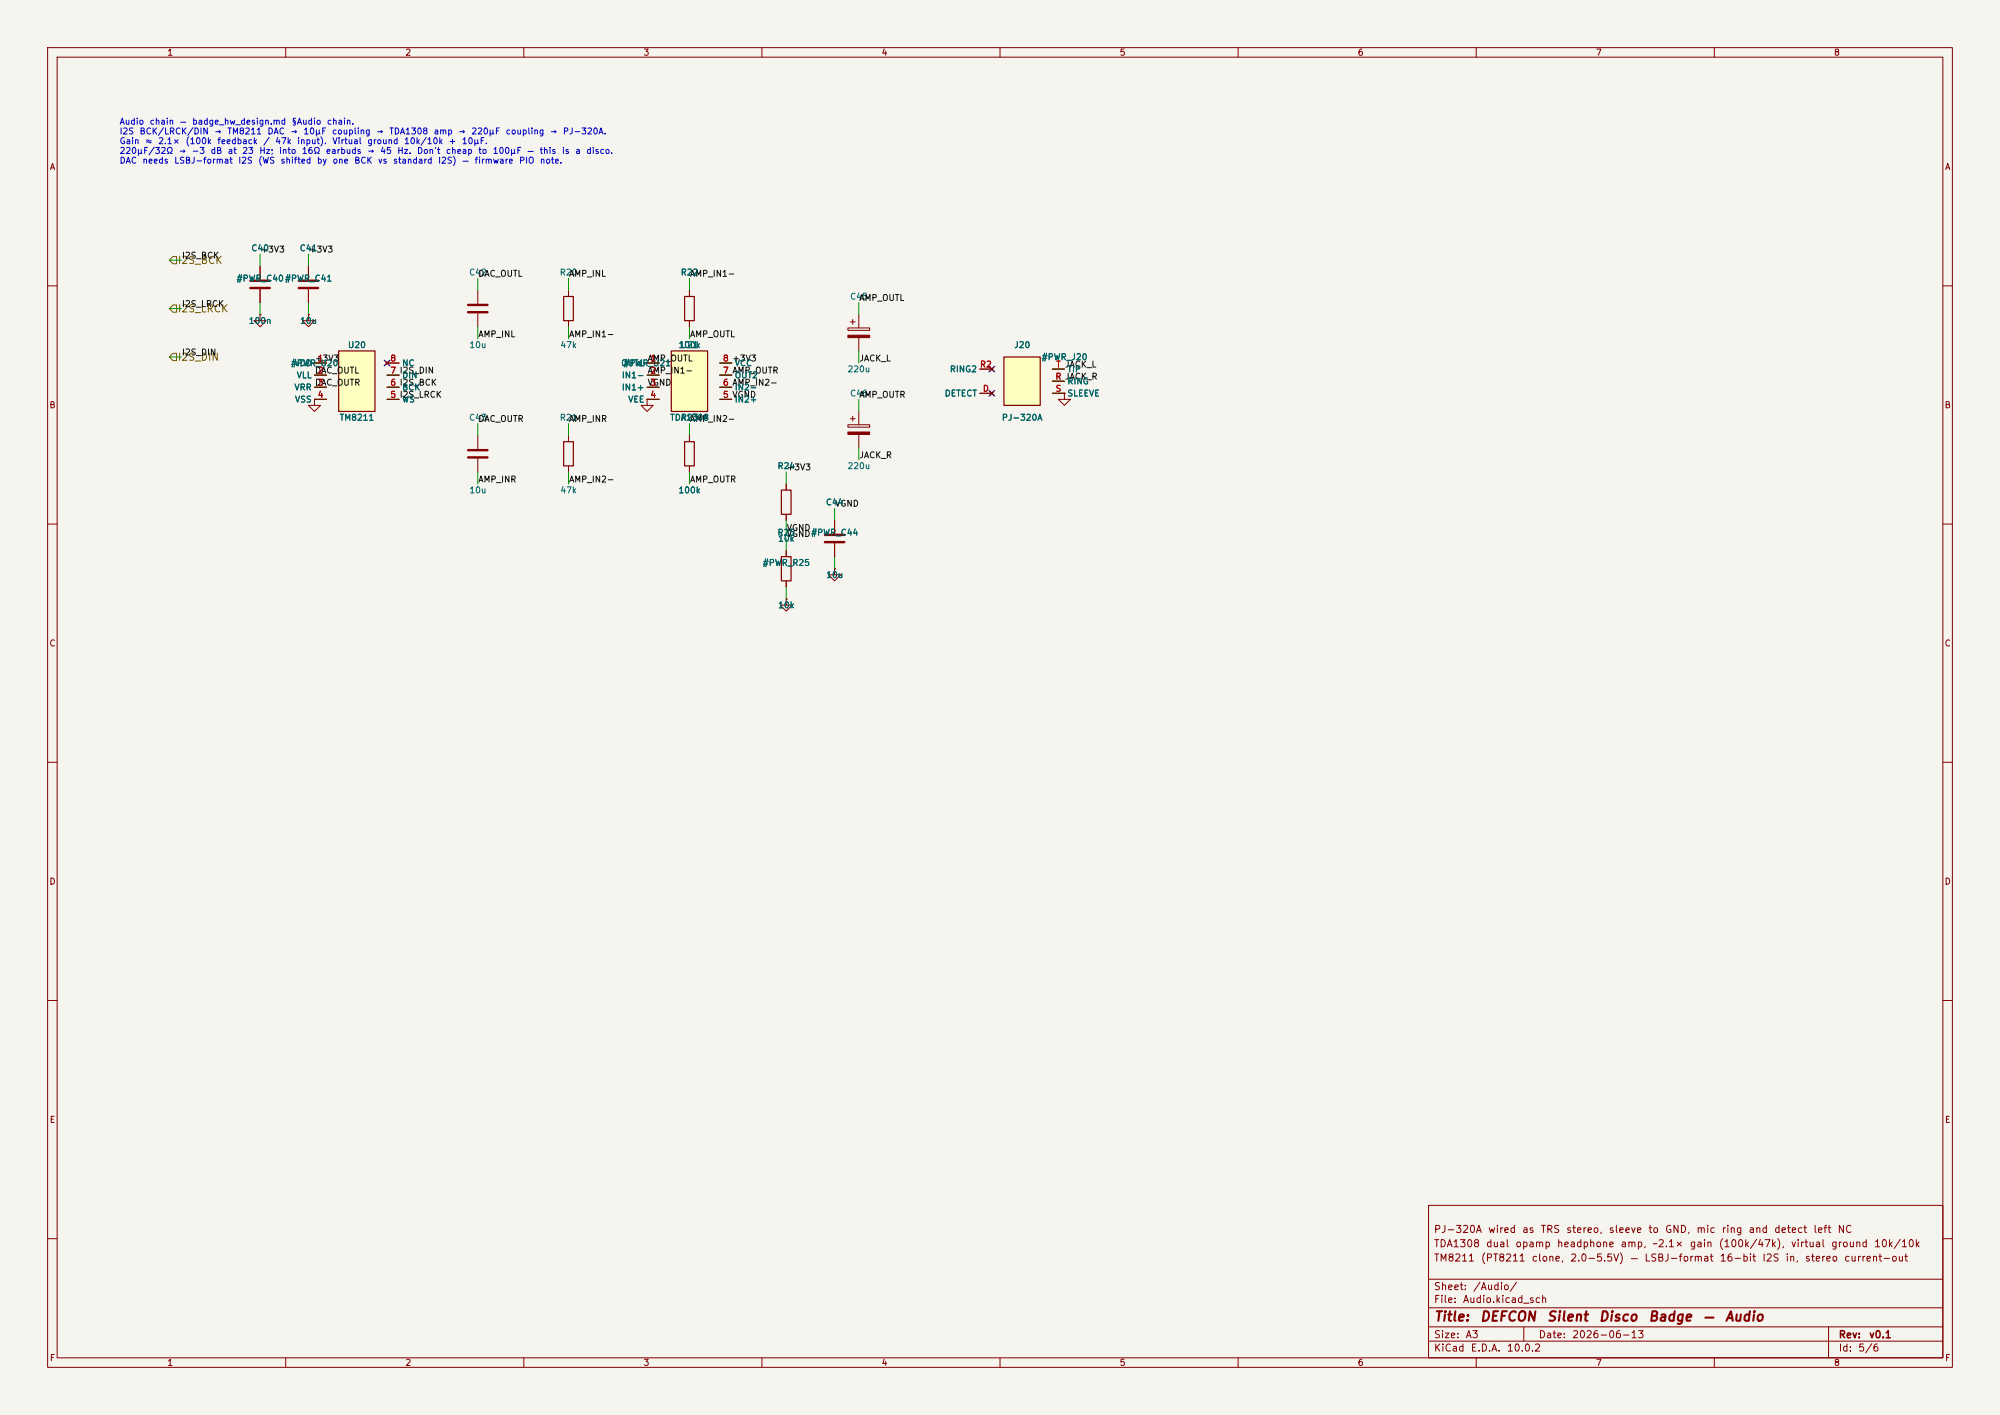
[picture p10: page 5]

Audio chain — badge_hw_design.md §Audio chain.
I2S BCK/LRCK/DIN → TM8211 DAC → 10µF coupling → TDA1308 amp → 220µF coupling → PJ-320A. Gain ≈ 2.1× (100k feedback / 47k input). Virtual ground 10k/10k + 10µF.

PJ-320A wired as TRS stereo, sleeve to GND, mic ring and detect left NC
TDA1308 dual opamp headphone amp, ~2.1× gain (100k/47k), virtual ground 10k/10k
TM8211 (PT8211 clone, 2.0-5.5V) — LSBJ-format 16-bit I2S in, stereo current-out

Sheet: /Audio/
File: Audio.kicad_sch
Title: DEFCON Silent Disco Badge — Audio

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
## Title: DEFCON Silent Disco Badge — LEDs + IR Tap

File: LEDs_IR.kicad_sch

Sheet: /LEDs_IR/

4× SK9822-EC20 chained, SPI1 clock+data, 25% global brightness cap (firmware)

Optical tap link: 940 nm IR LED via S8050 + 68Ω; TSOP4838-class 38 kHz RX

LED + RX placed mirror-symmetric about vertical centerline (face-to-face mate)

#PWR_C63 C60

10n | #PWR_C70 C70

100n

VDD 1 DIN 2 CIN 3 | DOUT 4 COUT 5 GND 6

LED21

SK9822-EC20 #PWR_C60

VDD 1 DIN 2 CIN 3 | DOUT 4 COUT 5 GND 6

LED20

# SK9822-EC20 R30

150 #PWR_LED20 | #PWR_LED21 | C63

10n #PWR_U30

VDD 1 DIN 2 CIN 3 | DOUT 4 COUT 5 GND 6

LED23

SK9822-EC20 #PWR_C61 D20

IR LED 940 nm

#PWR_LED23

#PWR_C62 | C71

10u | OUT GND | 1

2

VS 3 U30

TSOP4838

C61

10n | C62

10n

VDD 1 DIN 2 CIN 3 | DOUT 4 COUT 5 GND 6

LED22
SK9822-EC20 #PWR_LED22

#PWR_C71

IR_TX

IR_RX

LED_SCK

LED_DAT

IR_RX | +3V3 | +3V3

IR_RX

LED_SCK | +3V3 | +3V3 | +3V3 +3V3 +3V3 | +3V3 +3V3 | +3V3

LED_DAT

IR_DRIVE

IR_TX

LED_SCK | +3V3

IR_TX

LED_DAT | +3V3

IR_DRIVE

LEDs + IR tap — badge_hw_design.md §LEDs and §Optical tap. 4× SK9822 chained, capped at ~25% global brightness in firmware. Optical link: 940 nm LED direct-drive from GP9 (IR_TX) via R30=150Ω → ~12 mA pulsed at 38 kHz PIO carrier. Range is intentionally short (~2 cm) — face-to-face tap is the spec. TSOP4838 RX → active-low IR_RX. Place LED + RX mirror-symmetric on front face. On contact, SK9822s pulse in unison with peer — that shared flash IS the sync confirmation. C61

10n #PWR_C61

LED20

SK9822-EC20

VDD 1 DIN 2 CIN 3 | DOUT 4 COUT 5 GND 6 #PWR_C60 C60

10n

LED21

SK9822-EC20

VDD 1 DIN 2 CIN 3 | DOUT 4 COUT 5 GND 6 #PWR_LED20 | #PWR_LED21 | C63

10n #PWR_C63

LED23

SK9822-EC20

VDD 1 DIN 2 CIN 3 | DOUT 4 COUT 5 GND 6 #PWR_LED23

#PWR_C62 C62

10n

LED22

SK9822-EC20

VDD 1 DIN 2 CIN 3 | DOUT 4 COUT 5 GND 6 #PWR_LED22U30
TSOP4838 | OUT GND | 1

2

VS 3 #PWR_U30 R30

150 | #PWR_C70 C70

100n D20

IR LED 940 nm

C71

10u #PWR_C71

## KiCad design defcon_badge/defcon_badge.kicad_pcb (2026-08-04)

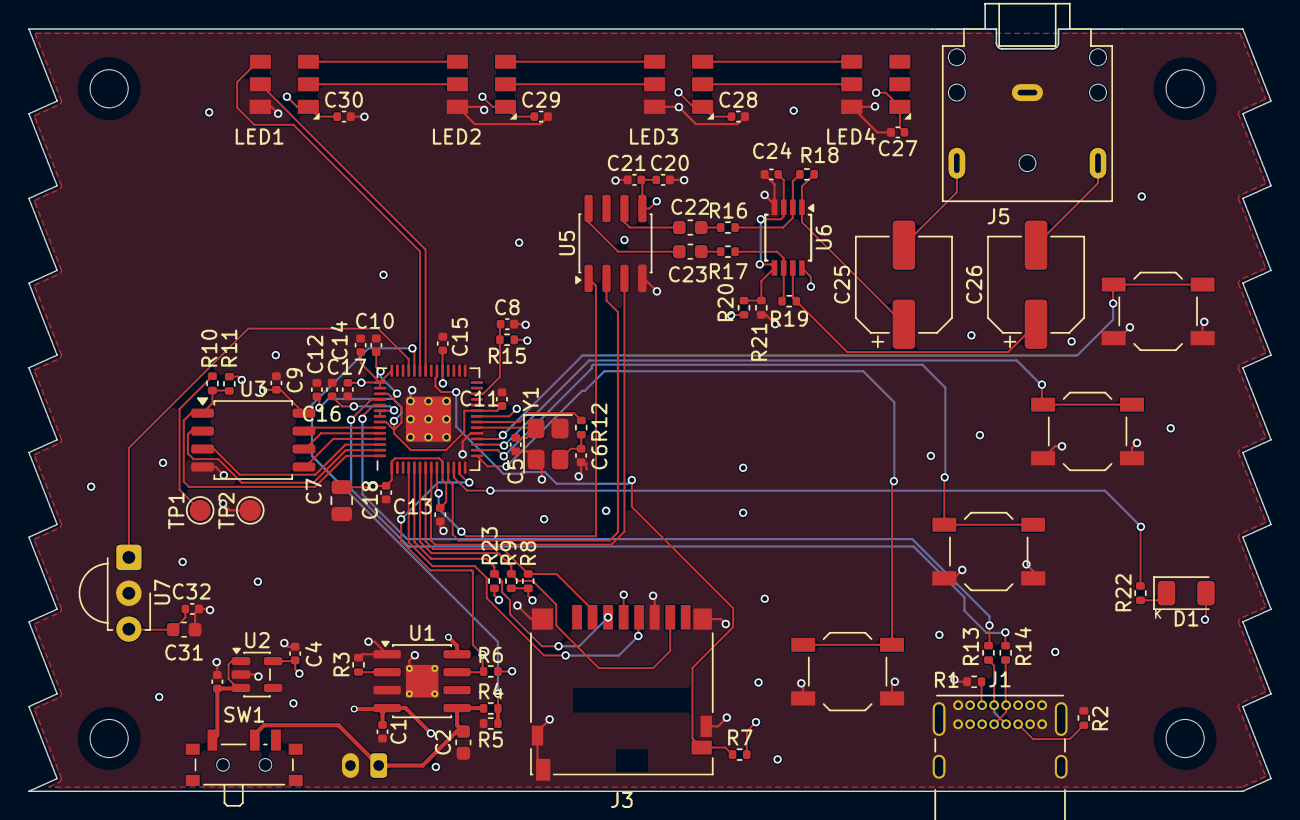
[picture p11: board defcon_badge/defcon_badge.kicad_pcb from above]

Board: 4 copper layers, 88.0 x 54.0 mm, 82 parts (1 on the bottom side), 61 nets.

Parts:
C1, C3, C4, C12, C14: 1u; C_0402_1005Metric
C2, C22, C23, C31: 10u; C_0603_1608Metric
C5, C6: 15p; C_0402_1005Metric
C7: 1u; C_0805_2012Metric
C8: 100nF; C_0402_1005Metric
C9, C10, C11, C13, C15, C16, C17, C18, C20, C30: 100n; C_0402_1005Metric
C21, C24: 10u; C_0402_1005Metric
C25, C26: 220u; CP_Elec_6.3x5.4
C27, C28, C29, C32: 10n; C_0402_1005Metric
CHANNEL1: TS-1187A; SW_SPST_TL3342
D1: IR LED 940 nm; LED_IR_1206_3216Metric
H1, H2, H3, H4: MountingHole; MountingHole_2.7mm_M2.5
J1: USB_C_Receptacle_USB2.0_16P; USB_C_Receptacle_GCT_USB4085
J2: JST-PH 2P; JST_PH_S2B-PH-K_1x02_P2.00mm_Horizontal
J3: microSD; microSD_HC_Hirose_DM3D-SF
J5: SJ1-3523N; Jack_3.5mm_CUI_SJ1-3523N_Horizontal
LED1, LED2, LED3, LED4: SK9822; LED_SK9822_5050
R1, R2: 5.1k; R_0402_1005Metric
R3: 2.4k; R_0402_1005Metric
R4, R5, R6, R18, R19: 100k; R_0402_1005Metric
R7, R8, R9, R15, R20, R21, R23: 10k; R_0402_1005Metric
R10, R12: 1k; R_0402_1005Metric
R11: DNF; R_0402_1005Metric
R13, R14: 27; R_0402_1005Metric
R16, R17: 47k; R_0402_1005Metric
R22: 150; R_0402_1005Metric
SW1: SS-12D00; SW_SPDT_PCM12
SYNC1: TS-1187A; SW_SPST_TL3342
TP1: BOOTSEL; TestPoint_Pad_D1.5mm
TP2: GND; TestPoint_Pad_D1.5mm
U1: TP4056; HSOP-8-1EP_3.9x4.9mm_P1.27mm_EP2.3x2.3mm_ThermalVias
U2: ME6211C33M5G; SOT-23-5
U3: WM2606220057; SOIC-8_5.3x5.3mm_P1.27mm
U4: RP2040; RP2040-QFN-56
U5: TM8211; SOIC-8_3.9x4.9mm_P1.27mm
U6: TDA1308; TSSOP-8_3x3mm_P0.65mm
U7: TSOP4838; Vishay_MINICAST-3Pin
VOL+1: TS-1187A; SW_SPST_TL3342
VOL-1: TS-1187A; SW_SPST_TL3342
Y1: ABM8-272-T3; Crystal_SMD_3225-4Pin_3.2x2.5mm

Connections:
+1V1: C10.1, C11.1, C12.1, U4.23 (DVDD), U4.45 (VREG_VOUT), U4.50 (DVDD)
+3.3V: R8.1, R9.1, R23.1
+3V3: C4.1, C7.1, C9.1, C13.1, C14.1, C15.1, C16.1, C17.1, C18.1, C20.1, C21.1, C27.1, C28.1, C29.1, C30.1, C31.1, C32.1, D1.1 (K), J3.4 (VDD), LED1.4 (VDD), LED2.4 (VDD), LED3.4 (VDD), LED4.4 (VDD), R6.1, R7.2, R11.1, R15.1, R20.1, U2.5 (VOUT), U3.8 (VCC), U4.1 (IOVDD), U4.10 (IOVDD), U4.22 (IOVDD), U4.33 (IOVDD), U4.42 (IOVDD), U4.43 (ADC_AVDD), U4.44 (VREG_IN), U4.48 (USB_VDD), U4.49 (IOVDD), U5.5 (VDD), U6.8 (VCC), U7.3 (VS)
/Audio/AMP_IN1-: R16.2, R18.1, U6.2 (IN1-)
/Audio/AMP_IN2-: R17.2, R19.1, U6.6 (IN2-)
/Audio/AMP_INL: C22.2, R16.1
/Audio/AMP_INR: C23.2, R17.1
/Audio/AMP_OUTL: C25.1, R18.2, U6.1 (OUT1)
/Audio/AMP_OUTR: C26.1, R19.2, U6.7 (OUT2)
/Audio/DAC_OUTL: C22.1, U5.6 (LCH)
/Audio/DAC_OUTR: C23.1, U5.8 (RCH)
/Audio/I2S_BCK: U4.9 (GPIO7), U5.1 (BCK)
/Audio/I2S_DIN: U4.8 (GPIO6), U5.3 (DIN)
/Audio/I2S_LRCK: U4.11 (GPIO8), U5.2 (WS)
/Audio/JACK_L: C25.2, J5.T (TIP)
/Audio/JACK_R: C26.2, J5.R (RING)
/Audio/VGND: C24.1, R20.2, R21.1, U6.3 (IN1+), U6.5 (IN2+)
/IO/BTN_CH: CHANNEL1.1, U4.18 (GPIO15)
/IO/BTN_SYNC: SYNC1.1, U4.15 (GPIO12)
/IO/BTN_VOL_DN: U4.16 (GPIO13), VOL-1.1
/IO/BTN_VOL_UP: U4.17 (GPIO14), VOL+1.1
/IO/SD_CS: J3.2 (DAT3/CD), R8.2, U4.7 (GPIO5)
/IO/SD_MISO: J3.7 (DAT0), R9.2, U4.6 (GPIO4)
/IO/SD_MOSI: J3.3 (CMD), R23.2, U4.5 (GPIO3)
/IO/SD_SCK: J3.5 (CLK), U4.4 (GPIO2)
/LEDs_IR/IR_DRIVE: D1.2 (A), R22.1
/LEDs_IR/IR_RX: U4.39 (GPIO27_ADC1), U7.1 (OUT)
/LEDs_IR/IR_TX: R22.2, U4.12 (GPIO9)
/LEDs_IR/LED_DAT: LED1.1 (DIN), U4.37 (GPIO25)
/LEDs_IR/LED_SCK: LED1.2 (CIN), U4.36 (GPIO24)
/MCU_Core/BOOTSEL: R10.2, TP1.1 (1_1)
/MCU_Core/QSPI_SCLK: U3.6 (CLK), U4.52 (QSPI_SCLK)
/MCU_Core/QSPI_SD0: U3.5 (DI(IO0)), U4.53 (QSPI_SD0)
/MCU_Core/QSPI_SD1: U3.2 (DO(IO1)), U4.55 (QSPI_SD1)
/MCU_Core/QSPI_SD2: U3.3 (IO2), U4.54 (QSPI_SD2)
/MCU_Core/QSPI_SD3: U3.7 (IO3), U4.51 (QSPI_SD3)
/MCU_Core/QSPI_SS: R10.1, R11.2, U3.1 (~CS), U4.56 (QSPI_SS)
/MCU_Core/RUN: C8.1, R15.2, U4.26 (RUN)
/MCU_Core/USB_DM: J1.A7 (D-), J1.B7 (D-), R14.1
/MCU_Core/USB_DP: J1.A6 (D+), J1.B6 (D+), R13.1
/MCU_Core/VBAT_SENSE: R4.2, R5.1, U4.38 (GPIO26_ADC0)
/MCU_Core/XIN: C5.1, U4.20 (XIN), Y1.1
/MCU_Core/XOUT: R12.1, U4.21 (XOUT)
/MCU_Core/~CHRG: R6.2, U1.7 (~CHRG), U4.13 (GPIO10)
/Power/BAT: C2.1, J2.2, R4.1, SW1.2 (B), U1.5 (BAT)
/Power/BAT_SW: C3.1, SW1.1 (A), U2.1 (VIN), U2.3 (EN)
/Power/CC1: J1.A5 (CC1), R1.1
/Power/CC2: J1.B5 (CC2), R2.1
/Power/PROG_SET: R3.1, U1.2 (PROG)
/Power/VBUS: C1.1, J1.A4 (VBUS), J1.A9 (VBUS), J1.B4 (VBUS), J1.B9 (VBUS), U1.4 (VCC), U1.8 (CE)
GND: C1.2, C2.2, C3.2, C4.2, C5.2, C6.2, C7.2, C8.2, C9.2, C10.2, C11.2, C12.2, C13.2, C14.2, C15.2, C16.2, C17.2, C18.2, C20.2, C21.2, C24.2, C27.2, C28.2, C29.2, C30.2, C31.2, C32.2, CHANNEL1.2, J1.A1 (GND), J1.A12 (GND), J1.B1 (GND), J1.B12 (GND), J1.SH (SHIELD), J2.1, J3.6 (VSS), J3.10 (DET_A), J3.SH (SHIELD), J5.S (SLEEVE), LED1.3 (GND), LED2.3 (GND), LED3.3 (GND), LED4.3 (GND), R1.2, R2.2, R3.2, R5.2, R21.2, SYNC1.2, TP2.1 (1_1), U1.1 (TEMP), U1.3 (GND), U1.9 (EP), U2.2 (GND), U3.4 (GND), U4.19 (TESTEN), U4.57 (GND), U5.4 (GND), U6.4 (VEE), U7.2 (GND), VOL+1.2, VOL-1.2, Y1.2, Y1.4
unnamed: C6.1, R12.2, Y1.3
unnamed: LED1.5 (COUT), LED2.2 (CIN)
unnamed: LED1.6 (DOUT), LED2.1 (DIN)
unnamed: LED2.5 (COUT), LED3.2 (CIN)
unnamed: LED2.6 (DOUT), LED3.1 (DIN)
unnamed: LED3.5 (COUT), LED4.2 (CIN)
unnamed: LED3.6 (DOUT), LED4.1 (DIN)
unnamed: R14.2, U4.46 (USB_DM)
unnamed: R13.2, U4.47 (USB_DP)
SD_CD: J3.9 (DET_B), R7.1, U4.34 (GPIO22)

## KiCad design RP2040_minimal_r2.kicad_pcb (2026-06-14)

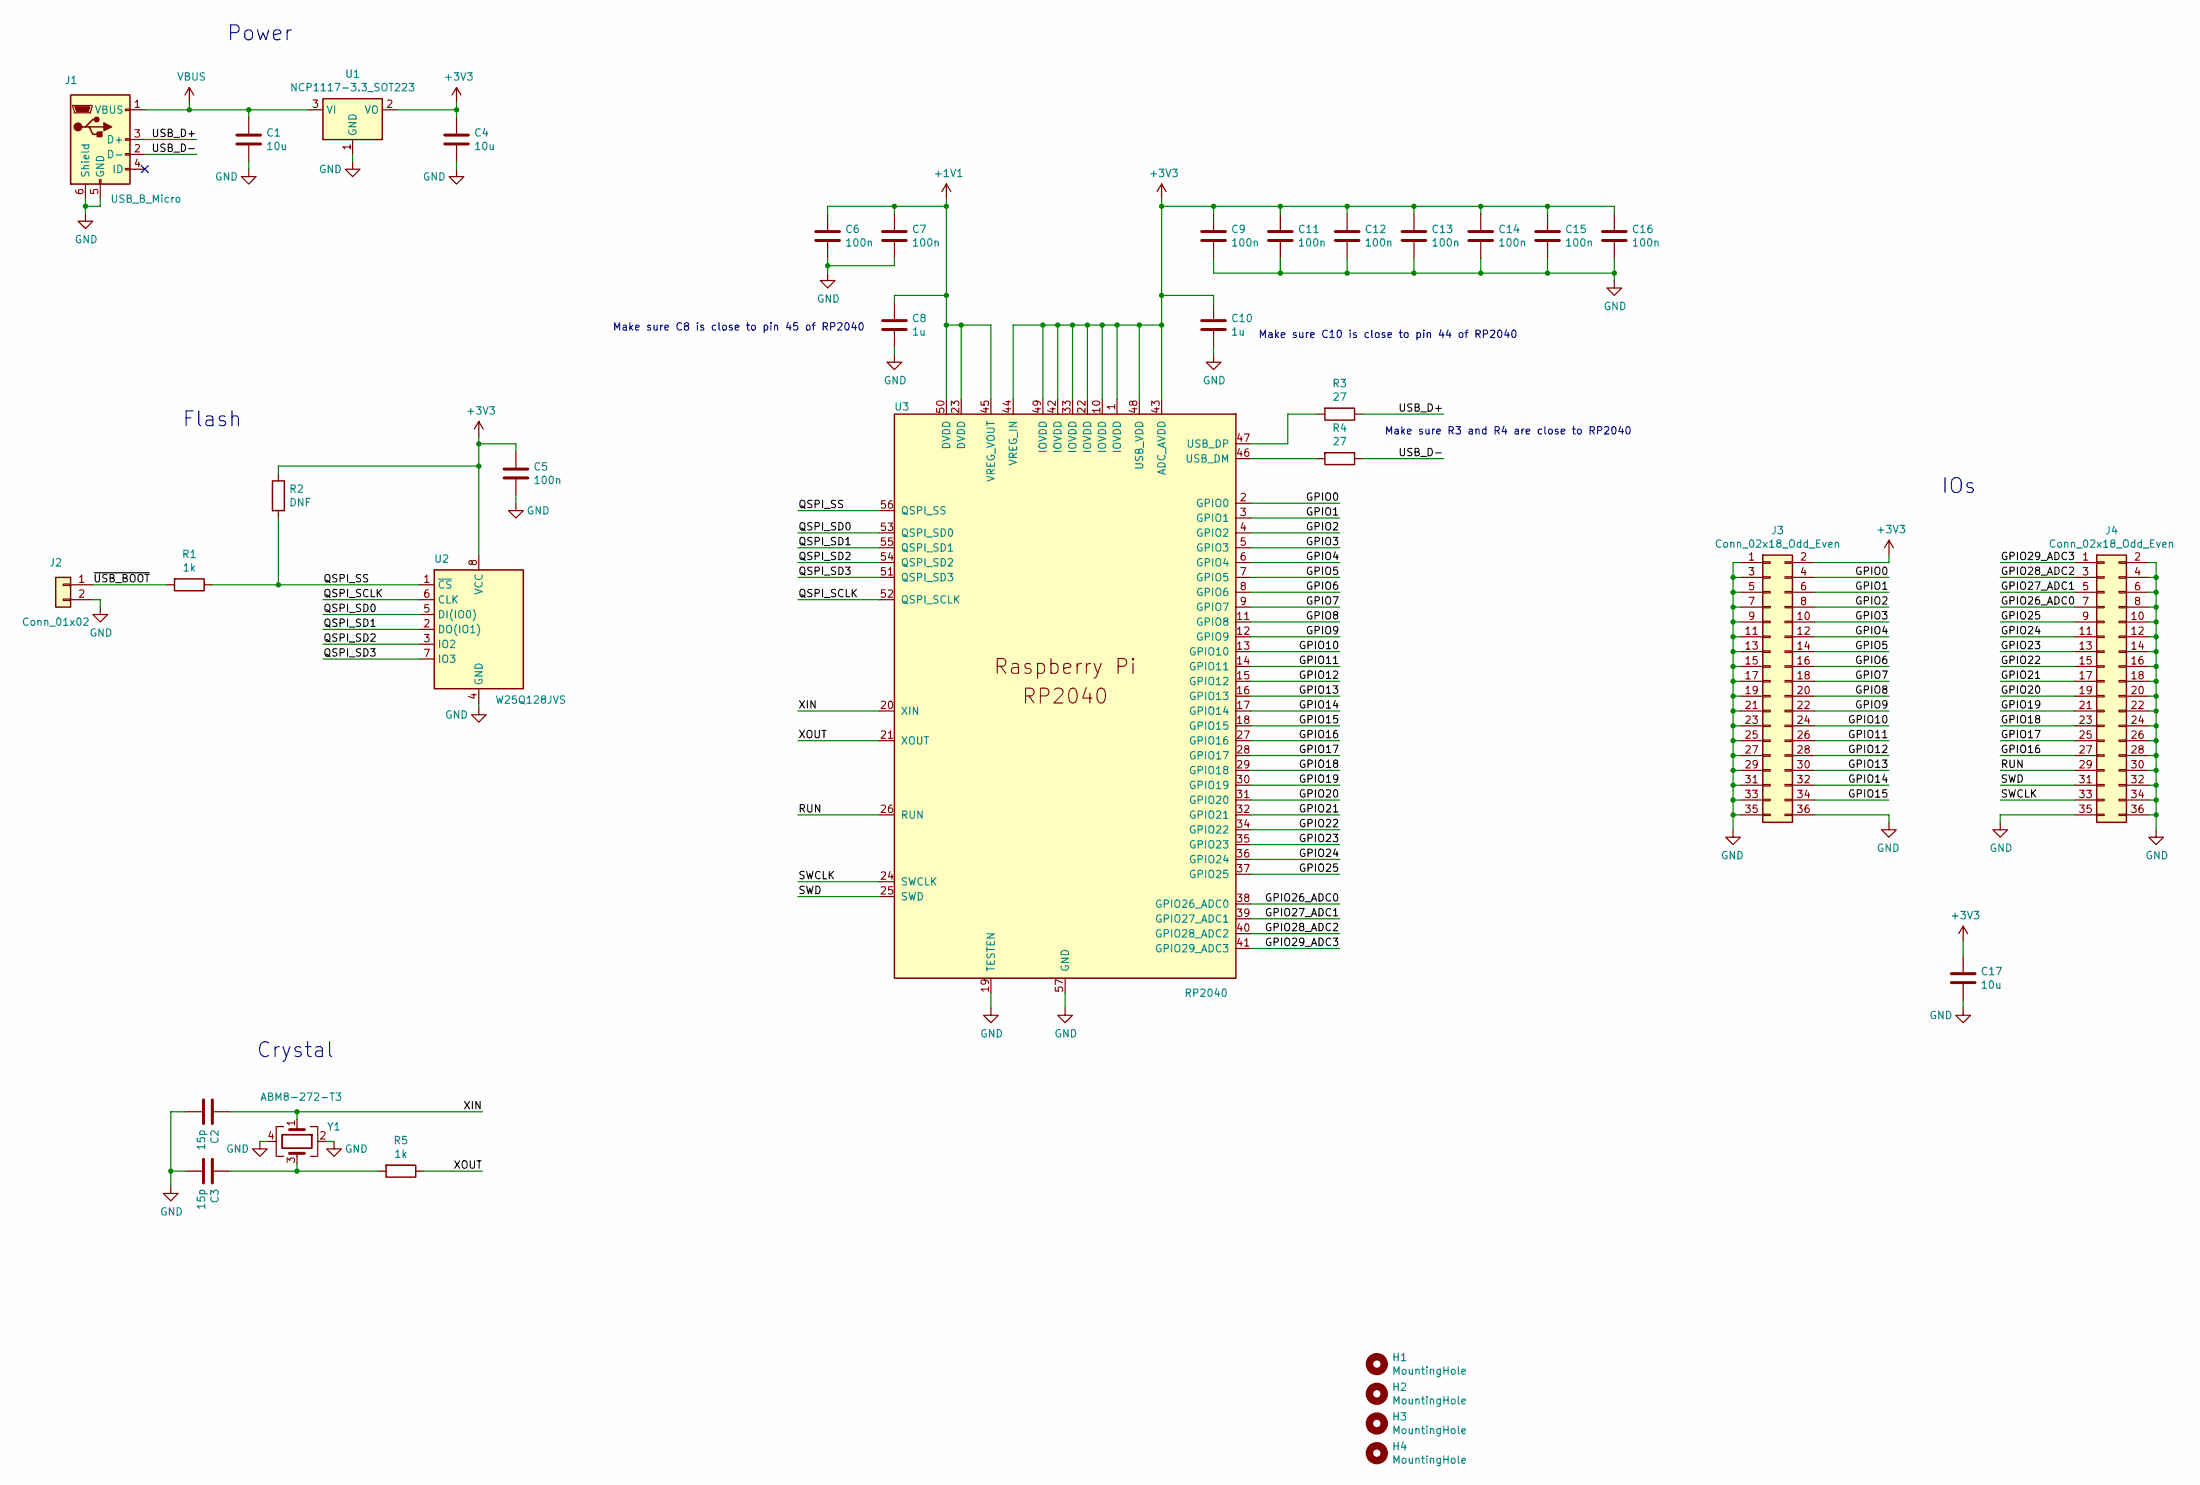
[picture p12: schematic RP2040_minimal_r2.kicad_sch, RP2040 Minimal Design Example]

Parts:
C1, C4, C17: 10u; C_0805_2012Metric
C2, C3: 15p; C_0402_1005Metric
C5, C6, C7, C9, C11, C12, C13, C14, C15, C16: 100n; C_0402_1005Metric
C8, C10: 1u; C_0402_1005Metric
H1, H2, H3, H4: MountingHole; MountingHole_2.7mm_M2.5
J1: USB_B_Micro; USB_Micro-B_Amphenol_10103594-0001LF_Horizontal_modified
J2: Conn_01x02; PinHeader_1x02_P2.54mm_Vertical
J3, J4: Conn_02x18_Odd_Even; PinHeader_2x18_P2.54mm_Vertical
R1, R5: 1k; R_0402_1005Metric
R2: DNF; R_0402_1005Metric
R3, R4: 27; R_0402_1005Metric
U1: NCP1117-3.3_SOT223; SOT-223-3_TabPin2
U2: W25Q128JVS; SOIC-8_5.23x5.23mm_P1.27mm
U3: RP2040; RP2040-QFN-56
Y1: ABM8-272-T3; Crystal_SMD_3225-4Pin_3.2x2.5mm

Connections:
+1V1: C6.1, C7.1, C8.1, U3.23 (DVDD), U3.45 (VREG_VOUT), U3.50 (DVDD)
+3V3: C4.1, C5.1, C9.1, C10.1, C11.1, C12.1, C13.1, C14.1, C15.1, C16.1, C17.1, J3.2, R2.1, U1.2 (VO), U2.8 (VCC), U3.1 (IOVDD), U3.10 (IOVDD), U3.22 (IOVDD), U3.33 (IOVDD), U3.42 (IOVDD), U3.43 (ADC_AVDD), U3.44 (VREG_IN), U3.48 (USB_VDD), U3.49 (IOVDD)
/GPIO0: J3.4, U3.2 (GPIO0)
/GPIO1: J3.6, U3.3 (GPIO1)
/GPIO2: J3.8, U3.4 (GPIO2)
/GPIO3: J3.10, U3.5 (GPIO3)
/GPIO4: J3.12, U3.6 (GPIO4)
/GPIO5: J3.14, U3.7 (GPIO5)
/GPIO6: J3.16, U3.8 (GPIO6)
/GPIO7: J3.18, U3.9 (GPIO7)
/GPIO8: J3.20, U3.11 (GPIO8)
/GPIO9: J3.22, U3.12 (GPIO9)
/GPIO10: J3.24, U3.13 (GPIO10)
/GPIO11: J3.26, U3.14 (GPIO11)
/GPIO12: J3.28, U3.15 (GPIO12)
/GPIO13: J3.30, U3.16 (GPIO13)
/GPIO14: J3.32, U3.17 (GPIO14)
/GPIO15: J3.34, U3.18 (GPIO15)
/GPIO16: J4.27, U3.27 (GPIO16)
/GPIO17: J4.25, U3.28 (GPIO17)
/GPIO18: J4.23, U3.29 (GPIO18)
/GPIO19: J4.21, U3.30 (GPIO19)
/GPIO20: J4.19, U3.31 (GPIO20)
/GPIO21: J4.17, U3.32 (GPIO21)
/GPIO22: J4.15, U3.34 (GPIO22)
/GPIO23: J4.13, U3.35 (GPIO23)
/GPIO24: J4.11, U3.36 (GPIO24)
/GPIO25: J4.9, U3.37 (GPIO25)
/GPIO26_ADC0: J4.7, U3.38 (GPIO26_ADC0)
/GPIO27_ADC1: J4.5, U3.39 (GPIO27_ADC1)
/GPIO28_ADC2: J4.3, U3.40 (GPIO28_ADC2)
/GPIO29_ADC3: J4.1, U3.41 (GPIO29_ADC3)
/QSPI_SCLK: U2.6 (CLK), U3.52 (QSPI_SCLK)
/QSPI_SD0: U2.5 (DI(IO0)), U3.53 (QSPI_SD0)
/QSPI_SD1: U2.2 (DO(IO1)), U3.55 (QSPI_SD1)
/QSPI_SD2: U2.3 (IO2), U3.54 (QSPI_SD2)
/QSPI_SD3: U2.7 (IO3), U3.51 (QSPI_SD3)
/QSPI_SS: R1.1, R2.2, U2.1 (~CS), U3.56 (QSPI_SS)
/RUN: J4.29, U3.26 (RUN)
/SWCLK: J4.33, U3.24 (SWCLK)
/SWD: J4.31, U3.25 (SWD)
/USB_D+: J1.3 (D+), R3.1
/USB_D-: J1.2 (D-), R4.1
/XIN: C2.1, U3.20 (XIN), Y1.1
/XOUT: R5.1, U3.21 (XOUT)
/~USB_BOOT: J2.1, R1.2
GND: C1.2, C2.2, C3.2, C4.2, C5.2, C6.2, C7.2, C8.2, C9.2, C10.2, C11.2, C12.2, C13.2, C14.2, C15.2, C16.2, C17.2, J1.5 (GND), J1.6 (Shield), J2.2, J3.1, J3.3, J3.5, J3.7, J3.9, J3.11, J3.13, J3.15, J3.17, J3.19, J3.21, J3.23, J3.25, J3.27, J3.29, J3.31, J3.33, J3.35, J3.36, J4.2, J4.4, J4.6, J4.8, J4.10, J4.12, J4.14, J4.16, J4.18, J4.20, J4.22, J4.24, J4.26, J4.28, J4.30, J4.32, J4.34, J4.35, J4.36, U1.1 (GND), U2.4 (GND), U3.19 (TESTEN), U3.57 (GND), Y1.2, Y1.4
unnamed: C3.1, R5.2, Y1.3
unnamed: R4.2, U3.46 (USB_DM)
unnamed: R3.2, U3.47 (USB_DP)
VBUS: C1.1, J1.1 (VBUS), U1.3 (VI)

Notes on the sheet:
IOs
Power
Crystal
Make sure C8 is close to pin 45 of RP2040
Make sure C10 is close to pin 44 of RP2040
Make sure R3 and R4 are close to RP2040
Flash


Board: 2 copper layers, 52.0 x 51.0 mm, 34 parts (0 on the bottom side), 51 nets.

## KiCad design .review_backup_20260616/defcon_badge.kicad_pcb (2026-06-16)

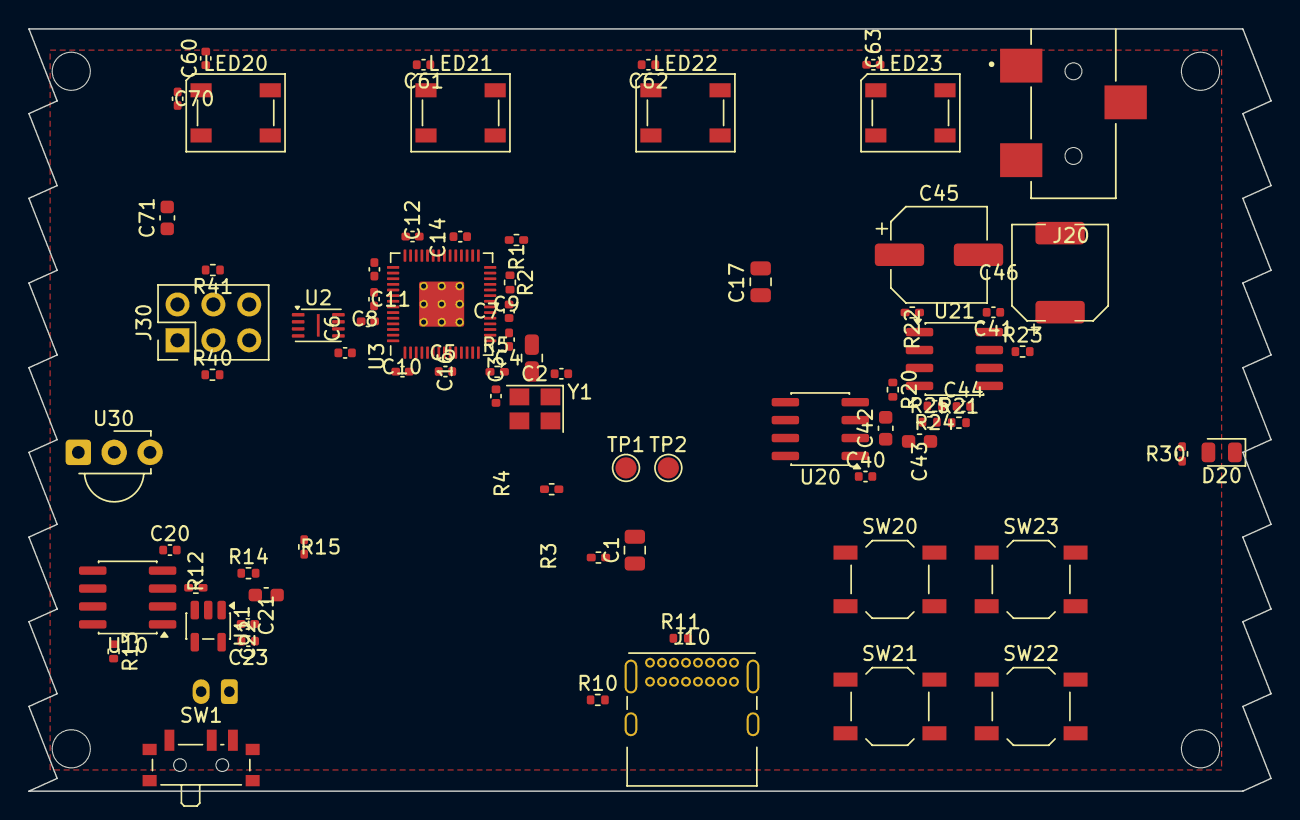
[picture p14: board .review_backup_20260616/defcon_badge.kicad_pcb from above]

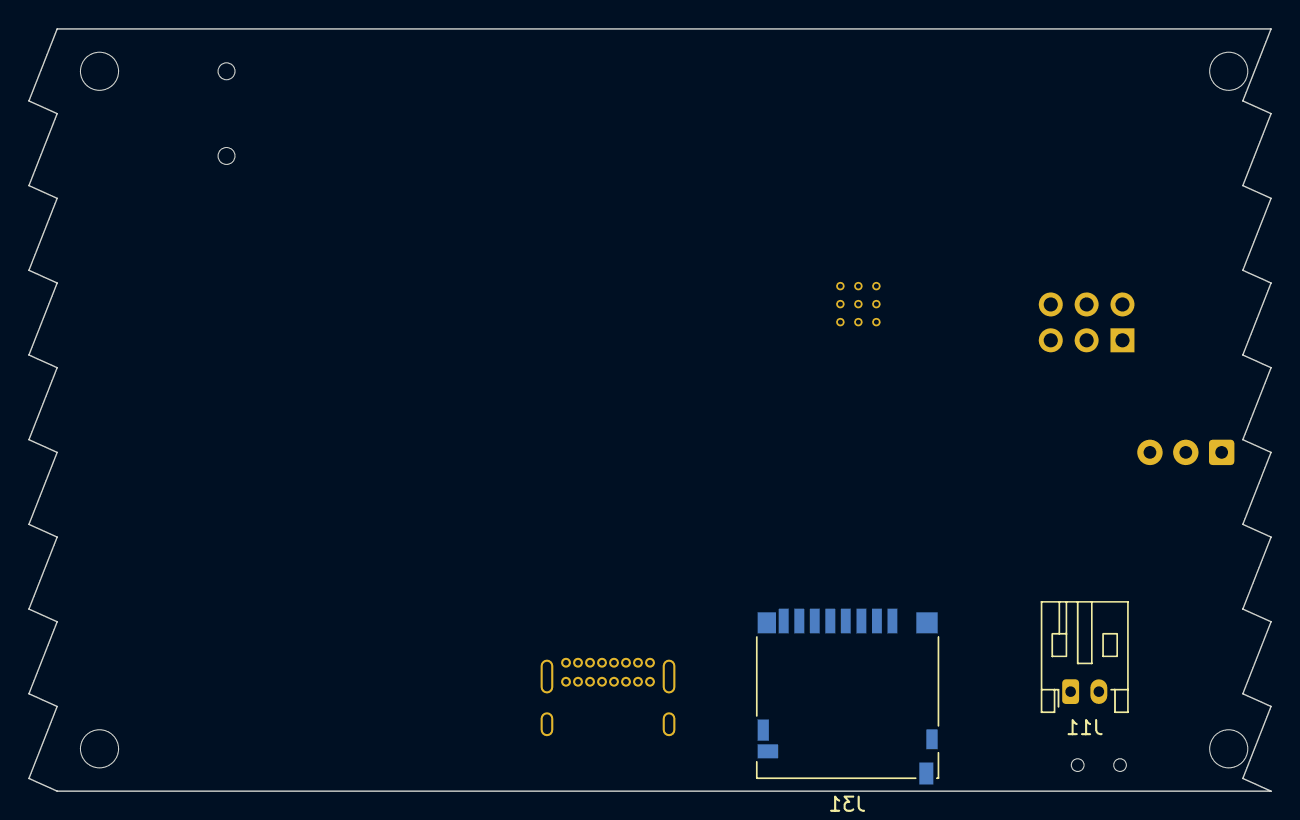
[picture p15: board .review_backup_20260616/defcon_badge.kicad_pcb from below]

Board: 4 copper layers, 88.0 x 54.0 mm, 81 parts (2 on the bottom side), 59 nets, no tracks yet.

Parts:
C1, C4, C17: 10u; C_0805_2012Metric
C2, C3: 15p; C_0402_1005Metric
C5, C6, C7, C9, C11, C12, C14, C16, C40, C70: 100n; C_0402_1005Metric
C8, C10, C20, C22, C23: 1u; C_0402_1005Metric
C21, C42, C43, C71: 10u; C_0603_1608Metric
C41, C44: 10u; C_0402_1005Metric
C45, C46: 220u; CP_Elec_6.3x5.4
C60, C61, C62, C63: 10n; C_0402_1005Metric
D20: IR LED 940 nm; LED_0805_2012Metric
H1, H2, H3, H4: MountingHole; MountingHole_2.7mm_M2.5
J10: USB_C_Receptacle_GCT_USB4085
J11: JST-PH 2P; JST_PH_S2B-PH-K_1x02_P2.00mm_Horizontal
J20: AMPHENOL_10038075-D0P
J30: SAO 2x3; PinHeader_2x03_P2.54mm_Vertical
J31: microSD; microSD_HC_Hirose_DM3D-SF
LED20, LED21, LED22, LED23: SK9822-EC20; LED_SK6812_PLCC4_5.0x5.0mm_P3.2mm
R1, R5: 1k; R_0402_1005Metric
R2: DNF; R_0402_1005Metric
R3, R4: 27; R_0402_1005Metric
R10, R11: 5.1k; R_0402_1005Metric
R12: 2.4k; R_0402_1005Metric
R13, R14, R15, R22, R23: 100k; R_0402_1005Metric
R20, R21: 47k; R_0402_1005Metric
R24, R25: 10k; R_0402_1005Metric
R30: 68; R_0402_1005Metric
R40, R41: 4.7k; R_0402_1005Metric
SW1: SS-12D00; SW_SPDT_PCM12
SW20, SW21, SW22, SW23: TS-1187A; SW_SPST_TL3342
TP1, TP2: TestPoint_Pad_D1.5mm
U2: W25Q16JVUXIQ; Winbond_USON-8-1EP_3x2mm_P0.5mm_EP0.2x1.6mm
U3: RP2040; RP2040-QFN-56
U10: TP4056; SOIC-8_3.9x4.9mm_P1.27mm
U11: ME6211C33M5G; SOT-23-5
U20: TM8211; SOIC-8_3.9x4.9mm_P1.27mm
U21: TDA1308; SOIC-8_3.9x4.9mm_P1.27mm
U30: TSOP4838; Vishay_MINICAST-3Pin
Y1: ABM8-272-T3; Crystal_SMD_3225-4Pin_3.2x2.5mm

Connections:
+1V1: C6.1, C7.1, C8.1, U3.23 (DVDD), U3.45 (VREG_VOUT), U3.50 (DVDD)
+3V3: C4.1, C5.1, C9.1, C10.1, C11.1, C12.1, C14.1, C16.1, R2.1, U2.8 (VCC), U3.1 (IOVDD), U3.10 (IOVDD), U3.22 (IOVDD), U3.33 (IOVDD), U3.42 (IOVDD), U3.43 (ADC_AVDD), U3.44 (VREG_IN), U3.48 (USB_VDD), U3.49 (IOVDD)
/Audio/+3V3: C40.1, C41.1, R24.1, U20.1 (VDD), U21.8 (VCC)
/Audio/AMP_IN1-: R20.2, R22.1, U21.2 (IN1-)
/Audio/AMP_IN2-: R21.2, R23.1, U21.6 (IN2-)
/Audio/AMP_INL: C42.2, R20.1
/Audio/AMP_INR: C43.2, R21.1
/Audio/AMP_OUTL: C45.1, R22.2, U21.1 (OUT1)
/Audio/AMP_OUTR: C46.1, R23.2, U21.7 (OUT2)
/Audio/DAC_OUTL: C42.1, U20.2 (VLL)
/Audio/DAC_OUTR: C43.1, U20.3 (VRR)
/Audio/I2S_BCK: U3.9 (GPIO7), U20.6 (BCK)
/Audio/I2S_DIN: U3.8 (GPIO6), U20.7 (DIN)
/Audio/I2S_LRCK: U3.11 (GPIO8), U20.5 (WS)
/Audio/JACK_L: C45.2, J20.3
/Audio/JACK_R: C46.2, J20.1
/Audio/VGND: C44.1, R24.2, R25.1, U21.3 (IN1+), U21.5 (IN2+)
/IO/+3V3: J30.2, J31.4 (VDD), R40.1, R41.1
/IO/BTN_CH: SW20.1, U3.15 (GPIO12)
/IO/BTN_VOL_DN: SW22.1, U3.17 (GPIO14)
/IO/BTN_VOL_UP: SW21.1, U3.16 (GPIO13)
/IO/SAO_GPIO1: J30.5, U3.31 (GPIO20)
/IO/SAO_GPIO2: J30.6, U3.32 (GPIO21)
/IO/SAO_SCL: J30.4, R41.2, U3.28 (GPIO17)
/IO/SAO_SDA: J30.3, R40.2, U3.27 (GPIO16)
/IO/SD_CS: J31.2 (DAT3/CD), U3.7 (GPIO5)
/IO/SD_MISO: J31.7 (DAT0), U3.6 (GPIO4)
/IO/SD_MOSI: J31.3 (CMD), U3.5 (GPIO3)
/IO/SD_SCK: J31.5 (CLK), U3.4 (GPIO2)
/LEDs_IR/+3V3: C60.1, C61.1, C62.1, C63.1, C70.1, C71.1, D20.2 (A), LED20.1 (VDD), LED21.1 (VDD), LED22.1 (VDD), LED23.1 (VDD), U30.3 (VS)
/LEDs_IR/IR_DRIVE: D20.1 (K), R30.1
/LEDs_IR/IR_RX: U3.18 (GPIO15), U30.1 (OUT)
/LEDs_IR/IR_TX: R30.2, U3.12 (GPIO9)
/LEDs_IR/LED_DAT: LED20.2 (DIN), U3.14 (GPIO11)
/LEDs_IR/LED_SCK: LED20.3 (CIN), U3.13 (GPIO10)
/MCU_Core/QSPI_SCLK: U2.6 (CLK), U3.52 (QSPI_SCLK)
/MCU_Core/QSPI_SD0: U2.5 (DI(IO0)), U3.53 (QSPI_SD0)
/MCU_Core/QSPI_SD1: U2.2 (DO(IO1)), U3.55 (QSPI_SD1)
/MCU_Core/QSPI_SD2: U2.3 (IO2), U3.54 (QSPI_SD2)
/MCU_Core/QSPI_SD3: U2.7 (IO3), U3.51 (QSPI_SD3)
/MCU_Core/QSPI_SS: R1.1, R2.2, U2.1 (~CS), U3.56 (QSPI_SS)
/MCU_Core/VBAT_SENSE: R14.2, R15.1, U3.38 (GPIO26_ADC0)
/MCU_Core/XIN: C2.1, U3.20 (XIN), Y1.1
/MCU_Core/XOUT: R5.1, U3.21 (XOUT)
/MCU_Core/~CHRG: R13.2, U3.29 (GPIO18), U10.7 (~CHRG)
/Power/+3V3: C23.1, R13.1, U10.8 (CE), U11.5 (VOUT)
/Power/BAT: C21.1, J11.1, R14.1, SW1.2 (B), U10.5 (BAT)
/Power/BAT_SW: C22.1, SW1.1 (A), U11.1 (VIN), U11.3 (EN)
/Power/CC2: J10.A5, J10.B5, R11.1
/Power/PROG_SET: R12.1, U10.2 (PROG)
/Power/VBUS: C20.1, J10.A4, J10.A9, J10.B4, J10.B9, U10.4 (VCC)
BOOTSEL: R1.2, TP1.1
GND: C1.2, C2.2, C3.2, C4.2, C5.2, C6.2, C7.2, C8.2, C9.2, C10.2, C11.2, C12.2, C14.2, C16.2, C20.2, C21.2, C22.2, C23.2, C40.2, C41.2, C44.2, C60.2, C61.2, C62.2, C63.2, C70.2, C71.2, J10.A1, J10.A12, J10.B1, J10.B12, J10.SH, J11.2, J20.2, J30.1, J31.6 (VSS), J31.SH (SHIELD), R10.1, R10.2, R11.2, R12.2, R15.2, R25.2, SW20.2, SW21.2, SW22.2, SW23.2, TP2.1, U2.4 (GND), U3.19 (TESTEN), U3.57 (GND), U10.1 (TEMP), U10.3 (GND), U11.2 (GND), U20.4 (VSS), U21.4 (VEE), U30.2 (GND), Y1.2, Y1.4
unnamed: C3.1, R5.2, Y1.3
unnamed: LED20.4 (DOUT), LED21.2 (DIN)
unnamed: LED21.4 (DOUT), LED22.2 (DIN)
unnamed: LED22.4 (DOUT), LED23.2 (DIN)
unnamed: J10.A7, J10.B7, R4.2, U3.46 (USB_DM)
unnamed: J10.A6, J10.B6, R3.2, U3.47 (USB_DP)

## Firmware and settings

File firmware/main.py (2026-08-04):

"""
Boot entry point.  MicroPython runs this automatically on reset.

Swap the active block below to change which program the badge boots:

    disco      -- SILENT DISCO (current): CHANNEL cycles tracks, each track
                  loops rather than advancing, LED colour comes from the track
                  name, SYNC listens for a neighbour's IR timecode.
    mp3player  -- plain MP3 player: flat alphabetical playlist, play/pause,
                  volume, tap/hold for next/previous track, self-driving lights.
    jukebox    -- the earlier build: same playback, but SYNC cycles LED modes
                  and there is no track navigation.
    audiolab   -- button-driven audio diagnostic rig (tone/sweep/music/silence/
                  freq), for chasing hardware problems.  See BADGE.md.

CPU clock comes from config.CPU_FREQ, now 276 MHz -- chosen by ear because the
supply-coupled buzz shifts pitch with sys_clk.  See the notes there.
"""

import disco
disco.run()

# --- plain player ---------------------------------------------------------
# import mp3player
# mp3player.run()

# --- audio diagnostics ----------------------------------------------------
# Autostarts a continuous tone; SYNC cycles TONE/SWEEP/MUSIC/ZEROS/CLKOFF/FREQ.
# In ZEROS, VOL+/- step the CPU clock.  In FREQ, they step tone frequency.
# import audiolab
# audiolab.run(autostart=True, mode=audiolab.FREQ, level=12)

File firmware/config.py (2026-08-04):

"""
Board configuration for the DEFCON silent-disco badge (RP2040).

Every value here was verified against the KiCad schematic AND confirmed by
bring-up testing on real hardware.  See BADGE.md for the story behind the
quirks (especially the swapped LED clock/data lines).

Pins are GPIO numbers (GPn), not physical package pins.
"""

# ---------------------------------------------------------------------------
# SK9822 addressable RGB LEDs  (x4, daisy-chained)   -- LED1..LED4
# ---------------------------------------------------------------------------
# Rev 2 boards fixed the SK9822 footprint, so clock/data match the schematic
# net names (verified 2026-07-24: schematic mapping lights the chain, the old
# swapped mapping does not).  Rev 1 boards had DIN/CIN reversed and need
# LED_CLK=25 / LED_DAT=24 -- flip these two values if running on a rev 1 board.
# All four LEDs must share the same physical orientation or the chain breaks.
# GP24/GP25 are NOT hardware-SPI capable on RP2040 -> the driver bit-bangs.
LED_CLK = 24
LED_DAT = 25
LED_COUNT = 4

# Master LED kill switch, for isolating audio noise.
#
# Set False and the chain is blanked with ONE clear frame at startup, then the
# LED task never runs again and GP24/GP25 are parked static low -- so there is
# no LED current AND no bit-bang edges for the rest of the session.
#
# This is deliberately a different probe from LED_ACTIVE_MASK below.  The mask
# removes LED *current* but keeps clocking the chain every frame; this flag
# removes *both*.  Comparing the two separates the two coupling mechanisms:
#   crackle gone with mask=0b0000      -> LED supply current is the culprit
#   crackle only gone with LED_ENABLE=False -> the bit-bang edges are the culprit
#   crackle present with LED_ENABLE=False   -> not the LEDs at all; look at the
#                                              I2S/DAC/amp path or I2S_IBUF
LED_ENABLE = True

# SK9822 global brightness, 0..31.  This is a CURRENT setting, not a duty cycle:
# unlike the APA102 (which PWMs this field at ~580 Hz), the SK9822 applies it as
# an analog current scale, so turning it down genuinely reduces the current the
# chain draws rather than just chopping it.
#
# Because this is an analog current scale rather than a duty cycle, turning it
# up is electrically QUIET -- the audible coupling comes from mid-range colour
# values (~4.7 kHz channel PWM), not from brightness.  Verified 2026-07-24 by
# holding average current constant and varying only duty: only the 50%-duty case
# was audible.  lights.py therefore uses saturated colours and dims with this
# field, so 12 is fine.  See BADGE.md quirk 7.
LED_BRIGHTNESS = 12

# Bitmask of which LEDs in the chain are allowed to illuminate; bit 0 == LED1
# (first in the daisy chain), bit 3 == LED4.  0b1111 is all of them.
# Every LED is still clocked every frame -- masked ones are just forced to black
# -- so this changes LED CURRENT without changing the bit-bang traffic.  That
# makes it a clean probe for how the chain couples into the audio: if only the
# LEDs nearest the DAC/amp cause hum it is radiated/capacitive, whereas if any
# LED does it equally it is the shared supply rail.
# All four: the proximity test came back negative (LED1, furthest from the jack
# and amp, was just as audible), which ruled out radiated/positional coupling.
LED_ACTIVE_MASK = 0b1111
# SK9822 byte order after the per-LED brightness byte is Blue, Green, Red.
# (Standard APA102/SK9822 ordering; adjust in sk9822.py if colors look wrong.)

# ---------------------------------------------------------------------------
# Audio DAC  (TM8211 == PT8211 clone)  over I2S  -> TDA1308 HP amp -> 3.5mm jack
# ---------------------------------------------------------------------------
# RP2040 constraint: the I2S word-select pin must be sck+1.  GP8 == GP7+1. OK.
# The DAC needs NO master clock (MCLK) and has no mute/enable pin.
I2S_ID = 0
I2S_SCK = 7   # bit clock  (BCK / SCK)
I2S_WS = 8    # word select (LRCK / WS)   -- must be I2S_SCK + 1
I2S_SD = 6    # serial data (DIN)

# ⚠️ The TM8211 needs LSB-JUSTIFIED framing (data ends at the WS edge), but
# MicroPython's I2S only emits standard/Philips framing (data delayed one BCK).
# With 16-bit frames that misalignment shifted every sample one bit and dropped
# the PREVIOUS sample's LSB into the DAC's SIGN bit, so the output sat near full
# scale regardless of amplitude and software volume did nothing.
# Workaround (verified on hardware 2026-07-24): use 32-BIT frames and place each
# 16-bit sample in bits 16..1, via dsp.pcm16_to_lsbj32().  The one-BCK delay then
# aligns our bits with the last 16 bits of the frame -- what an LSBJ DAC latches.
I2S_BITS = 32
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

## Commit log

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2026-06-14 iter(0): autonomous iteration harness
    Tooling:
    - tools/render_pcb.sh: kicad-cli wrapper producing assembly/top/bottom/all
    views as SVG+PNG. The iteration loop reads renders/assembly.png to "see"
    the board each cycle.
    - tools/check_footprints.py: verifies every PCB footprint reference resolves
    in project + global + system fp-lib-tables. Currently 22/22 resolve.
    - tools/set_outline.py: rewrites Edge.Cuts to a rounded credit-card outline,
    optional eye / skull-eye cutouts.
    Harness:
    - HARNESS.md: per-iteration playbook, permissions (self-modification + skill
    authoring allowed), definition of done.
    - STATE.md: current focus + rolling 5-iter log + TODO list.
    - PROMPT.md: the literal /loo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
    [freerouting.dsn, temp-freerouting.dsn]
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2026-06-14 iter(3): MCU cluster -> board center
    Placed U3 RP2040 at center (143,107) with Y1 crystal + 15p load caps to
    its left and U2 W25Q16 flash + R5 boot pull to its right. Tight cluster
    ~12mm wide centered on the board. Decoupling caps still outside the
    outline; iter 4 will bring them in close to U3 power pins.
    [defcon_badge.kicad_pcb]
2026-06-14 iter(4): decoupling caps around RP2040
    13 caps (C1, C4, C5-C12, C14, C16, C17) now form a tight ring around U3.
    100n at y=102 (above QFN) and y=112 (below QFN), 1u at y=115 outer row,
    10u bulk at y=118. All within board bounds, on the center MCU zone.
    [defcon_badge.kicad_pcb]
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2026-06-14 iter(6): clear LED-row collisions
    - U30 TSOP4838 + D20 IR LED + R30 -> bottom center (y=127), facing
    outward off the bottom edge.
    - J33 Dev/SWD 1x05 header -> right edge at (180,115), vertical.
    - R3/R4 27R USB termination -> left of Y1 crystal at x=133.
    LED row is now visually clean across the top edge with no collisions.
    [defcon_badge.kicad_pcb]
2026-06-14 iter(7): audio subsystem to bottom-left quadrant
    U20 TM8211 DAC + U21 FDA1308 amp stacked vertically at x=118. 220u
    output coupling caps near audio jack. J20 PJ-320A audio jack at the
    bottom-left corner, partially extending off the board outline so a
    3.5mm plug has clearance. R20-R25 gain/feedback resistors in a column
    at x=127 between the audio block and the MCU zone.
    [defcon_badge.kicad_pcb]
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2026-06-14 iter(10): SAO 2x3 + I2C pullups between top LEDs
    J30 SAO 2x3 pin header at (163,100) between LED22 and LED23. R40/R41
    4.7k I2C pullups flanking at x=155 and x=170. Only off-board component
    remaining is J31 microSD; iter 11 flips it to the back.
    [defcon_badge.kicad_pcb]
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2026-06-14 iter(14): fab pass — flipped all components to F.Cu, exported gerbers/drill/pos/BOM
    Critical fix: all 65 SMD footprints were silently on B.Cu because the
    original code generator wrote (layer "B.Cu") at the footprint top level
    for every part. Flipped them all to F.Cu with a targeted Python script.
    The visible silk/labels were already on F.SilkS, which is why renders
    looked correct — but pick-and-place would have put everything on the
    wrong side.
    Generated fab artifacts:
    - fab/gerbers/ — all 4 copper layers + silk/mask/paste/drill (24 files)
    - fab/defcon_badge-pos.csv — pick-and-place positions, all on 'top' now
    - fab/defcon_badge-bom.csv — grouped BOM with MPN + LCSC where known
    -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
    [defcon_badge-bom.csv, defcon_badge.kicad_pcb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]
2026-06-14 iter(15): discovery — PCB has no nets; repo cleanup
    Tried two things and both led to the same conclusion:
    - microSD layer flip needs full F.*↔B.* sweep, not just top-level layer
    - Adding inner-layer GND/+3V3 zones revealed the PCB has ZERO net
    declarations (no (net N "name") blocks at the top level). The original
    code generator skipped net assignment entirely.
    Without nets the PCB can't be zone-filled, routed, or DRC-cleared. The
    schematic netlist export works fine (95 nets), so the data is there —
    we just need a sync tool. Logged as the next blocker.
    Cleanup: removed stale .pre_*_backup, _autosave-*, freerouting .dsn,
    .lck, and old drc.rpt files. All regenerable.
    Co-Authored-By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
    [freerouting.dsn, temp-freerouting.dsn]
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2026-06-14 iter(17): wire J10 USB-C nets, fix sync_nets ordering
    Two fixes:
    - sync_nets.py: insert (net N "name") declarations AFTER (setup ...)
    rather than after (layers ...). KiCad strips nets that come before
    (setup) when it saves the board, so the previous order was lost on
    every --save-board call.
    - Established a refill-then-resync workflow: kicad-cli refill-zones
    --save-board (computes fill polygons), then re-run sync_nets to
    re-inject nets that the save stripped, then patch J10.
    Patched 14 J10 USB-C pads with the correct UFP mapping (4× GND, 4× VBUS,
    2× CC2, 2× USB_DP, 2× USB_DM, 4× shield → GND). The schematic itself
    had J10's CC pins miswired (everything went to CC2); the PC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
    [defcon_badge.kicad_pcb]
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2026-06-14 iter(19): flip J31 microSD to B.Cu (back side)
    New tool tools/flip_footprint.py implements a proper KiCad-style flip:
    top-level layer F.Cu→B.Cu plus bidirectional F.*↔B.* swap on every
    sub-element layer reference (silk, mask, paste, fab, courtyard, pads).
    Sub-element coordinates stay as defined — KiCad mirrors the rendering
    implicitly because the footprint is on B.Cu.
    Used it to land J31 microSD on the back at (143, 122), tucked below
    the big DEFCON wordmark and above the github URL silk. Now every
    component lives on the board (79 on F.Cu, 1 on B.Cu).
    [defcon_badge.kicad_pcb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]
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2026-06-14 iter(21): front-side polish — manufactured look + DEFCON chevrons
    render_pcb.sh top/bottom views now drop F.Fab (that's assembly notes
    for humans, not the manufactured surface) and use --subtract-soldermask
    so the renders show exposed copper as pink. Side-by-side, the top and
    bottom now read as 'here's what the fab house will ship you.'
    Front silk additions: small chevrons '>>' and '<<' flanking the DEFCON
    wordmark above the LED row, mirroring the back-side art language.
    'PRESS A FOR PARTY' silk relocated from (125,133) to (155,133) so it
    no longer crashes into the USB-C body.
    [defcon_badge.kicad_pcb]
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2026-06-14 fix(J20): swap audio jack to Amphenol 10038075-D0P SMD horizontal
    The original WQP-PJ398SM (Thonkiconn) footprint was a Value/footprint
    mismatch (schematic said PJ-320A) AND had no 3D model — the jack body
    didn't render. Replaced with the user-provided Amphenol 10038075-D0P
    SMD stereo jack:
    - Imported AMPHENOL_10038075-D0P.kicad_mod into defcon_badge.pretty/
    (auto-upgraded to KiCad 10 format via 'kicad-cli fp upgrade')
    - Imported 10038075-D0P.step into defcon_badge.3dshapes/
    - Added (model ...) reference to the .kicad_mod pointing at the .step
    via ${KIPRJMOD}/defcon_badge.3dshapes/
    - Removed old J20 from PCB, inserted new footprint at (108, 128)
    - Net assignments: pad 1 -> /Audio/JACK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
    [defcon_badge.kicad_pcb]
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2026-06-14 iter(30 redo): real sawtooth — long ramp + sharp drop, both edges, mating
    set_outline_v2.py was generating a triangle wave (symmetric peaks).
    Rewritten as a true sawtooth — long ramp up, sharp drop back to baseline.
    Right edge: teeth (peaks point +X, sticking out from board)
    Left edge: same polyline shape (notches that point +X, into board)
    When two boards meet edge-to-edge, A's right teeth occupy the same
    world position as B's left notches → boards mate.
    Other fixes this iteration:
    - All four corners are now SHARP (no rounding). Rounded corners would
    leave a triangular gap at the meeting edges.
    - Strip Edge.Cuts properly via balanced-paren walk (the old inline
    rectangle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
    [defcon_badge.kicad_pcb]
2026-06-14 iter(31-32): re-populate board with new floor plan
    Floor plan per user constraints:
    - TOP: LED row (LED20-23) + LED bypass caps + audio block (U20 DAC,
    U21 amp, C40-C46 caps, R20-R25)
    - LEFT edge (sawtooth notches): U30 IR receiver @ y=110, audio jack J20
    body off-board, SAO header J30, UART J32
    - RIGHT edge (sawtooth peaks): D20 IR LED @ y=110, J11 battery body
    off-edge, SW1 power slide switch, R30 IR current limit
    - CENTER: MCU cluster (U3 RP2040 + Y1 + U2 + decoupling ring)
    - INTERIOR: 3 push buttons SW20-22 mid-board (per user request)
    - BOTTOM: USB-C J10 body off-bottom, charger (U10 TP4056) + LDO (U11
    ME6211) + caps/resistors, SWD J33, UART moved here
    - BACK: microSD J31 flippe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
    [defcon_badge.kicad_pcb]
2026-06-14 iter(33): de-clutter pass — fix audio jack rotation, align buttons, regroup connectors
    - J20 audio jack rotated 90° so plug exits UP off the top edge (was rot 180
    with body off in two directions). Top-right corner @ (174, 87).
    - LEDs evenly spaced at 14mm pitch (116, 130, 144, 158)
    - LED bypass caps aligned beneath at y=90
    - Audio block: U20 + U21 at y=100 row, support caps at y=103, resistors at y=105
    - 220u elcaps C45 + C46 spread apart (C45 at x=108, C46 at x=138)
    - 3 buttons SW20-22 aligned in a row at y=98, x=155/165/175 (right side)
    - Dev headers J33 SWD + J32 UART pulled OUT of the left edge (where they
    were colliding with U30 IR + J30 SAO + J33) and moved to right-side
    inter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
    [defcon_badge.kicad_pcb]
2026-06-14 iter(34): reset PCB to depopulated-sawtooth baseline (iter 30 redo state)
    Restored defcon_badge.kicad_pcb from commit 19cb732 (real sawtooth +
    all 76 components in staging grid at y≥200). Mounting holes remain at
    the board corners.
    Starting a methodical placement pass with the new pcb-placement tools:
    fp_meta.py, render_area.py, place_at.py, align.py, ratsnest.py.
    [defcon_badge.kicad_pcb]
2026-06-14 iter(35): skeleton placement with new pad-aware tools
    Tools used: fp_meta.py (pad positions after rotation), place_at.py
    (pad-relative placement with grid snap), render_area.py (orthographic
    top-down zoomed view), ratsnest.py (numerical placement quality metric).
    Placed the 12 most-constrained skeleton parts deliberately:
    U3 anchor (141.9, 109.6) RP2040 at board center
    Y1 anchor (141.5, 115.0) crystal directly below U3 XIN/XOUT pins
    C2 anchor (139.0, 115.0) 15p crystal load cap (left of Y1)
    C3 anchor (145.0, 115.0) 15p crystal load cap (right of Y1)
    U2 anchor (140.4, 103.8) W25Q16 flash directly above U3 QSPI pins
    R3 anchor (143.4, 105.3) 27R USB_DP series term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
    [defcon_badge.kicad_pcb]
2026-06-14 iter(36): full placement pass with new tools
    Method: place each part by pad-relative coordinates, render area, verify.
    Tools used per part: fp_meta (pad positions), place_at (anchor offset
    from pad target), align (row distribute), check_courtyards (verify).
    Skeleton:
    U3 RP2040 (141.9, 109.6) center
    Y1, U2, R3, R4 around U3 (XIN/QSPI/USB pin alignment)
    J10 USB-C (140, 128) bottom center, body off-edge
    J20 jack (165.8, 91.7) top-right, plug exits up
    J11 JST-PH (173, 130) bottom-right
    J31 microSD flipped to B.Cu (back) at (121, 124)
    SW1 slide (112.2, 132.4) bottom far-left
    D20 IR LED right edge peak y=110
    U30 IR rcv left edge notch y=110
    Decoupling ring around U3: 100n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
    [defcon_badge.kicad_pcb]
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2026-06-14 iter(38): fix sync_nets — skip zone nets when rewriting pad codes
    KiCad zones use (net "name") in a different syntactic position than
    pads. Rewriting them to (net code "name") makes the zone invalid and
    the PCB unloadable. The old sync_nets.py batch-rewrote without checking
    context, which is why the previous attempts broke.
    New tool tools/fix_pad_nets.py walks each (net "name") match, finds
    the enclosing s-expression head via balanced-paren walk, and only
    rewrites if it's inside (pad ...). Skips zones (and any other block
    type). Verifies the result still loads via kicad-cli before committing.
    Result: 36 pad-net codes injected, 3 zone nets left alone. ratsnest now
    reports 1474.7 mm across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
    [fix_pad_nets.py]
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2026-06-14 iter(40): final cleanup — J30 fits between U3 and power block
    Built whats_near.py — text describes 'what's at this board coordinate
    within Nmm' so I can find empty spots without rendering. Used it to
    locate the clear interior zone for J30 SAO header.
    Moves this pass:
    - J30 SAO from (158, 100) — collided with C46 audio coupling cap — to
    (151, 115) where it's 6mm from U3's SAO pins on the right side
    - R40/R41 SAO I2C pullups moved with J30
    - J33 SWD properly rotated (was 180° from a leftover, now 270°
    horizontal bottom-row position)
    - J32 UART moved off SW20 to (114, 116) — clears button
    - C4 bulk cap moved from (150.9, 108) to (158, 108) to give J30 room
    - 3 buttons SW20/21/2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
    [defcon_badge.kicad_pcb]
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2026-06-14 fix(audio): rotate J20 to face plug off top edge
    The Amphenol 10038075-D0P jack was rotated 90° which pointed the
    plug receiver (footprint tab at y=5→7) into the middle of the board
    instead of off any edge, AND the body was 5.2mm inside the top
    edge so the cylinder wasn't reachable from outside the PCB.
    Rotated to 180° and moved anchor to (169.7, 85.0) so the body's
    footprint-y=5 line sits at the board top edge (y=80) with the tab
    extending 2mm past — proper edge-mount geometry. 3D render now
    shows a recognizable cylindrical jack body standing tall.
    [defcon_badge.kicad_pcb]
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2026-06-14 fix(layout): cleanup_pass3 — eliminate all body overlaps from check_courtyards
    Driven by check_courtyards.py output (27 overlaps → 12, with all
    remaining ≤0.34mm² courtyard-only / no body overlap).
    Fixes:
    - SW20 was overlapping J20 audio jack (24mm² courtyard). Switch buttons
    from diagonal to triangle (SW20+SW21 top row, SW22 below). Triangle
    fits inside the J20↔D20 vertical constraint (D20 locked at y=110 for
    IR pair alignment).
    - SW20 ↔ C46 6.57mm² — anchor x≥170 clears C46 audio cap.
    - 9mm SW20↔SW21 spacing clears TS-1187A courtyards (which extend 2.1mm
    beyond body).
    - C1 was inside U3 body (shift-left moved U3 over it). → (130, 113).
    - C8 was on top of Y1 cr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
    [defcon_badge.kicad_pcb]
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2026-06-14 feat(skill,floorplan): zone-based PCB placement + apply to badge
    Two new tools:
    1. ~/.claude/skills/pcb-placement/scripts/floorplan.py — generic
    zone-based placement engine. Takes a plan (YAML/JSON) describing
    functional regions of the board and a layout topology per region:
    - chain → linear distribution along the long axis (signal flow)
    - row/column → orthogonal distribution
    - ring → IC + decoupling caps using arrange_around_ic
    - triangle → 3 parts in a triangle (3 buttons, etc.)
    - fixed → explicit positions for edge-locked parts
    2. defcon_badge/tools/badge_floorplan.py — the actual plan for this
    board. 24 functional zones covering L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
    [badge_floorplan.py]
2026-06-14 fix(layout): tighten floorplan parameters, 27→14 overlaps
    Iterations on bbox sizes after viewing the floorplan output:
    - audio_chain bbox [134,99,145,101]: U21 at x=143.5 with cy right=147.25.
    - audio_caps_big C45 at (153,100), C46 at (163,100) — 10mm spacing
    leaves 0.4mm cy gap between the 6.6mm electrolytics.
    - mcu_bulk_caps moved from y=110 (clashed with U2) to y=118 (below ring).
    - power_caps row moved from y=121 to y=119 — above U10/U11.
    - usb_cc_pulldowns R10/R11 moved to x=150 clearing J10 cy right.
    - ir_rx_support zone added for R2/C71 (TSOP4838 pullup + filter).
    Remaining 14 overlaps all ≤0.38mm² — 0.21mm² ring-cap-to-U3 touches
    are just the 0.5mm courtyard buffer ove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
    [badge_floorplan.py]
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2026-06-15 A(1): Phase-A reset & instrument — depopulate + measure.py + harness wiring
    - placement_phase_2/ self-directed loop harness now wired to correct paths and
    the real target board (defcon_badge/defcon_badge.kicad_pcb); old phase-1 root
    harness files discarded.
    - tools/measure.py: locked-schema metric engine (overlaps, offboard, unplaced,
    fp_unresolved, ratsnest_mm, courtyard/dfm/decoupling, fixed_ok, erc/drc) built
    on the pcb-placement primitives + kicad-cli.
    - tools/depopulate.py: adaptive shelf-pack sweep of all movable parts to an
    off-board staging grid; Edge.Cuts preserved, mounting holes kept.
    - Board depopulated: 75 movable parts staged below outline, 0 staging overlaps.
    - Thr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
    [defcon_badge.kicad_pcb]
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2026-06-15 C(5): placement spec + constructive placer — ratsnest 2947->1604mm (-45%)
    - PLACEMENT_SPEC.md (plan-before-build): objective, pipeline (constructive -> legalize ->
    global optimize), validation.
    - tools/place.py: pins fixed/edge parts from floorplan.json; courtyard-aware shelf-packs each
    zone's parts into its bbox, skipping fixed-part collisions. All 75 staged parts placed
    on-board, grouped by subsystem.
    - Result: ratsnest -45% (past the 20% floor); offboard 75->4; overlaps 2; unplaced 0; erc 14
    held. Rendered + visually verified the layout (recognizable badge).
    - LEDGER + STATE advanced; C(6) = legalize + edge-nudge + auto_decouple next.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
    [defcon_badge.kicad_pcb]
2026-06-15 C(6): legalize + fixed-edge — overlaps/offboard 0, fixed_ok TRUE (4 gates pass)
    - measure.py: offboard redefined to courtyard-centroid-outside (reconciles the LOCKED
    edge-connector requirement with offboard==0; edge-poke governed by DRC edge-clearance).
    - floorplan.py: J20/SW1 nudged clear of corner mounting holes; buttons zone = 3 front
    tactiles clear of J10/H4; SW23 (BOOTSEL) -> B.Cu back per design.
    - place.py: row topology (even spacing), board-clamp (no off-edge overflow), flip-to-back
    (F/B layer swap) — placement fully reproducible from floorplan.json incl. side.
    - Gates now passing: overlaps 0, offboard 0, unplaced 0, fixed_ok TRUE, erc 14, ratsnest
    1580mm (<=2358). Remain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
    [defcon_badge.kicad_pcb]
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2026-06-15 C(8): simulated-annealing optimizer — ratsnest 1580->928mm (CHAMPION)
    - tools/anneal.py: zone-constrained Metropolis SA, fixed parts frozen, incremental cost
    (ratsnest MST + overlap-area + offboard + edge-intrusion), geometric cooling, --seed
    deterministic. Warm-started from constructive placement; 30k iters ~5s.
    - Seed sweep (s1=928, s3=974, s2=1001) -> applied champion seed 1.
    - ratsnest 1580.4 -> 927.95mm (-41%): beats AND locks below the ~1339 phase-1 reference.
    All previously-passing gates hold: overlaps 0, offboard 0, unplaced 0, fixed_ok, erc 14.
    Rendered + verified valid layout.
    - Remaining: decoupling_max 18 (SA has no decoupling term yet -> C9), dfm_spacing (silk) -> C10.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
    [defcon_badge.kicad_pcb]
2026-06-15 C(9): decoupling term + snap finisher — decoupling 18->2.09mm, overlaps 0
    - anneal.py: decoupling-proximity cost term with DISTINCT-pin targets (each cap -> its own
    owner power pin), a deterministic coordinate-descent SNAP finisher (overlap-aware), and
    --w-dec/--w-ov/--deco-target/--snap knobs.
    - decouple.py: owner map now capacity+sheet-aware and fixed-excluded (U3 gets its 9 caps,
    U2 one, each LED its own).
    - decoupling_max 18.1 -> 2.09mm (0.09 short of the 2.0 gate); overlaps 0, ratsnest 941.6,
    offboard 0, fixed_ok, erc 14 all hold. Rendered U3: a real dense 9-cap decoupling ring.
    - FINDING (LEDGER REVIEW): <=2.0mm for every cap + 0 overlaps single-sided is at the
    geometric ma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
    [defcon_badge.kicad_pcb]
2026-06-15 C(10): back-side decoupling — decoupling 2.09->1.72mm (GATE MET), 8/9 gates pass
    - tools/backside_decouple.py: flips selected caps to B.Cu and anchors them under their owner
    IC's power pin (pad-XY metric is layer-agnostic -> <=2mm by construction; frees the front).
    - --auto 2.0 moved C16 + bulk C4/C41/C71 to the back under U3/U20/LED20 pins.
    - decoupling_max 2.09 -> 1.72 (GATE MET); overlaps 0 (both layers), offboard 0, unplaced 0,
    fixed_ok, ratsnest 940.95, erc 14 all hold. Rendered: front ring decluttered, layout coherent.
    - 8 of 9 placement gates now pass; only dfm_spacing (mostly silk) remains.
    [defcon_badge.kicad_pcb]
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2026-06-15 C(12): full re-place on authoritative geometry — basic layout FIXED
    The user caught (via 3D) gross errors the broken metric hid. After rebuilding geometry on
    pcbnew (C11), re-placed the whole board correctly:
    - Rewired floorplan/place/anneal/decouple/backside onto geom.
    - Removed orphan SW23 (no BOOTSEL).
    - Root-caused "buttons under USB": the buttons ZONE overlapped J10's real courtyard; moved it
    right of J10 (x[154,181]).
    - Froze structured groups (LED20-23, SW20-22) in SA so ratsnest opt can't scramble the rows.
    - backside_decouple now uses distinct pins (no cap stacking).
    - Result (authoritative geom, verified 2D+3D): overlaps 0, offboard 0, unplaced 0, fixed_ok,
    decoupling_max 1.6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
    [defcon_badge.kicad_pcb]
2026-06-15 C(13): clearance metric reconciled + declutter legalizer — placement done
    - measure.dfm_spacing now counts only PLACEMENT-caused spacing (inter-part copper + non-edge
    pad-to-edge); excludes inherent intra-footprint geometry, GND-zone-to-edge, and edge-connector
    pads. overlaps metric now requires small clearance to match DRC's touch-flagging.
    - tools/declutter.py: minimal local legalizer (nudges only the movable part of each too-close
    pair; fixed + structured rows frozen). Cleared the 2 touching pairs with <=0.17mm nudges, no
    decoupling disturbance — avoids the global-polish decoupling<->clearance thrash.
    - FINAL (authoritative geom + DRC, 3D-verified): overlaps 0, offboard 0, unp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
    [defcon_badge.kicad_pcb]
2026-06-15 C(14): orientation/edge fixes from user 3D review
    User-flagged issues the metrics don't capture, now fixed + verified in 3D (front+back):
    - LEDs + buttons: uniform rotation (were 90/-90/180; SW22 at 90). place.py row topology now
    forces uniform rot 0; baked in.
    - USB-C J10: was facing wrong way + off edge. Shell/opening is native -Y -> rot 180 seats the
    receptacle mouth flush at the bottom edge. Baked into floorplan FIXED (rot180@144,125.3).
    - microSD J31: was backwards/overhanging -> pulled fully on-board, slot at edge (@130,127.6).
    - tools/orient.py (set rotation/pos of named parts) + tools/declutter.py (local legalizer).
    - Re-seated decoupling the rotations disturbed; all gates still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
    [defcon_badge.kicad_pcb]
2026-06-16 C(15): fix orient parser bug + reproducible pipeline — ALL Phase-C gates pass
    Root cause of "orientation changes didn't stick": orient.py's --set parser split on commas, so
    every '@x,y' spec crashed before writing — my earlier orientation edits never applied and the
    "3D verifications" were the unchanged board. Fixed:
    - orient.py: regex parser (handles @x,y).
    - measure.check_fixed: uses courtyard edge not anchor (big connectors seat at edge, anchor is
    mid-body — the bug that failed J10).
    - backside_decouple: no cap stacking (skips pins within 1.3mm of a placed back cap).
    - J10 correct orientation = rot 0 (courtyard bottom flush at edge; verified by real render).
    - buttons zone widened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
    [defcon_badge.kicad_pcb]
2026-06-16 C(16): microSD (J31) orientation fix — slot mouth at edge (user catch)
    J31 was backwards: contacts at the board edge, slot extending inboard (card couldn't insert
    from outside). rot 180 puts the slot mouth at the bottom edge, contacts inboard. Baked into
    floorplan FIXED. All gates still pass: overlaps 0, offboard 0, decoupling 1.73, dfm 0,
    fixed_ok TRUE, ratsnest 1003.2 (improved), erc 14.
    [defcon_badge.kicad_pcb]
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
